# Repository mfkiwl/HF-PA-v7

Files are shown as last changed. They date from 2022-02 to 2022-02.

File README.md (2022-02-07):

### HF-PA-v3

VU3CER's Robust `Class-C / Class-D HF PA` for https://github.com/kholia/Easy-Digital-Beacons-v1
project for 40-20-17-15-12-10m bands - powered by RD16HHF1 RF MOSFET.

This design aspires to be the standard mW-to-QRP-Gallon HF PA in the ~1100 INR
(15 USD) design space.

If you are looking for a ~600 INR IRF510 design, please check out the
https://github.com/kholia/HF-PA-v5 project.

Design Constraints:

- PCB is to be homebrewed.

- PCB is single-sided - only one layer (side) is available for routing work.

- The "finals" MOSFET needs to be on an edge to allow usage of heatsinks.

- Typical external linears (e.g. `PA150 HF Linear Amp`) need 2W minimum to
  function. So we need a minimum of 2W of RF output from our design - even at
  28 MHz (10m).

- Minimal part count is strongly preferred. Low cost, and ease of availability
  are strong driving and deciding factors.

- Reproducibility is a MUST! We focus a lot on this aspect by documenting each,
  and every detail possible.

- Repairability in the field is a MUST!

  Dhiru's finding: Repairing homebrewed PCBs is so much easier, and fun than
  reworking commercial `lead-free` PTH PCBs.

- No moving mechanical parts are allowed in the design - this rules out usage
  of (failure-prone) active cooling options like fans.

Input: Few milliwatts is fine. Note: Si5351's output is around 8-10mW.

Output: To be done.

Robustness check: The PA works fine with 100% duty cycle for more than 8 hours!
In real-life, WSPR defaults to using ~2-minute TX intervals every 10 minutes.
FT8 is naturally gapped every ~15 seconds, and so on. We have also run FT8 on
this HF PA for more than a day at a time. The whole `HF PA v3` system is
thermally super stable.

Note 1: The output power is software controllable (via `PWM grounding`) for
flexibility.

Note 2: The idea behind making these (and my other) design notes publicly
available is to deliver REPRODUCIBLE, flexible, home-brewable, standardized,
reasonable, and cost-effective solutions for some common problems. I include
many references, simulations, and notes in my projects to enable you to do your
own (better) designs - do share them ;)

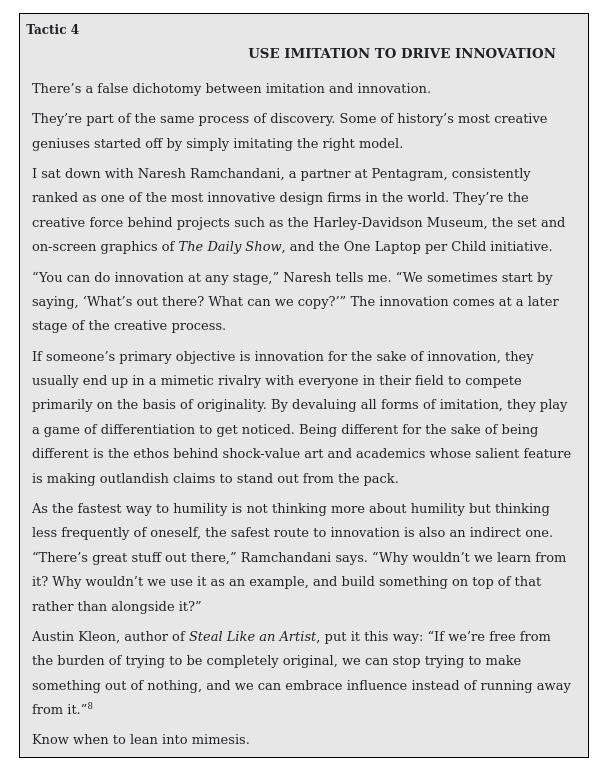
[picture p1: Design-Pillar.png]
Design Pillar


(Image Credit: `Wanting` book by Luke Burgis)

Note 3: All screenshots are clickable and zoomable.

Please see the older https://github.com/kholia/HF-PA-v2 project for the
power-supply (over-current protected)i design.

Schematic:

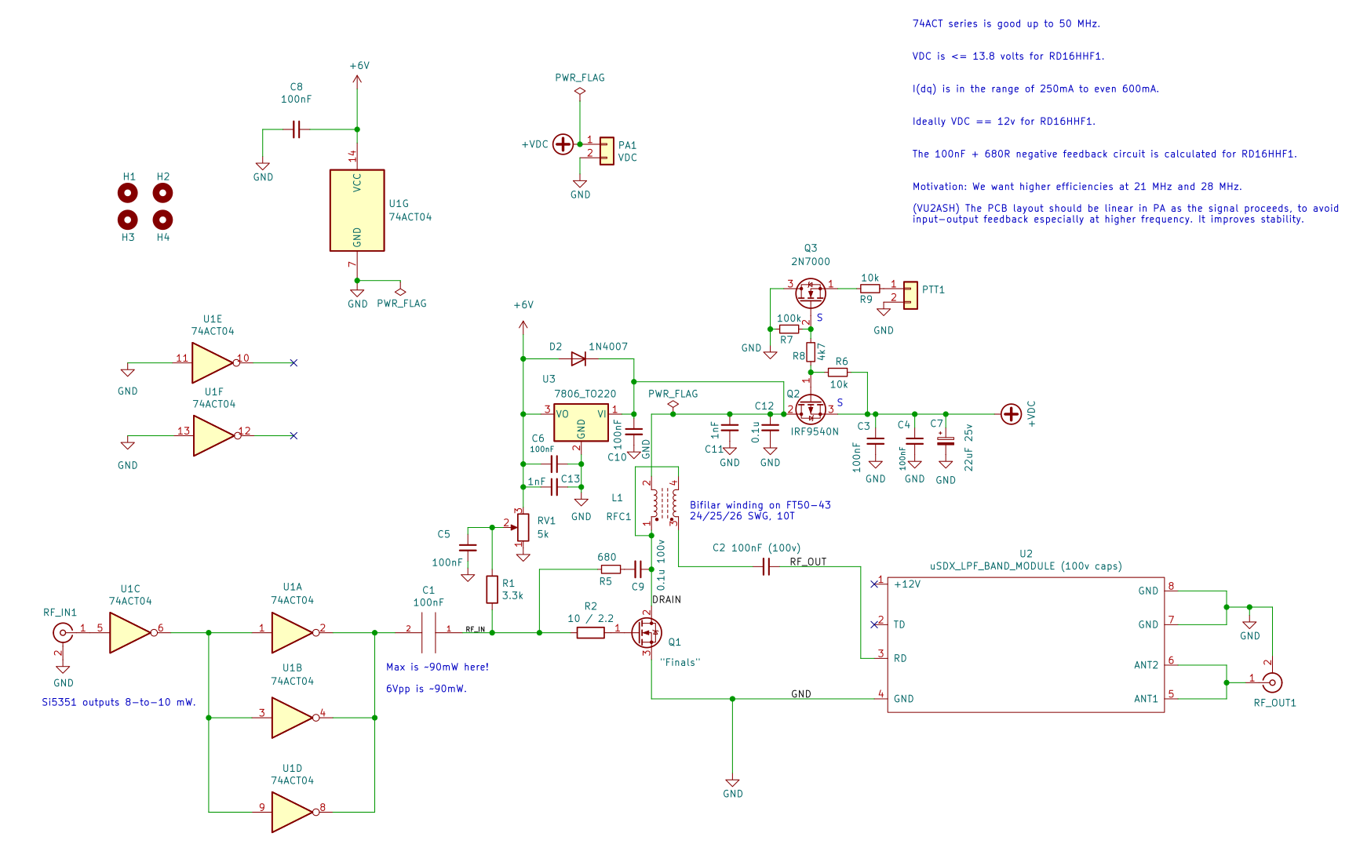
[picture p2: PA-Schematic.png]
HF-PA-v7 - PCB Schematic


PCB rendering:

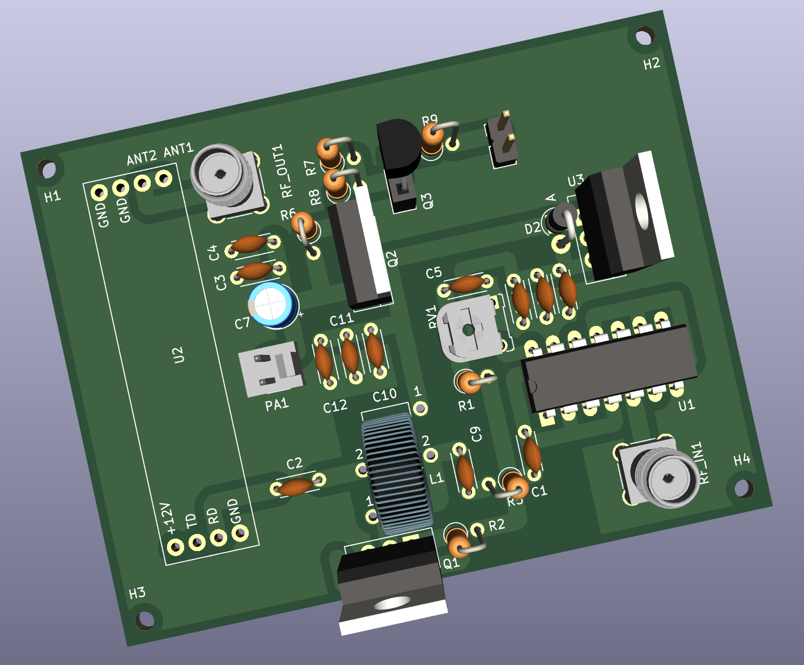
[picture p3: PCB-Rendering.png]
HF-PA-v7 - PCB Rendering


LPF rendering:

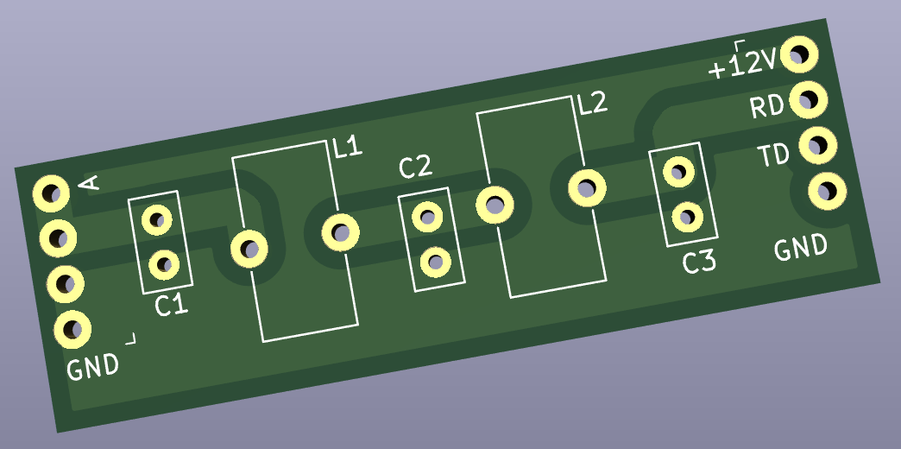
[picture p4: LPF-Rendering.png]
LPF - PCB Rendering


#### PA tuning process

- Remove the MOSFET from the TO-220 socket.

- Set the gate bias to a minimum (~0v).

- Enable PTT.

- Increase gate bias so that Idq (drain current) is in the range of 250mA to
  600mA for RD16HHF1.

- Turn off PTT.

- Connect the RD16HHF1 MOSFET back, enable PTT, enable RF input, and measure RF
  output.

Reference: http://www.carnut.info/WSPR_Tx/WSPR_Tx.htm

#### PA BOM

- 1 x SN74ACT04N (TI) - 65 INR

- 1 x RD16HHF1 - ~500 INR

  - Beware of fakes. Ensure proper sourcing (trusted supply chain, etc) to get
    genuine parts.

- 1 x IRF4905 OR IRF9540 P-Channel TO-220 MOSFET - 50 INR

- 5k Preset (Potentiometer) RM-065 - 15 to 20 INR

- 4 x 10k Ohm - 0.25W Metal Film Resistor - 10 INR

- 1 x 100k Ohm - 0.25W Metal Film Resistor - 5 INR

- 1 x 10 Ohm - 0.25W Metal Film Resistor - 5 INR

- 1 x 3.3k Ohm - 0.25W Metal Film Resistor - 5 INR

- 1 x 4.7k Ohm - 0.25W Metal Film Resistor - 5 INR

- A very large heat sink - 50 to 200 INR - larger heatsink is better!

- 1 x 7806 (TO-220 package from CDIL / ST) Voltage Regulator - 20 INR

- 2 x SMA connectors (PCB mount) - 50 INR

- 1 x 2N7000 TO-92 MOSFET - 10 INR

- 5 x 100nF (104) 50v Ceramic Capacitor - 15 INR

- 2 x 100nF (104) 100v Ceramic Capacitor - 15 INR

- 1 x 22uF 25v Electrolytic Capacitor - 5 INR

- 1 x FT50-43 (Black Toroid) - <= 30 INR

  Note: A bigger "FT68-43" toroid might be better at higher power levels.

- Misc: Relimate Connectors, Copper Clad PCB, Various Consumables (~100 INR)

- Tools: LCR-T4 Meter (for measuring things), RF Power Meter

- PA Total Cost: ~1100 INR

#### Power Supply BOM

See https://github.com/kholia/HF-PA-v2.

#### BOM + Equipment Sources

- https://www.semikart.com/ (IRF510, NP0 LPF caps - Kemet and others)

  - Multicomp Pro 100v C0G caps from Element14 are recommended

- https://www.semikart.com/search/SN74ACT04N

- https://www.electronicscomp.com/

  - IRF510 (Vishay), regular caps, ST voltage regulators

- https://www.electroncomponents.com/ (transistors, connectors, consumables, misc)

- https://www.sunrom.com/ (regular ceramic caps, SMA connectors, SIP socket strip)

- https://projectpoint.in/

  - Transistors, regular caps, voltage regulators, pots / trimmers, MFR resistors, misc

  - 2-Pin High Quality Relimate Connectors (all those 2-pin headers are actually Relimate Connectors)

  - Copper Magnetic Winding Wire

  - 3-Pin Relimate Cable Female to Female (High Quality 2500mA) - 'TO-220 socket'

- Semikart - Toroids

- https://www.techtonics.in - 300W DC-DC Buck Converter Constant Current Module

- eBay (`gr_makis`) - Toroids, RD16HHF1 MOSFETs

- https://www.sdr-kits.net/ - RD16HHF1 MOSFETs

- https://www.ktron.in/ (SMA connectors, excellent prices for many things)

- [LCR-T4 LCR Meter](https://www.techtonics.in/lcr-t4-12864-lcd-graphical-transistor-tester-resistance-capacitance-esr-scr-meter)

- [AVOID] https://www.fabtolab.com/78l05-voltage-regulator (https://www.ventor.co.in also works)

- https://robu.in/ (voltage boost module)

- https://indialocalshop.com/ - misc. hardware

- http://www.bhadraenclosures.com/ - excellent protected enclosures

Note for international buyers: The BOM can be carefully sourced via Mouser and DigiKey.

#### Notes

The included LPF module DOES NOT require the `same-side soldering` hack.

#### Tips

MOSFETs are sensitive with regards to ESD and high soldering temperatures. Use
best practices when dealing with MOSFETs and perhaps always ;)

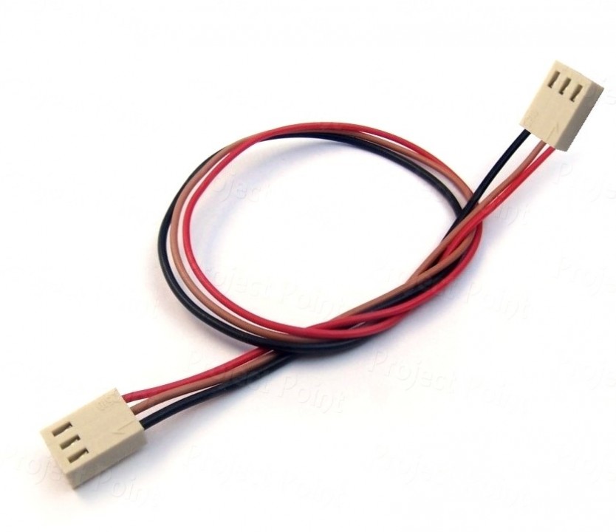
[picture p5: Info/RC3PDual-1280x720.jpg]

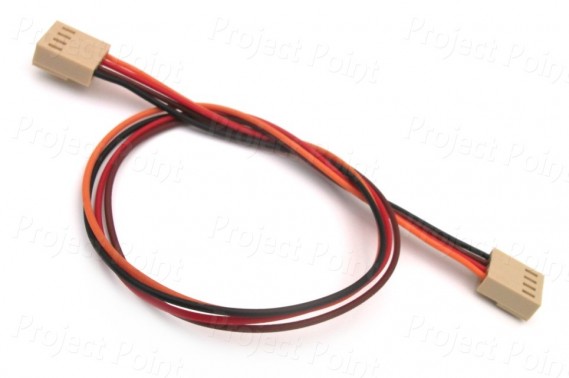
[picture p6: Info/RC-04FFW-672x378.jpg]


By using these `TO-220 Sockets`, we can easily support any MOSFET pinout. This
technique allows usage of `off-pcb` heat sinks with a lot of flexibility. It
also avoids common ESD + MOSFET problems as well. The gate bias can be easily
checked by safely removing the MOSFET from the TO-220 socket. Also, this socket
idea allows us to safely eliminate the LDO from the design.

`SN74ACT04N` can be driven at 6v - this is the secret LU2HES sauce! RF input
drive strength matters the most.

A burnt 78(L)05 regulator can easily eat up 4-5W of power by itself. If there
is no RF output but power is being consumed then check your linear regulator.

#### References

See [References.md](./References.md).

#### Credits

This design uses ideas from VU2ASH, HAMBREWERS, QRP Labs, Tom (AK2B), VK3PE,
and G6LBQ.

Also see https://github.com/kholia/HF-PA-v5#credits.

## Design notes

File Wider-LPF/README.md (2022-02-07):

180 pF can be replaced with 2 x 100 pF in parallel, if you don't have 180 pF
handy. 0.33 uH can be airwound or better use `9 turns` on T50-6 yellow toroid
(iron dust core) or `10 turns` on T37-6 yellow toroid (iron dust core).

Schematic

Results

Note: These filters were simulated with `QUCS` software.

https://www.ad5gg.com/2018/08/15/qucs-for-filter-design/

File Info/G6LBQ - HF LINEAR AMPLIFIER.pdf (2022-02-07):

# G6LBQ - HF LINEAR AMPLIFIER

# Last edited 10th April 2013

### Introduction

The G6LBQ HF Linear Amplifier is a reproducible 20Watt PA module using rugged Mitsubishi RF Mosfet's. There are many advantage of using genuine RF devices over cheaper general purpose power Mosfet's like the IRF510 devices commonly used in a lot of home-brew projects:

- 12 Volt drain voltage unlike IRF510's which typically require 24 Volts to operate well.
- Device source is connected directly to the metal mounting tab providing easier mounting options and more efficient thermal transfer.
- Flatter gain response across the HF frequency spectrum.
- Much better handling of poor mismatches.

The Linear Amplifier module has been designed to interface perfectly with the G6LBQ multiband transceiver but can also be used with the Bitx3 or any other transceiver project.

The RF drive level required for the module is around 10mw for an output power of 10 Watts. The maximum output that the module can deliver is 16 to 20 watts depending on bias and drive level. The amplifier has a front end 50 Ohms PI matching network which can be reconfigured to allow higher drive power levels if required providing greater flexibility for use with other projects.

There are many examples of proven designs using the Mitsubishi RF Mosfet's on the internet and also in various publications, the information I collected was used to aid in the design and construction of the G6LBQ amplifier module.

Currently the PCB artwork for the amplifier is not freely available however should you wish to make your own PCB for the module I have made the circuit diagram available in the G6LBQ Yahoo Group which can be found at http://uk.groups.yahoo.com/group/g6lbq/ look under the files section and then navigate to the G6LBQ Bitx folder.

As with all my other Multi-band BitX modules a ready made PCB is available from DX KITS the sole worldwide distributor. The PCB is a professionally manufactured Glass Epoxy FR4 board, pre drilled, tinned, solder masked and screen printed to aid assembly. To purchase a PCB please visit http://www.dxkits.com

### Page 1

COMPONENT LIST
Quantity | Description | Function
21 | 100nf Ceramic Disc or Multilayer 50-100 Volt – 5mm Lead Pitch | Coupling & Decoupling
2 | 10nf Ceramic Disc or Multilayer 50-100 Volt – 5mm Lead Pitch | Coupling & Decoupling
2 | 1uf Electrolytic 25-63 Volt – 2.54mm Lead Pitch | Decoupling
1 | 100uf Electrolytic 25-35 Volt – 5mm Lead Pitch | Supply LF Decoupling
1 | 150pF Multilayer Ceramic or Silver Mica 100 Volt – Lead Pitch Form To Suit | Frequency Tuning.
2 | 430 Ohm 0.25W Resistors | Input Attenuator/Matching.
2 | 10R 0.25W Resistors | Input Attenuator/Matching & 5Volt Regulator supply feed resistor.
1 | 10K 0.25W Resistor | BC640 emitter base resistor.
1 | 1K 0.25W Resistors | BC640 base resistor.
1 | 2K2 0.25W Resistor | 2N3904 base resistor.
1 | 2K7 0.25W Resistor | 78L05 load resistor.
1 | 470R 0.25W Resistor | Driver transistor bias feed resistor.
2 | 100R 0.25W Resistors | Output transistors bias feed resistor.
3 | 10K Horizontal Pre-sets | Driver/Output transistor bias setting.
1 | 560R 0.25W Resistor | Driver transistor feedback network.
2 | 680R 0.25W Resistors | Output transistor feedback network.
1 | 6R8 0.5W Resistor | Driver transistor supply resistor.
2 | 2R2 0.25W Resistors | Output transistor Gate resistors.
1 | BC640 PNP Silicon Transistor | PSU series transistor feeding the 78L05 biasing regulator.
1 | 2N3904 NPN Silicon Transistor | Transmit bias switching transistor.
2 | 1N4001 General Purpose Diodes | Bias temp compensation.
1 | 1N4148 High Speed Switching Diode | Transient suppression for relays.
1 | 78L05 5Volt Positive Regulator | Bias voltage regulation.
1 | RD06HHF1 or RD16HHF1 RF Power Mosfet | Driver stage Mosfet transistor.
2 | RD16HHF1 RF Power Mosfet's | Output stage Mosfet transistors.
2 | Omron G5V-2 Two Pole Relays | Input/Output switching.
3 | BN43-202 Ferrite Balun core | RF Transformers.
2 | Ferroxcube VK200 Choke Inductors or FT50-43 torroids with 10 turns of 0.7mm copper enamel wire. You can also use large ferrite beads with 0.7mm wire passed through. | Supply decoupling chokes.

### Page 2

HARDWARE LIST
Quantity | Description | Function
5 | SMA PCB Sockets “See Page ” | RF Input/Output option 1
5 | 2 Pin Molex 0.1 pitch headers “See Page “ | RF Input/Output option 2
1 | 2 Pin Molex 0.1 pitch headers | Transmit switch line connection
1 | 2 Pole PCB Screw Terminal Block | PSU connection
1 | Heat-sink | Heat dissipater for RF Mosfet's
1 | 0.5mm Copper enamel covered wire | For winding transformers
1 | 0.7mm Copper enamel covered wire | Only needed if winding L1 & L2 as opposed to using pre made inductors.

# BUILDING THE G6LBQ HF LINEAR AMPLIFIER

Construction of the G6LBQ HF Linear Amplifier should not prove difficult and is one of the easiest modules to construct in the multi-band transceiver.

Before commencing construction carry out an inventory of all parts and optional hardware.

Please visit the BitX Yahoo Group at http://uk.groups.yahoo.com/group/g6lbq/ and make sure you have the latest documentation before commencing building. There is a folder in the files section of the group titled G6LBQ Bitx and all files relating to the amplifier can be found there.

There is no specific order of construction but I suggest all the resistors and capacitors be soldered to the PCB first. The last components to be installed should be the three RF Mosfet's as these could be damaged if the device legs are allowed to be bent with unnecessary disturbance during construction.

The finished PCB looks like this:

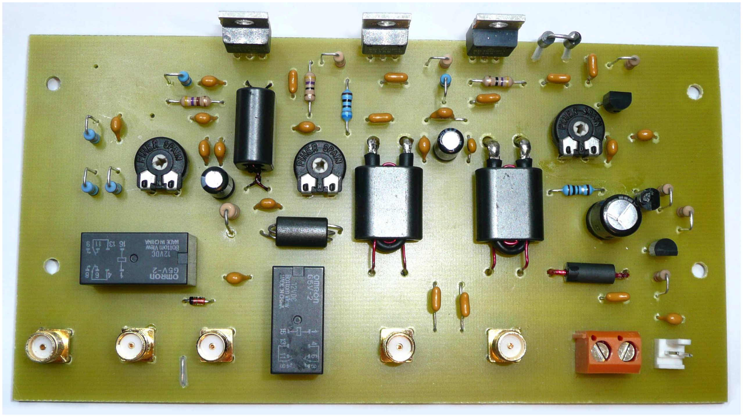
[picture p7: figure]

### Page 3

# PCB LAYOUT IMAGE

### This image illustrates all the component locations to aid construction NOTE A wire link must be fitted at this location

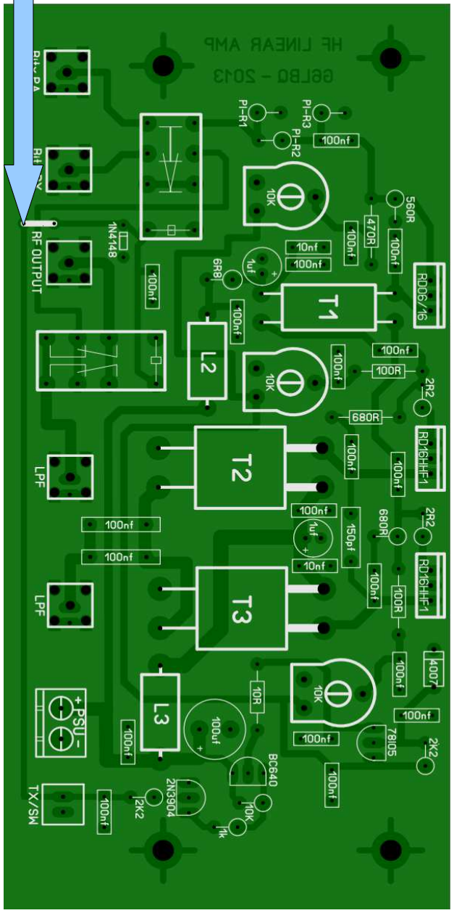
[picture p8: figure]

### Page 4

# WINDING THE TRANSFORMERS

The HF Linear Amplifier is equipped with three transformers which are wound on BN43-202 ferrite balun cores using 0.5mm Copper Enamelled Wire and short pieces of RG174 coax.

### T1 Driver Transformer

T1 is constructed by winding two lengths of 0.5mm enamel copper wire twisted together so there are 2 to 3

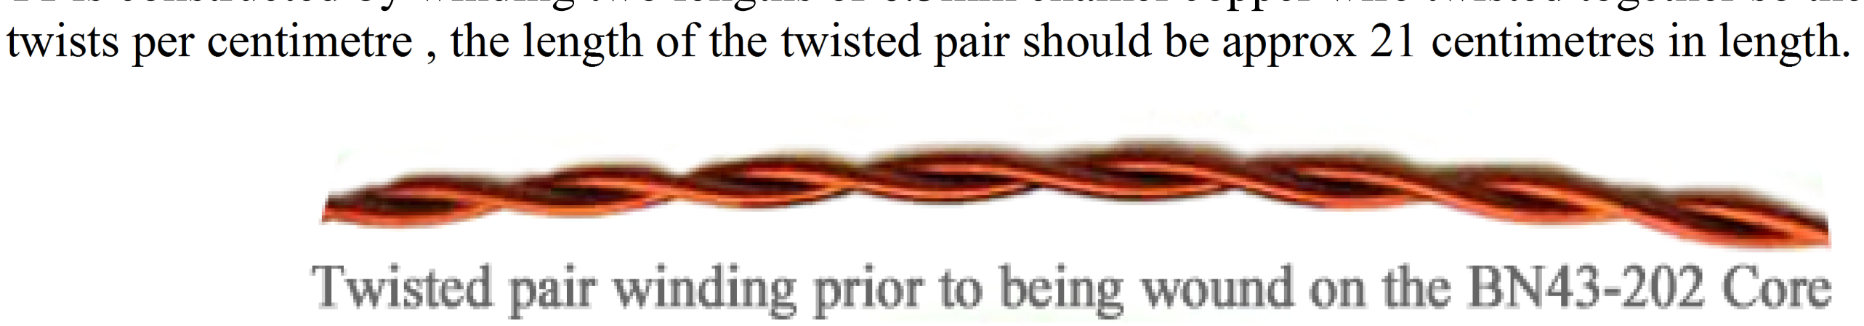
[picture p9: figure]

The twisted pair of wires must now pass through the BN43-202 balun cores so that it fills one hole in the core twice and the other three times (2 ½ Turns) this is illustrated below:

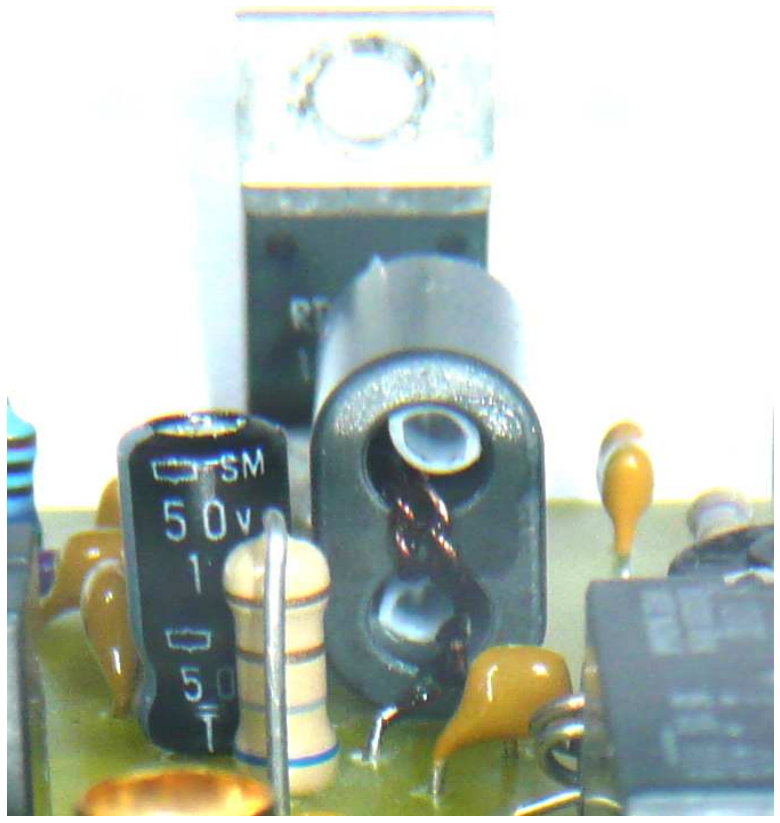
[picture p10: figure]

In the image above you can see that the top hole in the balun core has been filled with the twisted pair twice whilst the bottom hole in the core has been filled three times. The little pieces of white tubing inside the cores is only in place to help highlight the windings and are not required!

The transformer can be inserted into the PCB either way round as it is symmetrical.

### Page 5

### T2 & T3 Output Transformers

T2 & 3 are identical and are constructed with individual primary and secondary windings. The primary winding is created from a short length of RG174 coax and the secondary with a length of 0.5 enamel copper wire.

Begin by winding the secondary side of the transformers with 4 turns of copper enamel wire so that the windings are nice and tight against the centre of the BN43-202 core as illustrated below:

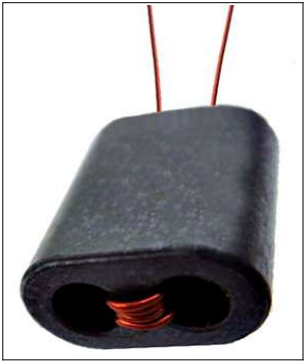
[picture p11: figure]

To make the primary winding take approximately 10cms of RG174 coax and remove 2cm of the outer plastic sheathing from one end, separate the exposed outer braid to reveal the centre coax core, the centre core can make threading the coax through the binocular holes tight so it is discarded by simply pulling it free from the rest of the cable. With the centre core of the coax removed chop off the 2cm of exposed braid as this will make it easier to thread the coax through the binocular holes. Thread the coax through the core and prepare as illustrated below:

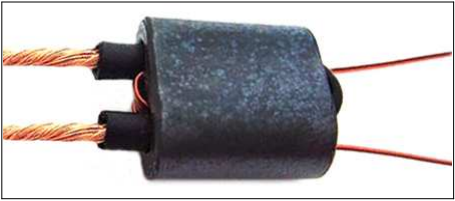
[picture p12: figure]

With the three transformers wound it is important to clean off the enamel coating from the copper wires ends prior to PCB installation. Use a sharp blade to do this then pre tin all of the cleaned wire ends, DO NOT TIN THE RG174 COAX prior to installing into the PCB as this will make it difficult to form the wire ends to the PCB holes.

### Page 6

# MOSFET BIAS TEMPERATURE COMPENSATION

The following image illustrates the two 1N4001 Diodes used for the bias compensation, these Diodes must be mounted on the same heat-sink as the RF Mosfets and secured in place.

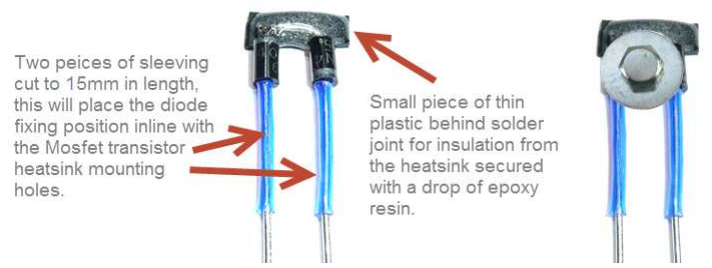
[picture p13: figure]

With a suitable aluminium enclosure it may be possible to get enough heat dissipation by bolting the RF Mosfet's and Diodes directly to the case. Care must be taken when bolting the Diodes down, they must be lightly secured in place but make contact with the aluminium dissipater, do not apply to much pressure against the Diodes or damage may occur!. A suitable washer must be included with the fixing screw to cover the Diode bodies and aid contact with the heat dissipater.

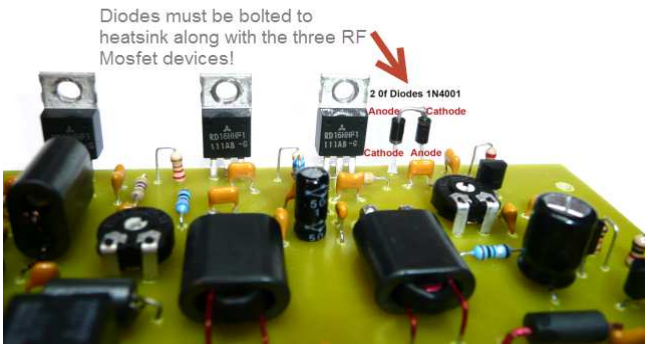
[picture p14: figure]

Attach the RF Mosfet's and Diodes to the heat-sink with a thin layer of heat-sink compound and then carefully check around the Diodes to make sure no part of the fixing screw or component legs are making contact with the aluminium dissipater.

### Page 7

# INITIAL TESTING STAGE

## IMPORTANT Do not apply power to the finished module without a suitable heat-sink attached to the RF Mosfet's & bias compensation Diodes!

### Preparing for initial testing and bias adjustment

Before applying any power to the finished module check the PCB for correct component locations, solder splashes and shorts.

The three 10K pre-set resistors that control the biasing must be initially set so the Mosfet's transistors are unbiased, observe the image below and set all three pre-sets anticlockwise:

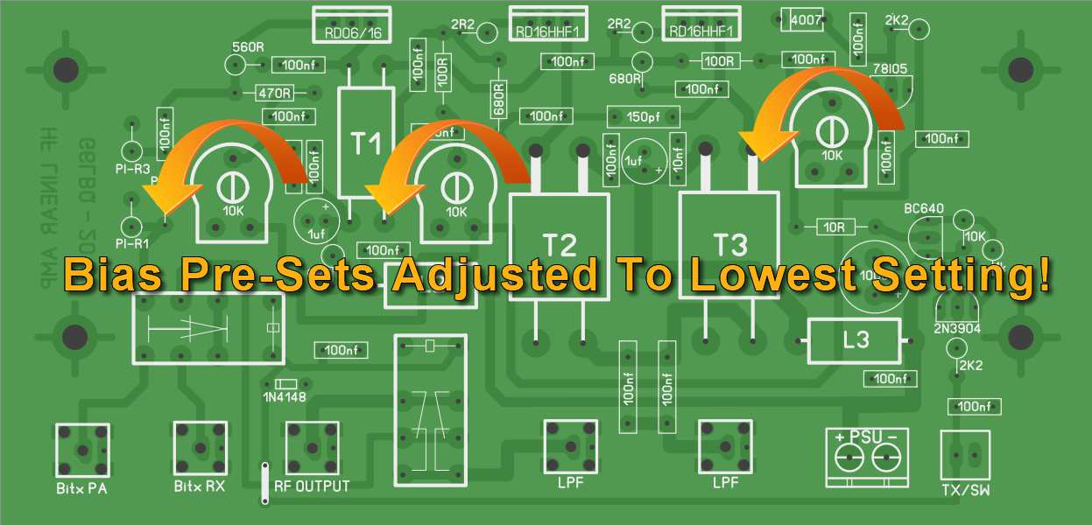
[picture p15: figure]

With the three 10K pre-sets adjusted as above and a suitable heat-sink in place we are now ready to carry out some initial tests and bias alignment. No RF input signal, low pass filters or output load are required during the initial test and bias alignment stages.

### First Test - Standby Idle Current

With a 12 to 13.8 volt power supply connected to the amplifier the measured idle current should be approximately 35mA.

### Page 8

### Initial testing and bias adjustment continued

### Second Test – Transmit Mode Current

With a 12 to 13.8 volt power supply connected to the amplifier module we need to activate the TX/SW (transmit switch) circuit, this turns on the bias regulator and activates the signal path changeover relays. The illustration below shows the additional test link required to activate the transmit switch:

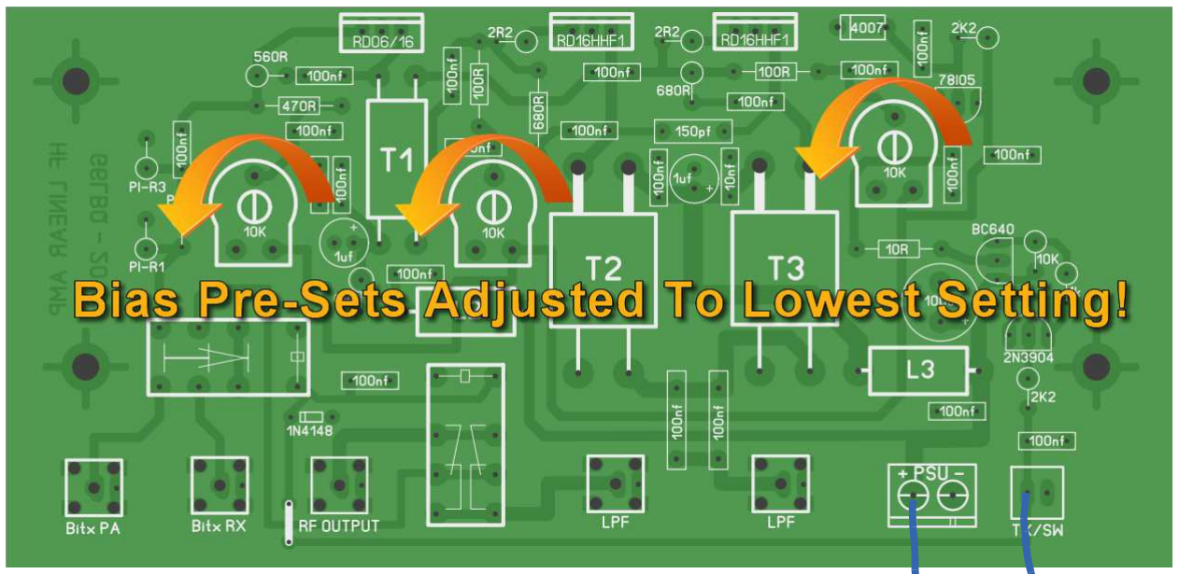
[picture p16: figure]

The transmit switch circuit is operated by + 13.8 Volts so in the illustration we are linking the switch straight terminal to the main power supply feed to force operation.

The measured current for this test should be approximately 120mA +/- 10%.

### Page 9

# DRIVER STAGE BIAS ADJUSTMENT

## IMPORTANT Do not apply power to the finished module without a suitable heatsink attached to the RF Mosfets & bias compensation Diodes!

### Setting the driver stage bias

The driver stage is biased to 125mA and the illustration below indicates which of the three pre-sets controls the driver stage bias:

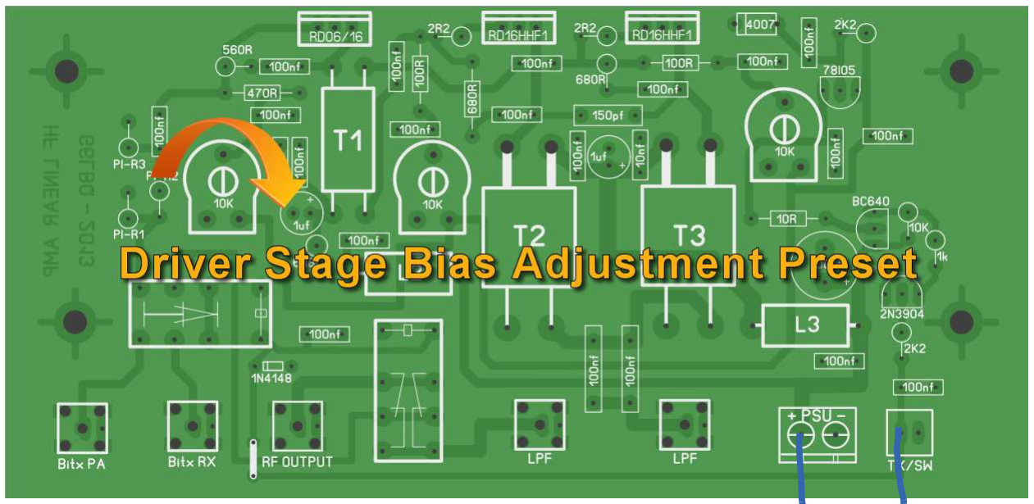
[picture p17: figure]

Whilst monitoring the current consumption of the amplifier slowly adjust the driver stage pre-set in the direction shown for a reading of 245mA, the driver stage is now biased.

### Page 10

# OUTPUT STAGE BIAS ADJUSTMENT

## IMPORTANT Do not apply power to the finished module without a suitable heat-sink attached to the RF Mosfets & bias compensation Diodes!

### Output stage bias adjustments

The final output stage consists of a pair of Mosfet devices each biased to 250ma. Using the illustration below the first output device is biased accordingly:

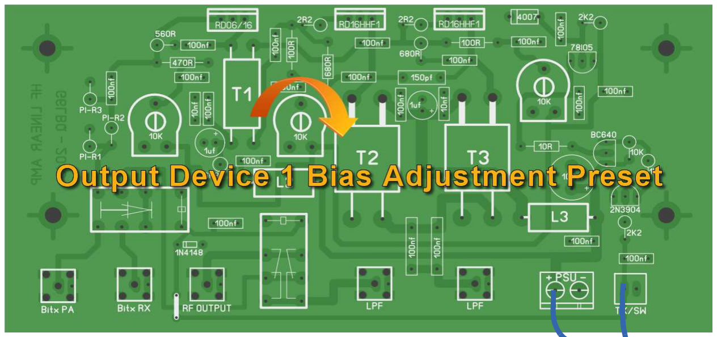
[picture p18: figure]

Whilst monitoring the current consumption of the amplifier slowly adjust the first output device pre-set in the direction shown for a reading of 495mA, the first output device is now biased.

Using the illustration below the second output device is biased accordingly:

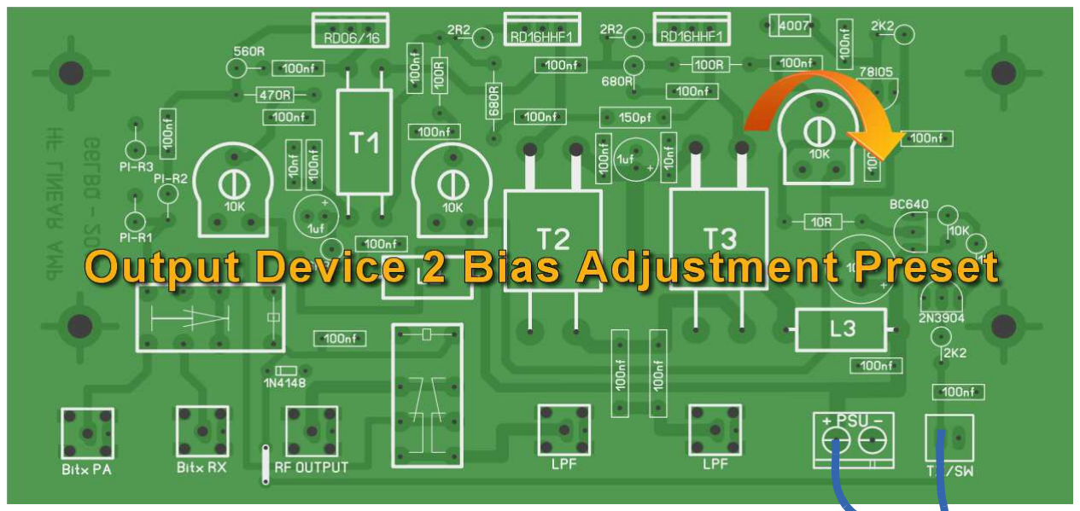
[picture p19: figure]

Whilst monitoring the current consumption of the amplifier slowly adjust the second output device pre-set in the direction shown for a reading of 745mA, this completes the bias setting procedure.

### Page 11

# A UNIVERSAL APPROACH

### Connectivity

The HF Linear amplifier was designed with a universal approach and is adaptable to many home-brew projects requiring a reliable, solid and reproduce-able module.

- The PCB has provision for various RF input/output connectivity, you can fit high quality SMA connectors, Molex connectors or just solder straight to the PCB.
- There are separate input connectors for receive and transmit making the module ideal for use with separate transmitters and receivers
- The module has a transmit switch line that removes the bias during receive mode thus conserving energy, ideal for battery portable operation!
- On-board input matching PI network/attenuator – this allows the module to be configured for a wide range of power input levels and allows control of the final output power.

### Heat-sinks

The output devices and bias compensation diodes are all mounted along the back edge of the PCB which offers great flexibility when sourcing a heat-sink, some aluminium project cases may also serve as a good enough heatsink on there own!.

### Transmit Switching

The amplifier was primarily designed to compliment my G6LBQ Multiband BitX transceiver so has positive going transmit switching, there is a 2 pin header on the PCB marked TX/SW.

### Page 12

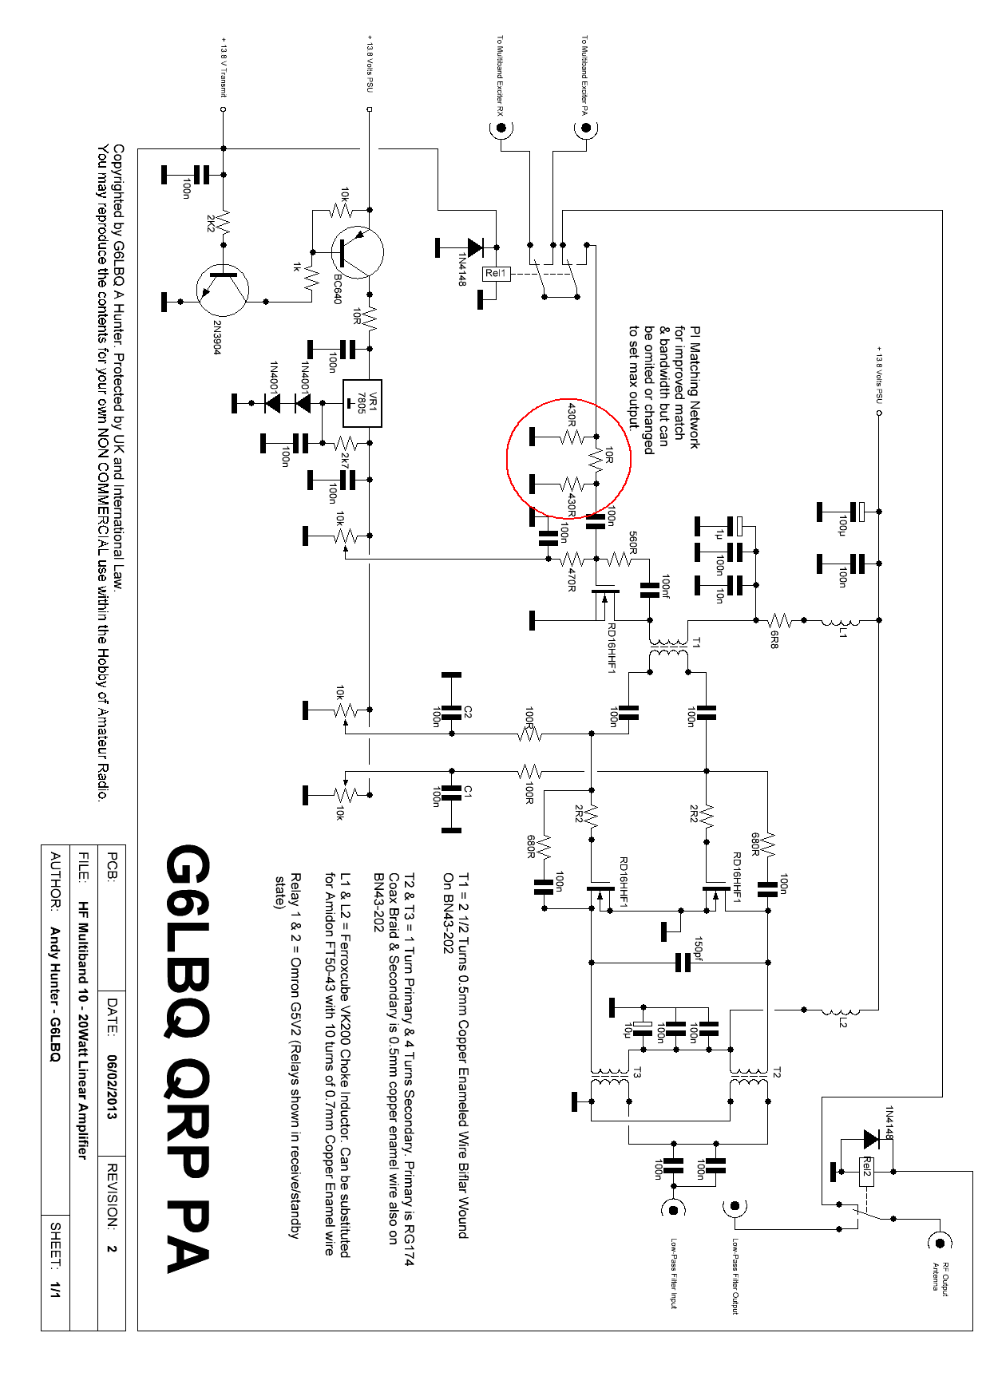
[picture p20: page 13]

### Page 12

# FINAL NOTES & AMMENDMANTS

This manual should provide sufficient information to construct the amplifier but if you have any questions during the build please post a message in the BitX Yahoo Group at http://uk.groups.yahoo.com/group/g6lbq/

It is recommended that the power supply feed to the amplifier be fused, a 2.5 Amp quick blow fuse should be adequate.

Copyrighted by G6LBQ A Hunter. Protected by UK and International Law.
You may reproduce the contents for your own NON COMMERCIAL use within the Hobby of Amateur Radio.
Page 13 | Last page

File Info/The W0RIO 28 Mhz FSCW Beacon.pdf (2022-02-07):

# The W0RIO 28 Mhz FSCW Beacon

(C) 2015, G. Forrest Cook, W0RIO (formerly WB0RIO)
The W0RIO 28 Mhz FSCW Beacon | http://www.solorb.com/elect/hamcirc/28mbeacon1/

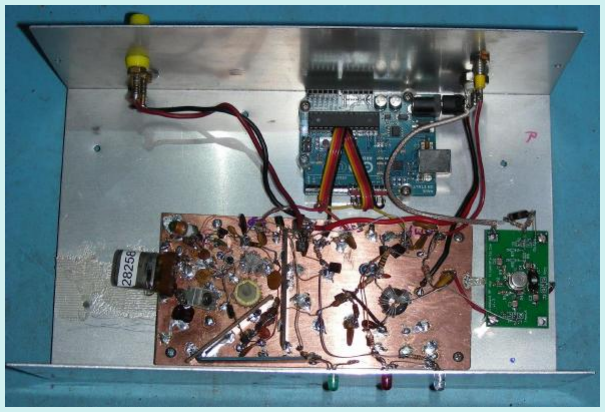
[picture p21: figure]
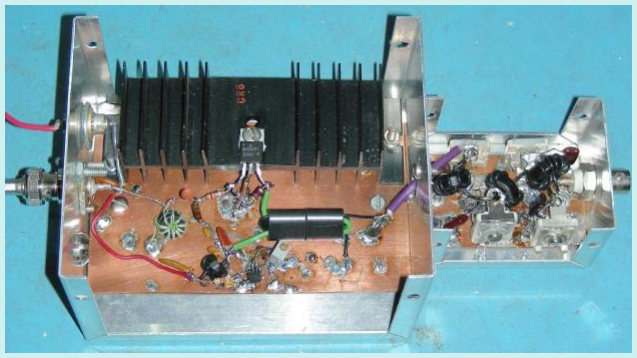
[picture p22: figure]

1 of 4 | 1/26/22, 13:06

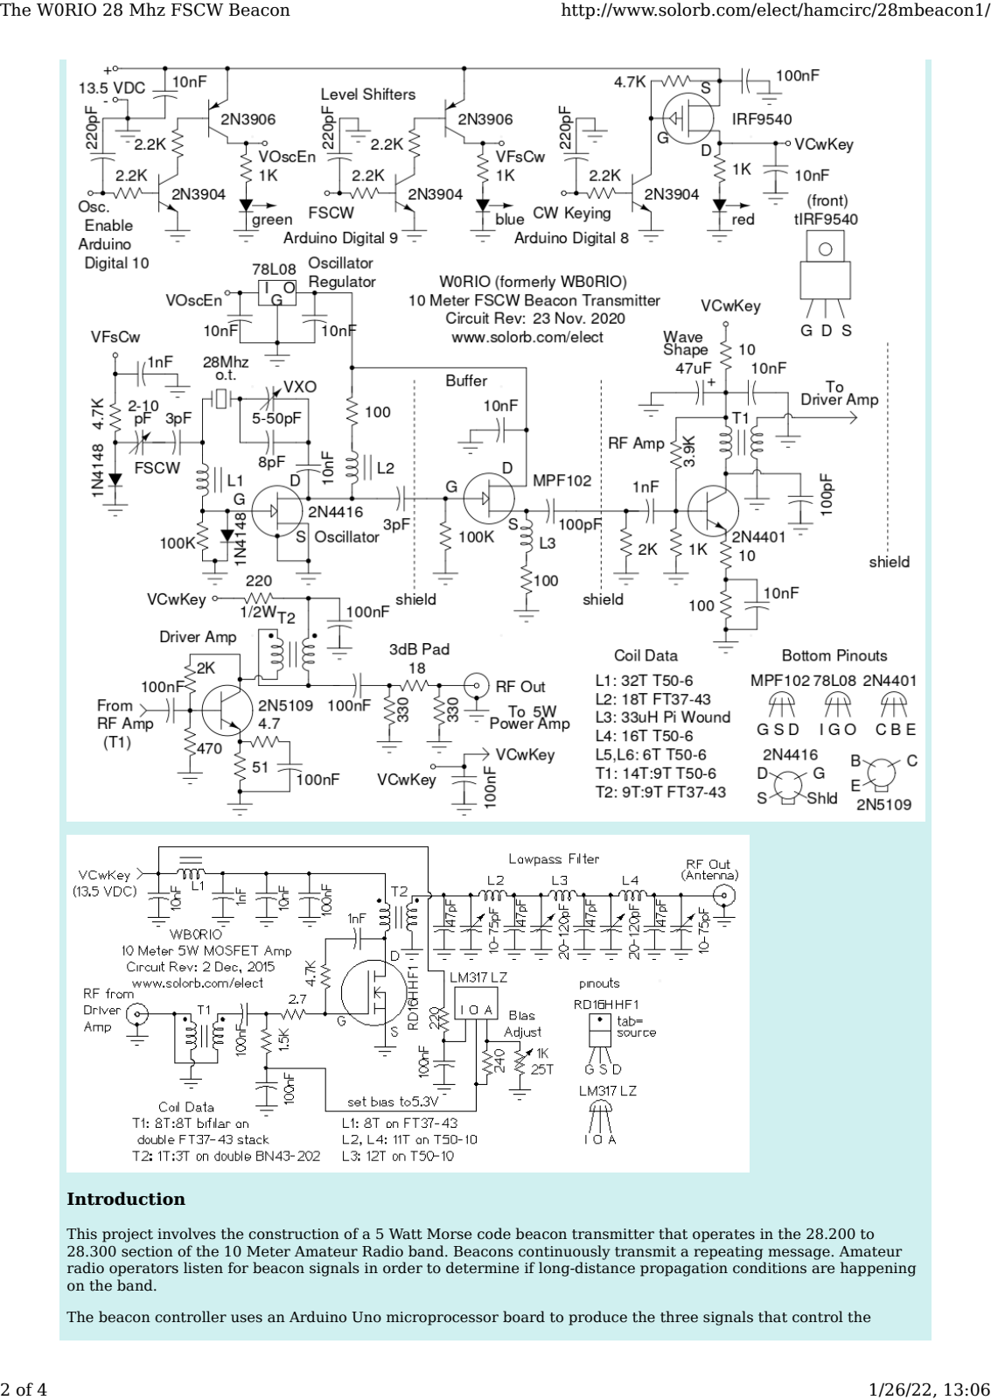
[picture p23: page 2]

### Introduction

This project involves the construction of a 5 Watt Morse code beacon transmitter that operates in the 28.200 to 28.300 section of the 10 Meter Amateur Radio band. Beacons continuously transmit a repeating message. Amateur radio operators listen for beacon signals in order to determine if long-distance propagation conditions are happening on the band.

The beacon controller uses an Arduino Uno microprocessor board to produce the three signals that control the transmitter. The project is also an experiment in using Frequency Shifting CW (http://www.solorb.com/elect/hamcirc/fscw/) (FSCW), or two-tone Morse code. After the listener goes through a bit of a learning curve, FSCW can be decoded more easily than regular Morse code when low signal to noise conditions exist.

### Theory

The Arduino microprocessor is programmed with this simple Arduino beacon sketch. (http://www.solorb.com/elect/hamcirc/28mbeacon1/CWBeacon101.ino) The sketch contains a generic test message. A custom message with your own call sign can be created with the CW2hex software from my beacon keyer (http://www.solorb.com/elect/hamcirc/beacon/) project.

The three control signals from the Arduino include Osc. Enable (Digital 10), FSCW (Digital 9) and CW Keying (Digital 8). The beacon transmitter and the Arduino are both powered by a 12VDC (nominal) power source. At 13VDC, the idle current for the Arduino and transmitter is 45mA and the active current is 160mA.

A small solar power system could be used to provide the 12VDC used by this device. To further reduce the beacon's power consumption, it should be possible to remove the Arduino Atmel processor chip from the Arduino board and run the chip with some minimal support circuitry. This LFO project (http://www.solorb.com/elect/musiccirc/ArduinoLFO2/) is an example of a stand-alone Arduino processor chip.

Three level-shifting circuits are used to convert the 0-5V control signals into 0-12V signals for operating the transmitter. The first two level shifters use a 2N2904 transistor to activate a 2N3906 transistor. The third level shifter replaces the 2N3906 with an IRF9540 P-channel MOSFET. The MOSFET has a lower voltage drop than the 2N3906 which maximizes the RF power output from the power amp. An IRFD9010 was originally used here, but the IRF9540 has a lower on-state resistance which helps to increase the power output from the RF amp.

The oscillator circut uses a 28 Mhz overtone crystal in a Pierce configuration. The basic circuit was found in the ARRL publication: W1FB's QRP Notebook. The oscillator features a VXO capacitor for adjusting the base frequency and an FSCW control input was added to allow for lowering the frequency during dashes. Note that there is a typo in the W1FB schematic, the impedance of L1 should be around 1.3K, not the 1.3 ohms shown. Testing at 28 Mhz showed that an L1 impedance of around 1K produced a more stable VXO range.

Several different oscillator circuits were tried before using the Pierce circuit. Its output level is lower, but it produces much less harmonic energy. Some oscillator configurations may cause the overtone crystal to oscillate at a different resonance frequency.

A 28.258 Mhz (nominal) overtone-type crystal was used in the oscillator, the actual VXO frequency range was 28.269 Mhz to 28.273 Mhz. eBay can sometimes be a good place to find 28 Mhz crystals.

The output of the VXO is sent to an MPF102 FET buffer circuit. The buffer has negative gain, but it greatly reduces the oscillator frequency shift between key-up and key-down conditions. Both the Oscillator and Buffer circuits are powered by a 78L08 voltage regulator which increases the oscillator's frequency stability.

The first RF Amp stage uses a 2N4401 transistor biased to run in class A. This stage boosts the 28 Mhz signal up enough to drive the power amp. The RF Amp's output is fed through a tuned RF transformer to reduce undesired harmonics. The collector circuit on the RF Amp includes a simple RC waveshaping network to eliminate keying clicks.

The RF Driver Amp uses the Kits and Parts.com (http://kitsandparts.com/) Version 1.3 Wideband RF Amp kit. They also sell the toroid cores used in this project. The driver amp uses a 2N5109 transistor biased to run in class A. The amp's output is lowered to the level required by the RF power amp by using a 220 ohm resistor in series with the VCwKey supply. The 3dB pad on the output of the amplifier stabilizes the input of the power amp.

The RF Power Amp uses a Mitsubishi RD16HHF1 MOSFET transistor as the active device, it is available from RF Parts Company. (https://www.rfparts.com/) The MOSFET is biased to run in class A when transmitting. The power to this stage is keyed so that it does not consume power when it is idle. Transformer T1 raises the impedance of the 50 ohm driver amp signal to better match the impedance of the MOSFET's gate. Transformer T2 raises the impedance of the MOSFET's drain circuit to match the input impedance of the low pass filter.

The 1nF capacitor and 4.7K resistor across the MOSFET gate and drain provide a small amount of negative feedback which lowers the amplifier's distortion. The LM317 LZ variable voltage regulator provides an adjustable bias voltage for the MOSFET transistor.

The output of the RF Power amp is fed through a 7 element low-pass filter to reduce the harmonic output level. When the low-pass filter is properly adjusted, the first harmonic is about 44dB below the carrier and the second harmonic is 60dB below. Common lowpass filter designs found on the net use fixed capacitors and inductors. Those circuits would work here, but having adjustable capacitors allows the amplifier to be tweaked for lower harmonics and higher power. Both type 10 and type 6 powdered iron cores were tried in this filter, similar results were found. If you use T50-6 cores, the turns counts should be 9-10-9 compared to the 11-12-11 for the T50-10 cores.

### Construction

The level shifters, oscillator, buffer and RF Amp stages were built on a single piece of blank circuit board material using the ugly construction method. Many of the oscillator's components were physically stabilized by using 10M 1/2W resistors as standoffs, the oscillator coils were secured to the circuit board with hot-glue.

Small strips of blank circuit board material were soldered vertically to the main board to act as circuit isolation shields. Shields were placed between the oscillator and buffer and the buffer and the RF Amp.

The Power Amp was installed in a separate metal box. BNC connectors were used for the input and output terminals and the VCwKey signal was sent through a feed-through capacitor and ferrite bead mounted on the box. A separate ground connection is run between the power supply and the RF Amp box to provide good current flow and maximum power output. The MOSFET transistor is bolted to a fairly large aluminum heat sink, heat conducting grease should be used between the transistor and heat sink.

The low-pass filter was contructed in a small metal box that was mounted on the side of the power amp box, the photo of the amp shows an earlier version of the circuit where the low-pass components were mounted inside of the power amp box.

### Alignment

The RF Power Amp's bias adjustment should be set for 5.25V before doing any other testing on the beacon. Beware that adjusting the bias much higher than this will cause the RF output transistor to run hot or possibly burn up. If the heat sink becomes too hot to touch, reduce the bias voltage.

Connect the RF Out signal to a 50 ohm dummy load and place a high impedance oscilloscope probe across the load. An oscilloscope with a minimum of 100 Mhz of bandwidth should be used to monitor the output signal. Adjust the four variable low-pass filter capacitors for the highest amplitude and the most pure sine-wave output waveform. The capacitors are interactive and the adjustments should be made several times.

Most beacon messages start with a solid tone, followed by the station ID and grid-square location. During the tone part of the message, use a calibrated receiver to adjust the VXO control for the desired base frequency. Adjust the FSCW control while the Morse code message is being sent. The FSCW shift should typically be set somewhere between 25 Hz and 50 Hz. Tune the receiver so that it produces a fairly low tone, around 500 Hz. Adjust the FSCW control until the change in the tone of the dashes is noticeable.

### Putting it On The Air

The beacon transmitter should be connected to an antenna that is resonant at or near the beacon's transmit frequency. An antenna analyzer or SWR meter may be used to adjust the antenna resonance. Use the shortest feedline possible to reduce power losses. Most beacon transmitters use a vertical antenna for an omnidirectional radiation pattern. Once the transmitter is operational, it is a good idea to monitor the signal from a distance using a mobile receiver or ask a nearby ham friend to give you a signal report.

The FSCW beacon is intermittantly operated at 28.2715 Mhz, typically from dawn to dusk. The current message is roughly: *tone* DE W0RIO/B W0RIO/B DM79IX *pause* *tone* DE W0RIO/B /FSCW DM79IX *pause*. The message alternates once with FSCW off and once with it on, the non-FSCW version with the double call sign helps automated beacon tracking stations pick up and report the signal. Reception reports are always appreciated.

Bill Hays, Amateur radio station WJ50, is the former IARU Region 2 beacon coordinator. He has provided a web page with all kinds of 10 meter beacon information, (https://www.qsl.net/wj5o/) including a list of active beacons. New beacons in the US should register their transmitter with the current coordinator Dennice Stice (WI5V).

I have been experimenting with using my DAS1 Dark Activated Switch (http://www.solorb.com/elect/solarcirc/das1/index.html) kit to activate the beacon only during daylight hours. The DAS1 requires a simple modification to turn it into a Light Activated Switch.

Back (http://www.solorb.com/elect/hamcirc/) to FC's Ham Radio Circuits page.

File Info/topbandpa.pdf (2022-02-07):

Simple 1.9MHz Power Amplifier
G4JNT April 2009

This started out as a quick throw-together design to get a WSPR beacon running on 1840kHz without tying up the main shack rig. The signal is generated directly from a DDS/PIC/GPS combination http://www.g4jnt.com/WSPRBCNS.ZIP but after building it, I found it worked better than designed, to such an extent that something odd is happening that at some point needs further investigation

Notably :
It gives out considerably more power than it was designed for
Efficiency is appreciably better than may be expected for a class-C design.

Design Process :

I wanted a simple class-C PA to give about 10 Watts out, say 12 Watts to allow for O/P filter losses. It had to run from a nominal 13V supply and a low cost switching type Mosfet was the obvious choice for the PA. I had several IRF540 devices, which have a low on resistance (50m-ohms) and rated at 100V so should give a safe voltage margin. Current is rated at 33A max.

First the O/P matching network :

### 10 Watts from a 12V rail needs RL = 12²

/ (2 * 10) = 7.2Ω
With a 13V rail, Pout for this RL will be around 12 Watts

Remembering back to the distant past where such PAs were commonplace, I recalled a Q of 5 to 6 was stated as being typical for solid-state tank circuits so an L-C-C network transforming 50Ω to 7.2Ω with this Q was derived. Values came out to be L = 3.6uH, Cshunt = 1220pF Cseries = 700pF for use at 1840kHz

At RL = 7Ω the DC supply choke needs to be of the order of 5 – 10 times this value, and for convenience I used the same value as the tank L – 3.6uH

Drive Circuitry :

Drive was kept simple, with all six paralleled gates of a hex-inverter chip, driven by a Schmitt input buffer to make absolutely sure there could be no instability at zero drive level. According to the data sheet the IRF540 would switch quite happily at 5V – certainly so at the modest current it is running at here. A preset was added at the input to allow optimum setting of input bias for minimum drive level, and might offer the opportunity to alter the drive duty cycle.

The drive to the FET was taken through a DC restoration capacitor / diode to ensure that if the HC04 chip should sit at a logic ‘1’, the device wouldn’t be turned hard on, shorting the power supply.

Breadboard :

A breadboard was put together as shown below (also at | http://www.g4jnt.com/ClassCPA.gif )

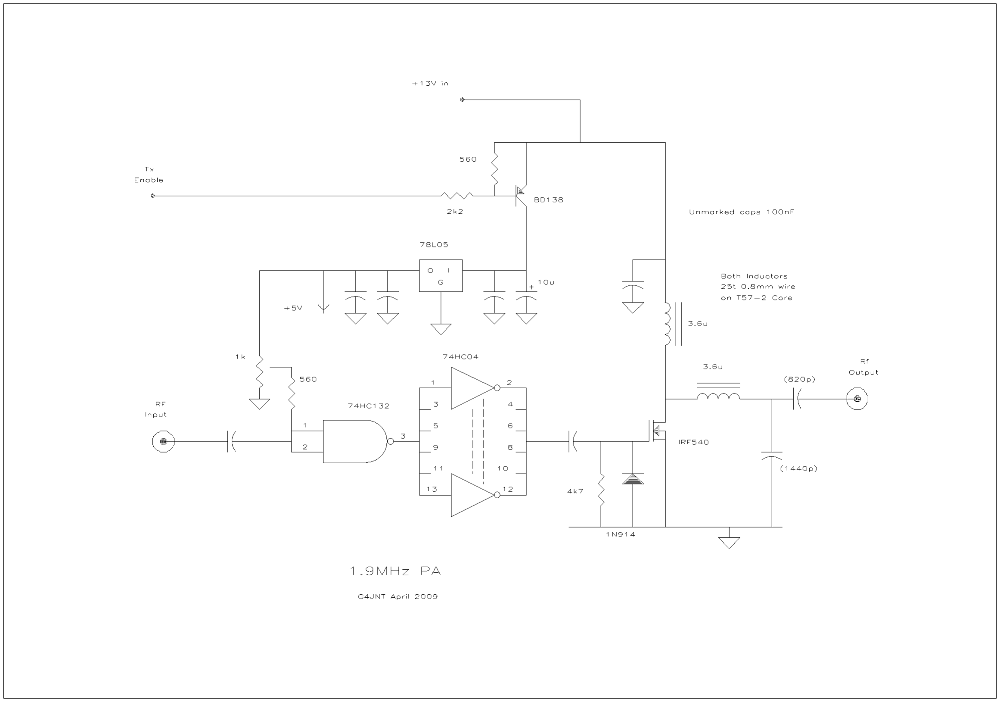
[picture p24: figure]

On testing a few big surprises came to light. | The PA worked best at a frequency
appreciably higher than it was designed for, giving maximum power at around 2MHz rather than 1.84MHz. In fact at 1.84MHz the output was rather messy, with some spurious / instability present. At 2MHz it was giving a very clean output and the power being supplied to the load was over 30 Watts !

Also, the device was running rather cooler that I might have expected, so measured the DC-RF conversion efficiency. Slightly more than 75%

Probing the voltage waveforms showed that the output of the 74HC132 buffer was very close to a squarewave as intended, but the output of the HC04 devices, and the waveform on the FET gate had an extended duty-cycle, of about 70% - in other words it was being kept turned on even after the drive had fallen away.

The waveform at the drain of the FET was the biggest surprise. It consisted of a more-or-less square topped spike of 100 Volts for about 20% of the RF cycles, falling back to close to zero until the device turned on properly at the 50% point where drain volts really went to zero. It is presumably this spike, being fed back through the drain-gate capacitance and adding to the end of the drive on-period that is giving the unexpected high duty cycle gate / drive waveform.

Now, as we have a 20% duty cycle 100V spike hitting the L-C-C combination, this presumably accounts for the higher than expected output power.

Practical end-product:

As I wanted a PA for transmitting with, and had better things to do than spend ages trying to understand just how exactly this thing was working, I scaled the C values in the matching network from 2 to 1.84MHz, tested it at this frequency (worked fine, 30 Watts, clean). Added a 5th order 2.1MHz elliptic filter (¹
) and put it on air. Pout was now a little over 25 Watts. The new capacitor values are those shown in the circuit diagram.

Explanations & queries :

- The 100V spike is exactly as would be seen in a flyback topology Switch Mode PSU.
- but with a 3.6uH inductor, a Von duration of 0.6us would only allow a peak current of 1.7A to build up. So continuous mode has to be assumed (in flyback topology ?)
- With a non-sinusoidal drive the output matching network presents a higher impedance at harmonics.
- Efficiency is better that the traditionally quoted 66 – 70% of a class C design, so is this more like class D / E / F …..Z or whatever!
- Both output inductors were running quite hot, in fact they were the hottest components altogether and could have been dissipating a watt or two each Bigger cores would probably give even higher efficiency.

1
The Low Pass Filter was already built and had been designed for high power use, originally for the GB3SSS beacon at Poldhu.

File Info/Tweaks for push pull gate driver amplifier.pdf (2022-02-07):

thestone.zone (http://thestone.zone/radio/2021/01/16/minor-enhancements.html)

## Tweaks for push pull gate driver amplifier

6-7 minutes

Continuing from my successful attack on thermal issues, (http://thestone.zone/radio/2021/01/14/capacitors.html) I did some more measurements of the amplifier. I’ve now tweaked a few things that improved some more issues. The result is a little more power, a little better efficiency, and some improved (and safer) operation.

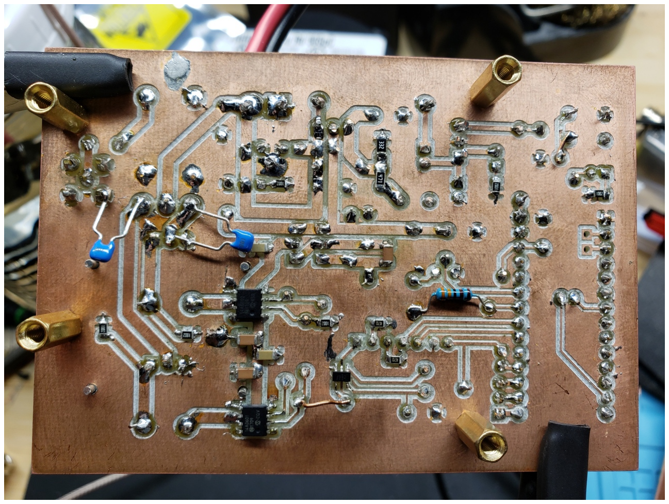
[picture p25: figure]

### Parasitic oscillations

The first thing I noticed when I started more organized

Tweaks for push pull gate driver amplifier | about:reader?url=http%3A%2F%2Fthestone.zone%2Fr...
1 of 6 | 11/4/21, 14:09

measurement of the amplifier is that the IRF510 drain waveforms exhibited some wild oscillations. I am kicking myself because I didn’t take a picture of the waveforms before I worked out a fix, but imagine you have a decent 7MHz square wave, but with a 20 Vpp 52MHz sine wave superimposed on it. Yuck.

Looking through the ARRL handbook, chapter 17, which discusses handling parasitic oscillations, I worked out what my options might be. I didn’t think I could fit a ferrite bead on the drain, and I didn’t want to try to add some negative feedback. One of the handbook’s suggestions looked quite feasible – bodging in a capacitor on the drain:

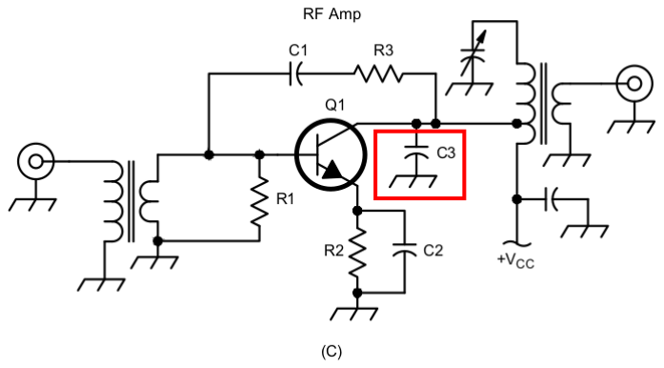
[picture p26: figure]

Since I just learned some things about capacitors, (http://thestone.zone/radio/2021/01/14/capacitors.html) I thought I should put one of my new TDK 450v NP0 capacitors in there. I only have two values to choose from (690pF and 1nF). Figuring the oscillations measured 52MHz on the oscilloscope, the 1nF value seemed like it might be a good choice, at 22R at 7MHz and 3R at 52MHz. Through the transformer, I guess my load is about 5-6 ohms, and the output impedance should be quite low on the IRF510s, so I thought this matched the handbook’s suggestions as well as I could.

Once I added the capacitors, the oscillations were basically gone (OK, there’s a little wiggle in one of them, but not nearly what it was!). What was more interesting was a concomitant increase in power, and a drop in total current consumption by the amplifier:

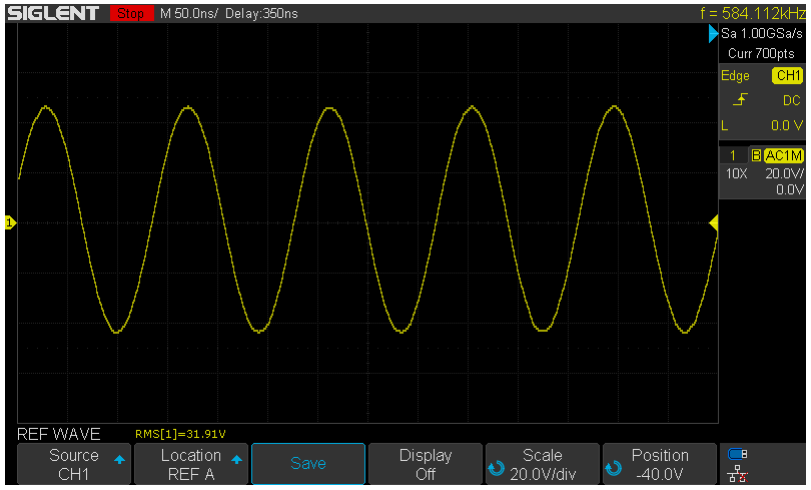
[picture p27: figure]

This yielded a decent 19 watts of output at about 56% efficiency – up 3 watts and 10 points!

### Pull downs on the gate drivers

Another thing I noticed with repeated testing was that every time I would power the board, there would be a burst of current draw. I reasoned this was because the MCP14A0601 (https://www.mouser.com/datasheet/2/268/20005593A-1082549.pdf) has internal pullups for its ENABLE pins:

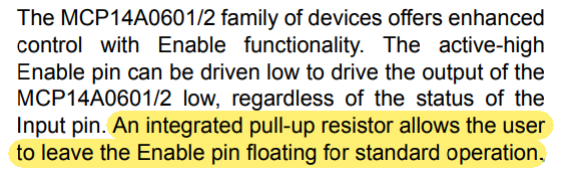
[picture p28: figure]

This means on power up they are turned on, and with the default startup state of the Teensy LC’s output pins, it happens that “no signal” is very briefly passed to the inverting gate driver, which slams its transistor on. It didn’t cause any damage because this pulse was very brief (just long enough for the microcontroller program to set the pin states to their proper defaults).

But it was annoying and unsightly, so I added a pull-down resistor to the ENABLE signal into the gate drivers. According to the datasheet, the integrated pullups are “typically” 1.8
megohms. I went with 6.8 kilohm resistors for my bodge pulldowns, so my resistors would win in that little tug of war. This cured the board of this startup behavior, and I feel a lot happier with this configuration.

### Squaring up the gate driver input

A much earlier test board with the MCP14A0601 had made me a little leary of passing the local oscillator directly into the gate drivers. I had observed some instability, and I wasn’t sure if there was some oscillation at these frequencies. So I’d tentatively put a 47 ohm resistor inline between the two. Well, after scoping the traces, I saw that this was making the signal a very slewed sawtooth wave. So I bypassed this resistor (R6 on the schematic), and it square up nicely.

### Duty cycle issue remains

In testing with my previous iteration of the amplifier (a single IRF510 and gate driver), I had found that the gate drivers increase their duty cycle as the frequency goes up. In that testing, I’d found that these work OK at 7MHz, but at higher frequencies (e.g., 14MHz), they became fairly unusable. The duty cycle issue is still there, and can be seen in the following image from the oscilloscope:

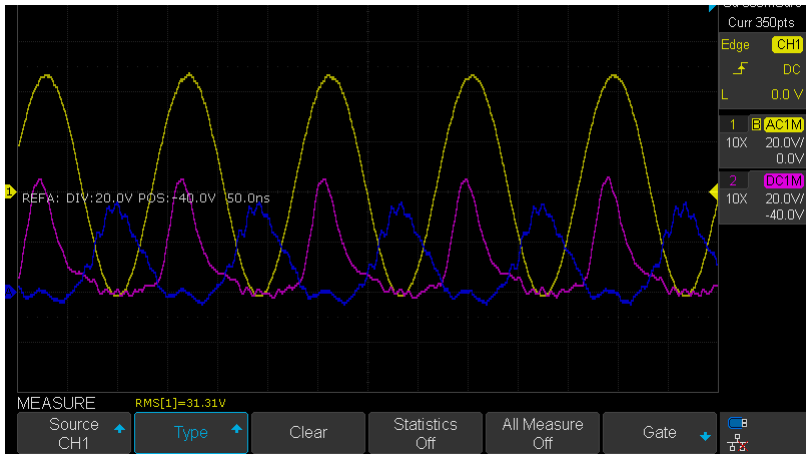
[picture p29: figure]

Notice how each drain (the magenta and blue waveforms) spends more time at low voltage than at high voltage… this is directly because of a similar duty cycle issue from the gate drivers.

For now, I’m getting 55% efficiency or better, and getting an unbelievable 18 watts out of this amplifier at 12v supply. If I go forward with this design to make a 40m transceiver, it will be perfectly fine. It will exceed my own expectations for my first “full suite transceiver” project.

But, in the future I may want to follow through with one of my ideas earlier – experiment with different gate drivers and see if there is one that might do better at higher HF frequencies. I’ve even noticed some of them have both an inverting and non-inverting output in a single chip, which could reduce parts count by one whole chip (more than making up for the slight increase in price for those fancier chips).

We’ll see… I kind of like these gate drivers, and if nothing else I’m making amplifiers that don’t look like other ones I see, so I’ll keep playing with the idea.

### Conclusions

With this testing, I think my search for a power amplifier chain for my mid-term portable digital mode transceiver project is at an end. I’m happy to proceed with a 40m solution, and the output level is more than adequate. I also suspect some things will clean up a bit when I make a 4-layer PCB with a proper ground plane. Since I’ve observed and fixed a few parasitic oscillation issues, I know what allowances to make in a final build, so I think this is buttoned up quite nicely.

Up next is to start learning receiver stuff. I’d previously played with a Tayloe detector, but I’ve been reading up on more traditional single conversion superheterodyne designs lately. I might put together a couple side-by-side receiver builds and see which direction seems best for my first transceiver project.

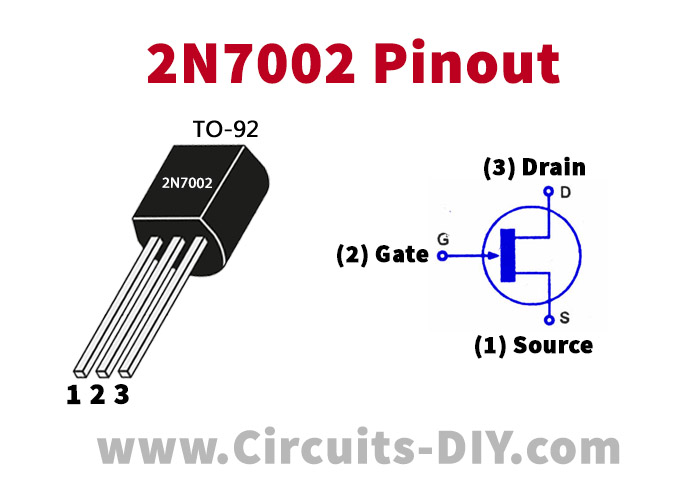
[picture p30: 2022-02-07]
datasheets/2N7002-Pinout.jpg

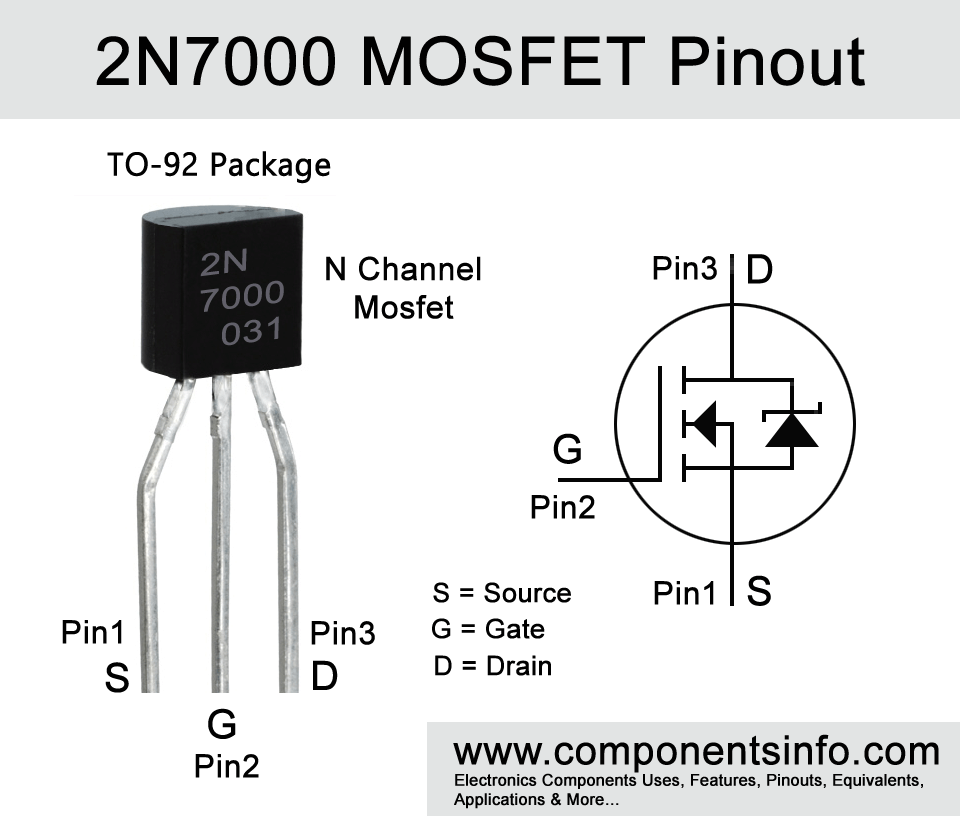
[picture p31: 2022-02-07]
datasheets/2n7000-pinout-datasheet.gif

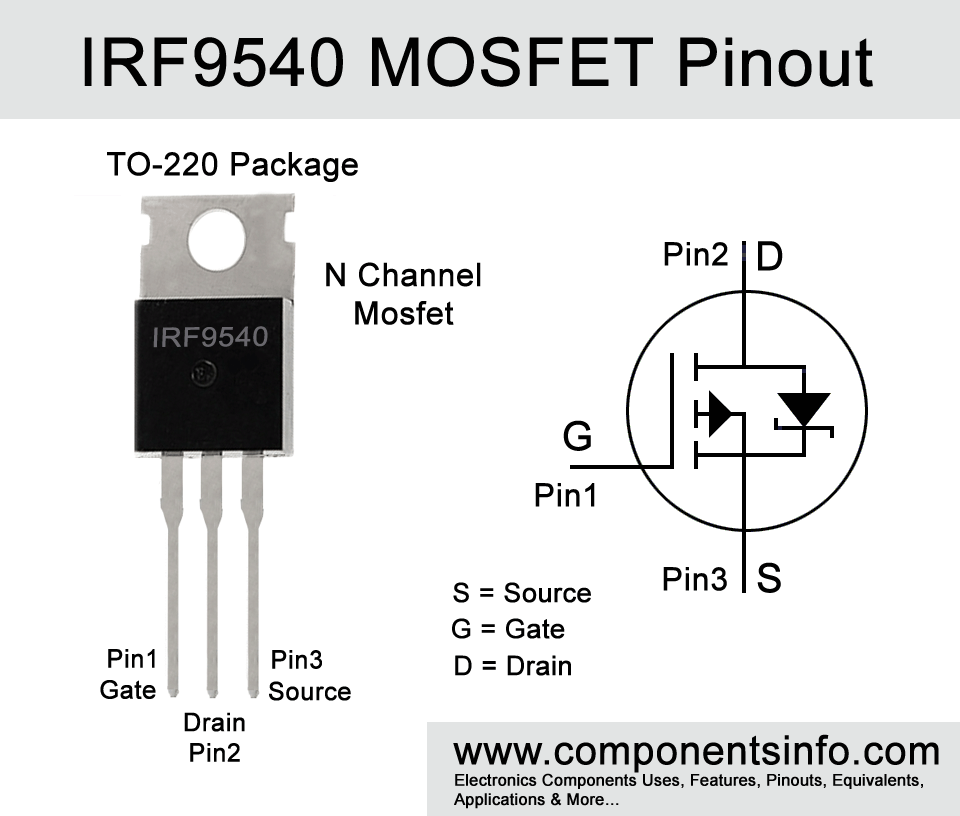
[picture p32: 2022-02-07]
datasheets/irf9540-mosfet-pinout-equivalent.gif

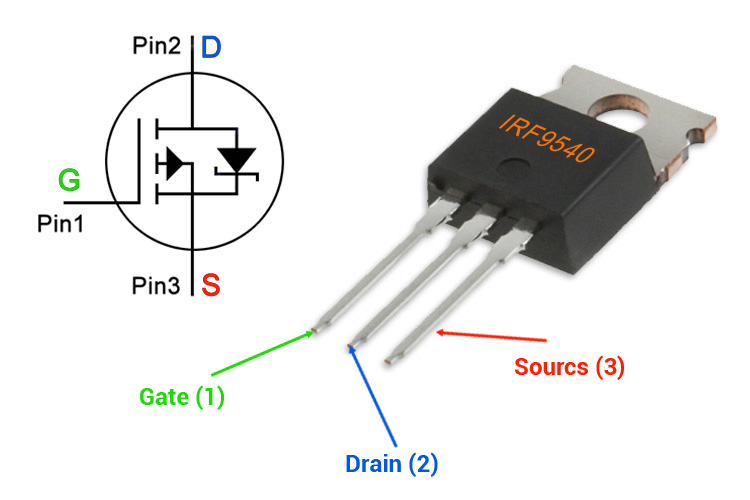
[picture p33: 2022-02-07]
datasheets/IRF9540-Pinout.jpg

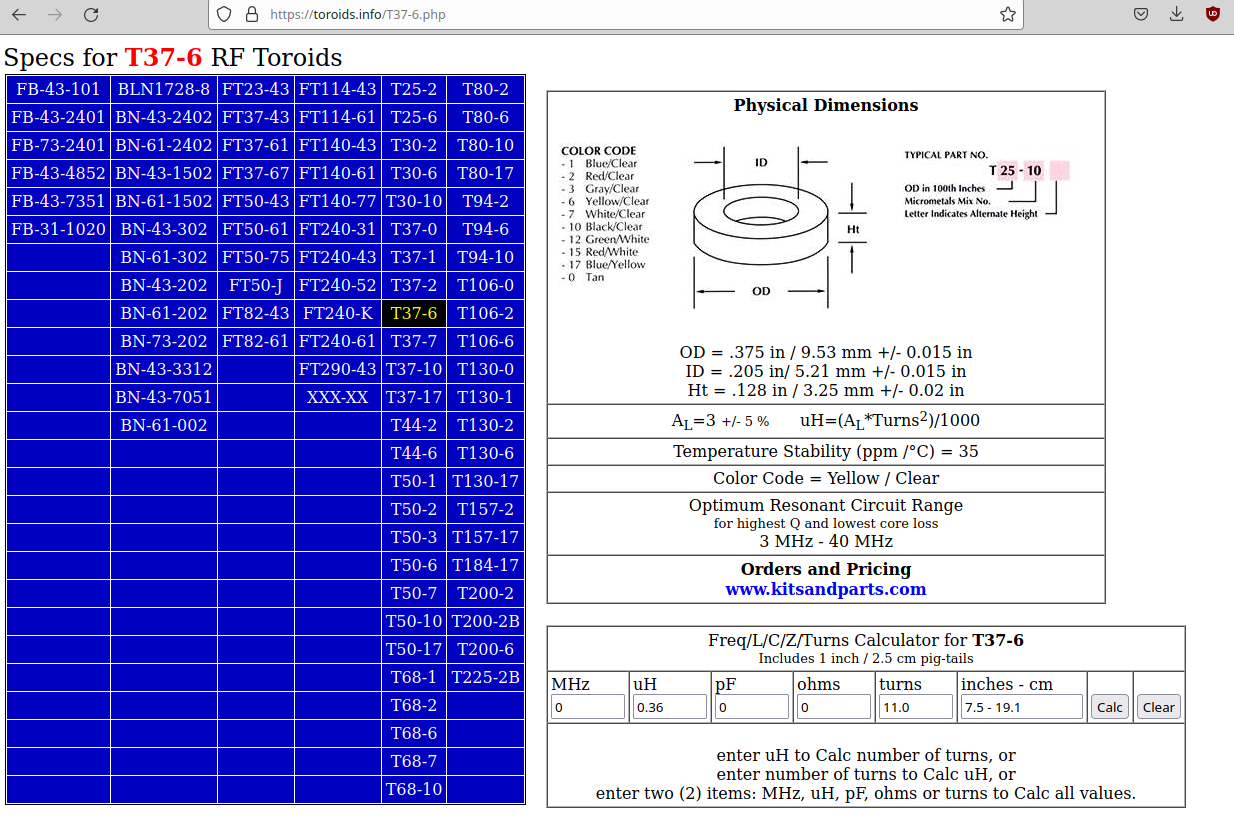
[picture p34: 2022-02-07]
Wider-LPF/Screenshot_2021-10-15_14-21-57.png

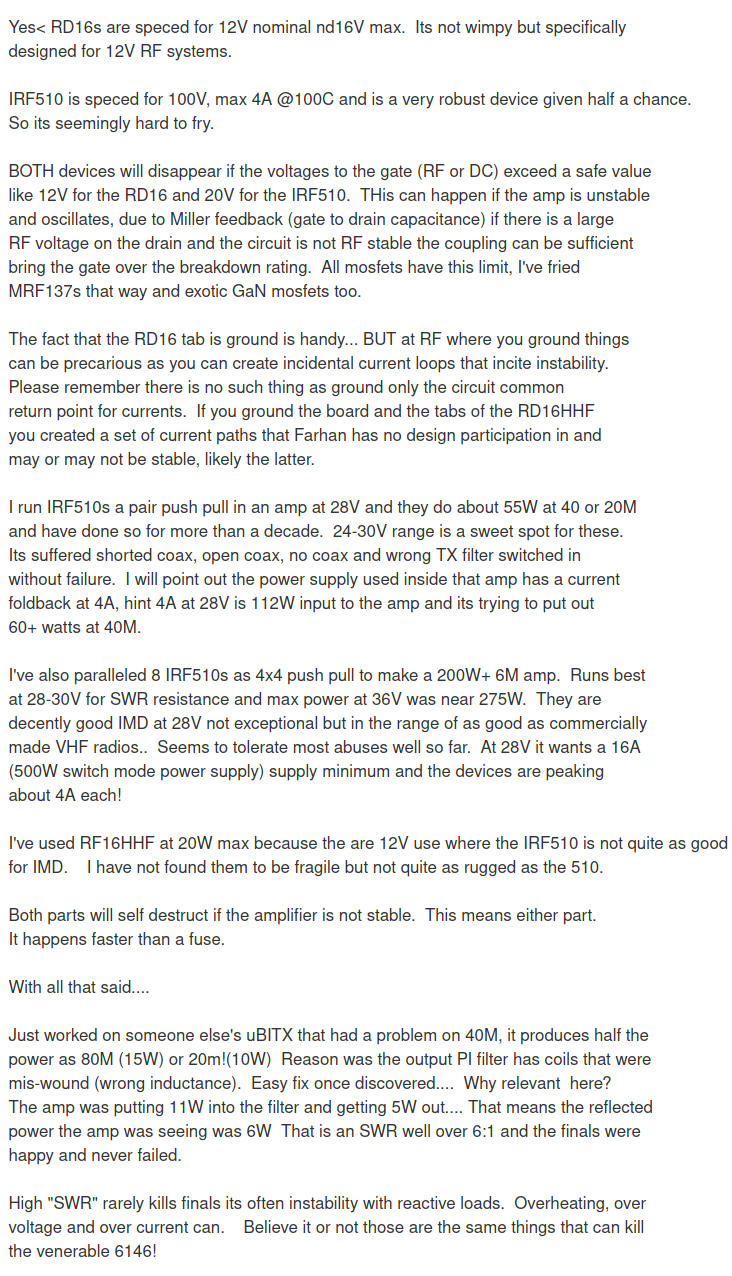
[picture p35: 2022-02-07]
Info/KB1GMX note.png

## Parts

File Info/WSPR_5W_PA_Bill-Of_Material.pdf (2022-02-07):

Sheet1

# 5W PA for WSPR Ultimate

vk3pe | Feb-16

"0805-1206" means most footprints can be fitted, 0805 preffered though

Part Type | Designator | Footprint | Description | Notes
1.09uH | L1 | T50_TOROID | Inductor | for 30M band (refer to Ultimate web page for other band values)
1.09uH | L2 | T50_TOROID | Inductor | for 30M band (refer to Ultimate web page for other band values)
1.257uH | L3 | T50_TOROID | Inductor | for 30M band (refer to Ultimate web page for other band values)
270pF | C17 | 0805-1206 | Capacitor | for 30M band (refer to Ultimate web page for other band values)
270pF | C16 | 0805-1206 | Capacitor | for 30M band (refer to Ultimate web page for other band values)
560pF | C14 | 0805-1206 | Capacitor | for 30M band (refer to Ultimate web page for other band values)
560pF | C15 | 0805-1206 | Capacitor | for 30M band (refer to Ultimate web page for other band values)
100K | R5 | 0805-1206 | RES FIXED
100nF | C6 | 0805-1206 | Capacitor
100nF | C5 | 0805-1206 | Capacitor
100nF | C4 | 0805-1206 | Capacitor
100nF | C11 | 0805-1206 | Capacitor
100nF | C7 | 0805-1206 | Capacitor
100nF | C8 | 0805-1206 | Capacitor
100nF | C9 | 0805-1206 | Capacitor
100nF | C10 | 0805-1206 | Capacitor
100nF | C2 | 0805-1206 | Capacitor
100nF | C3 | 0805-1206 | Capacitor
10K | R3 | 0805-1206 | RES FIXED
10K | R2 | 0805-1206 | RES FIXED
10K | R4 | 0805-1206 | RES FIXED
10R | R7 | 0805-1206 | RES FIXED

Page 1

Sheet1

10uF/16V | C12 | ccase | polarized cap
180R | R10 | 0805-1206 | RES FIXED
180R | R8 | 0805-1206 | RES FIXED
1K | RV1 | trim-pot | POTENTIOMETER
1N4001 | D1 | axial0.5 | Diode
1nF | C1 | 0805-1206 | Capacitor
22uF/16v | C13 | ccase | polarized cap
270R | R6 | 0805-1206 | RES FIXED
2N7000 | Q1 | TO-92B | FET
33R | R9 | 0805-1206 | RES FIXED
4K7 | R1 | 0805-1206 | RES FIXED
78L05 | U1 | to-92a | Regulator IC
BN43-202 | T1 | BALUN | balun core
NDT2955 | Q2 | SOT-223 | FET
RD16HHF1 | Q3 | TO-220 | FET

Page 2

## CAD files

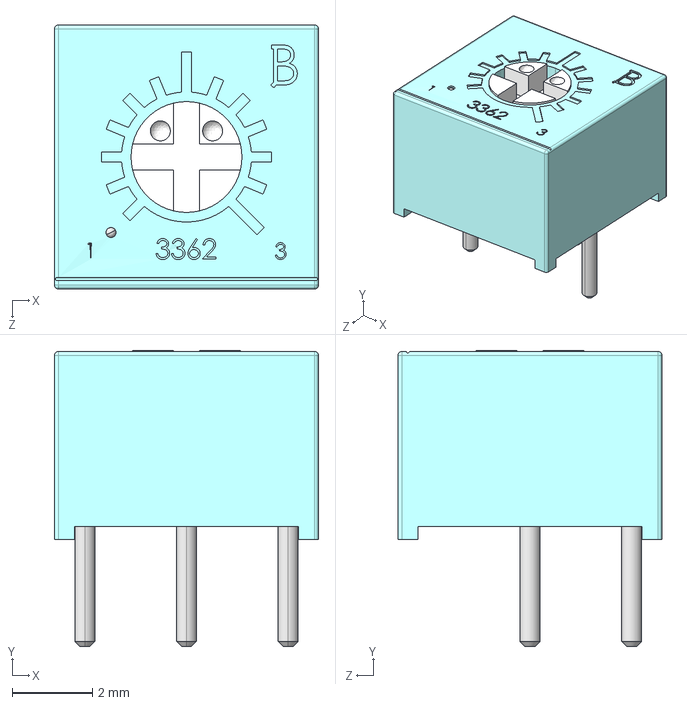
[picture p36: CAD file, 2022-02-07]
HF-PA/models/3362P-1-102LF.STEP
6.60 x 7.40 x 6.60 mm

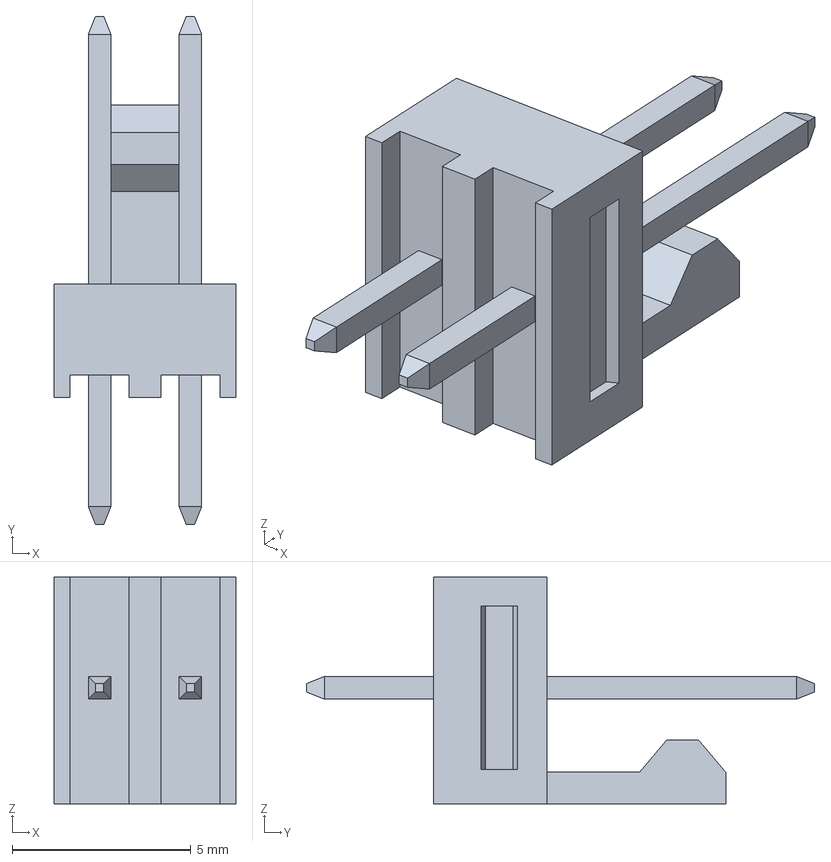
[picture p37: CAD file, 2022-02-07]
HF-PA/models/22-23-2021.stp
5.08 x 14.2 x 6.35 mm

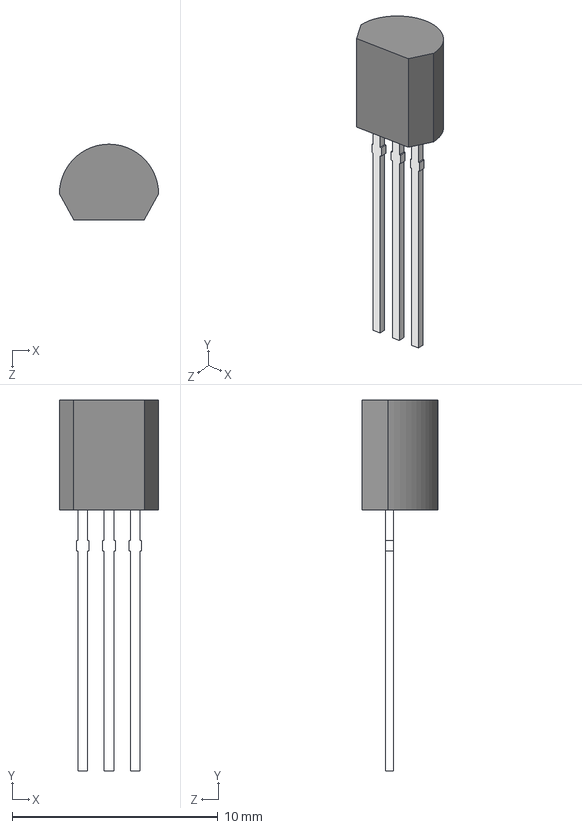
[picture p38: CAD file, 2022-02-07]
HF-PA/models/LM78L05ACZ_NOPB.step
4.83 x 18.0 x 3.68 mm

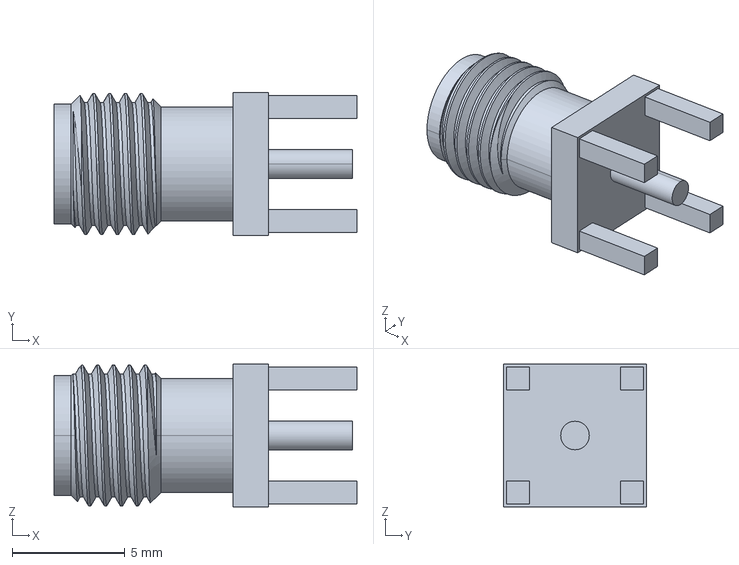
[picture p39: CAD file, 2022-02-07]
HF-PA/models/901-144.stp
13.5 x 6.35 x 6.35 mm

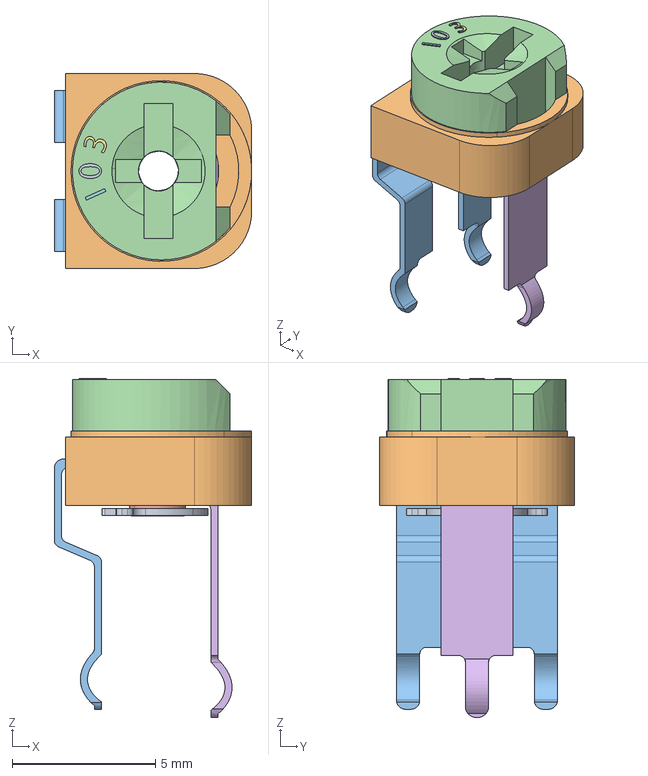
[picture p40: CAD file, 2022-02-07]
HF-PA/models/Poti_10kohm.stp
6.88 x 6.80 x 11.8 mm

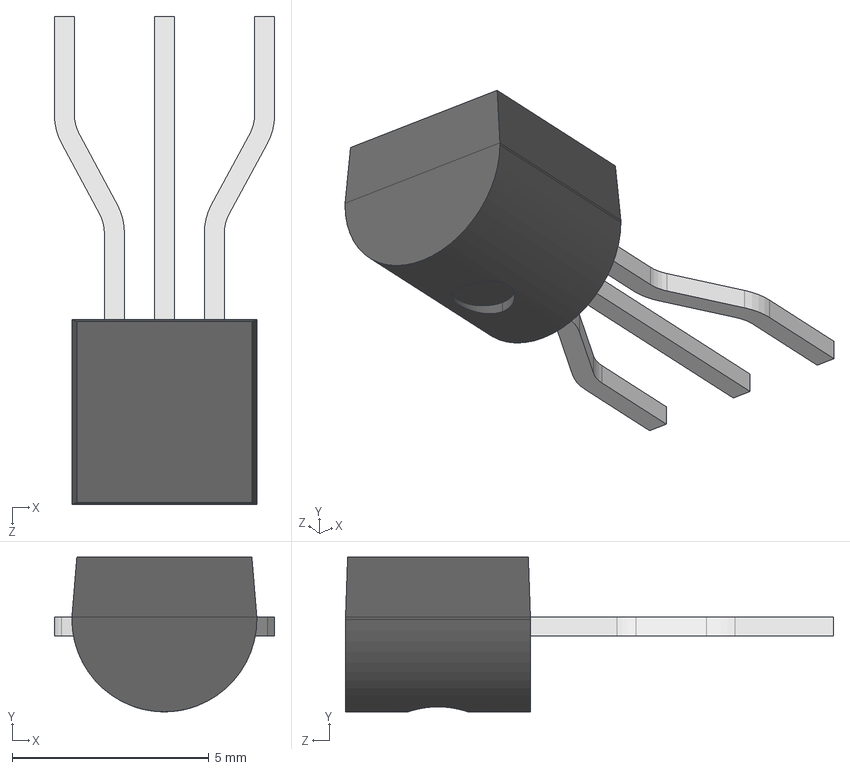
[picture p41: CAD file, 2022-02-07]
HF-PA/models/User Library-TO-92-2_54-line.STEP
5.60 x 3.93 x 12.4 mm
User Library-TO-92 Version2_TO-92 Part1
User Library-TO-92 Version2_TO-92 Part3
User Library-TO-92 Version2_TO-92 Part4
User Library-TO-92 Version2_TO-92 Part5

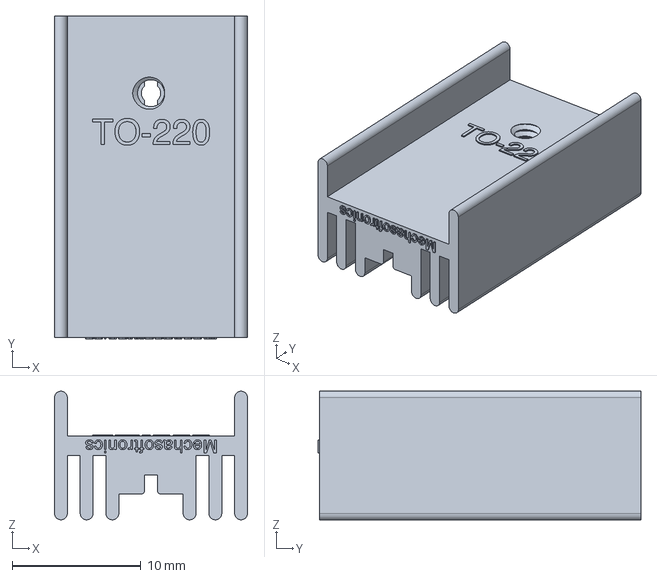
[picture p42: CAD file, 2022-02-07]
HF-PA/models/heatsink_to-220.stp
15.0 x 25.1 x 10.0 mm

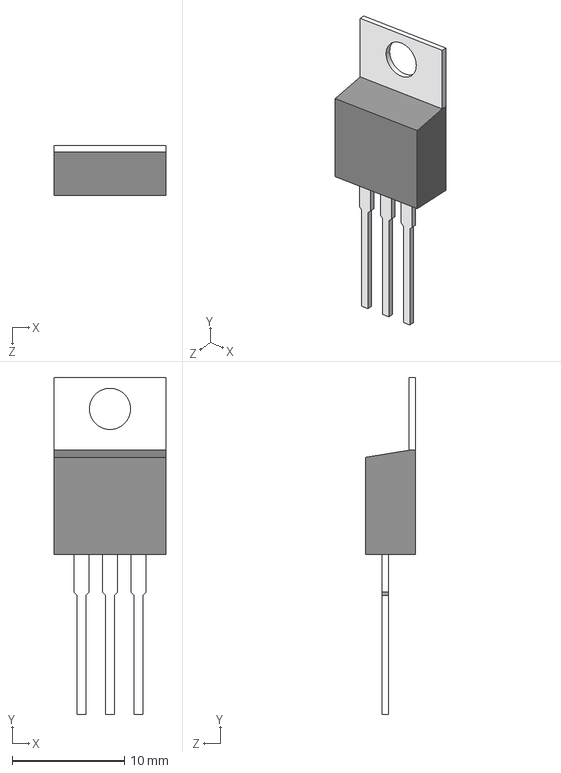
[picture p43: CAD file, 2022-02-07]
HF-PA/models/LM7805CT_NOPB.step
9.97 x 30.0 x 4.44 mm

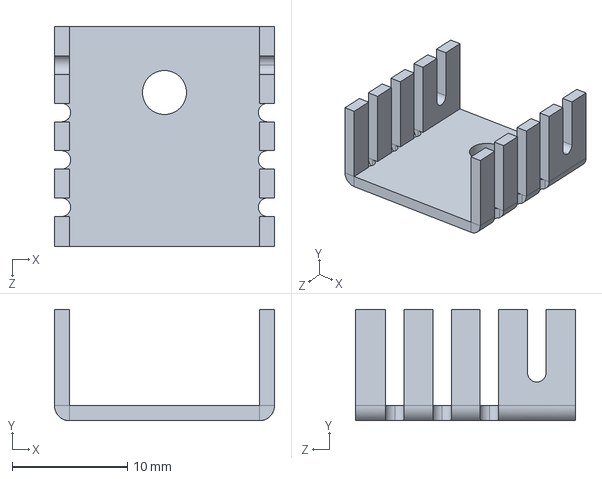
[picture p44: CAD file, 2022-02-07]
HF-PA/models/577102B00000.STEP
19.1 x 9.65 x 19.1 mm

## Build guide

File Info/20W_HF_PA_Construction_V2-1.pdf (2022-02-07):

Version date 03-04-06

## G6ALU 20W FET PA – Construction Information

The requirement
This amplifier was designed specifically to complement the Pic-A-Star transceiver developed by Peter Rhodes G3XJP. From the band pass filter an output of approximately –10dBm can be obtained, this requires amplifying to a useable power level to be of use. Although developed for a specific application the design presented here is flexible enough to be used with any low level HF signal source. Adjustment of the attenuator value and possible removal of the first stage can accommodate a higher input power.
Circuit description
A 3 stage topology has been used requiring a nominal input of –13dBm (0.05mW) for an output of 20W at 1.8MHz falling to 16W at 30MHz (typically 25W on 80M). Typical current consumption is 2.7Amps @ 13.8V, giving a stage efficiency of 53% at 20W output.

Field effect transistors have been used for the power stages, these are low cost and have so far proven to be very robust. One failure mode that must be looked out for is excessive device dissipation; ensure that the gate is not left “floating”. If for any reason there isn’t a DC connection the gate may rise in voltage and turn the device on drawing excessive current leading to device failure. The devices used here are in a TO220 package which differ from switching devices in that the tab is connected to the source electrode, so in this design are grounded by the PCB and heat sink. No insulating washers are used when bolting the devices down to the heat sink and PCB.

To ensure a good match to the band pass filters a 5dB attenuator has been incorporated before Q1, this is required as the input impedance will vary with frequency. When used with the Pic A Star any additional attenuation required should be placed in the IF stage – refer to the STAR “Set up information” document.

The first gain stage follows the input attenuator, this is a simple common emitter bipolar circuit using emitter feedback, the gain of which is set by the load impedance of T2 (200 Ohms) and that of emitter resistor R8 (33 Ohms). These components set the voltage gain at about 8 or 18dB power gain.

Stage 2 comprises of two field effect transistors (FETs), as previously stated no negative feedback is provided giving a stage gain of about 23dB, providing ¼ watt of drive to the output stage. FETs are broadband devices, if driven from a constant voltage source their output can be expected to be flat across the HF band. Unfortunately FETs have a relatively high input capacitance, in the case of the RD06HHF1s used here it is about 27pF giving a capacitive reactance of 196 Ohms @ 30Mhz. Rather than trying to provide a broad-band match to this reactance it is simpler just to load the gate with a resistor of much smaller value, this does of course limit the stage gain but to me 23dB is still quite adequate! Q2 and Q3 gates are loaded with 100R resistors, these also provide a DC path for the bias voltage.

Matched device pairs haven’t been used so separate gate bias is provided for each device, this bias is provided from a common source; ZD1 a 5.6 volt zener diode in series with D1 giving some temperature compensation. The driver transistors are running with a quiescent current set at 125mA each, gate load resistors R10 and R11 are decoupled to ground via C9 and C10 so T2 “sees” a total load of 200 Ohms. The output load of Q2 and Q3 is provided by a centre-tapped transformer wound on a BN43-1502 or Epcos B62152A4X1 type core. As the two types have different AL values, different winding instructions are given for each.

The output stage is very similar to that of the driver having a gain of about 21dB, the main difference being with the output transformer arrangement and gate load resistors. This transformer consists of two cores, the primary of each are connected in series and the outputs in parallel, this arrangement ensures that both transistor drains are tightly coupled in anti-phase so giving good even harmonic suppression. The quiescent current of each transistor is set to 250mA.
Construction
The PCB has been designed to have a continuous ground plane on the underside with connecting tracks on the top. To enable a PCB to be manufactured using your preferred method I have included a reversed positive plot of the top side, when plotting ensure that Acrobat isn’t resizing the plot for you by checking with the 100mm reference provided.

As they are easier to apply and have lower parasitic inductance, surface mount capacitors have been used where practical, in addition all transformers are surface mounted. Other components are leaded types and pass through the PCB, note that anywhere a grounded lead passes through the PCB it should be soldered top and bottom, in addition there are 6 through board links that need soldering both sides. All non-grounded leads which pass through the board should have the ground plane relieved on the underside.

Transformer winding - All transformers are simple to wind, wire diameter for transformers T1 and T2 isn’t critical. For T3 don’t be tempted to greatly increase the diameter of wire although the core holes would allow it, using a wire significantly thicker increases its self capacitance affecting the transformer wide band performance.

The one turn primary of T4 and T5 can be made from a piece of braid removed from RG58 or similar coax, for the secondary winding use PVC covered hook up wire. Use the heaviest type that will pass through the cores.

As previously noted no insulating washers are used between the heat sink, transistors and PCB. A direct ground connection must be made between the PCB and heat sink, grounding for the Fets is mainly made via their tabs. Two options are provided for output HF compensation, the low cost route is to use two 1nF surface mount ceramic capacitors but due to their questionable suitability (due to max current handling) provision has been made for a 2n2 silver mica part. So far though there are no reported failings of ceramic capacitors, the choice is yours.

The following pictures are of the prototype, some component positions have changed with the published version.

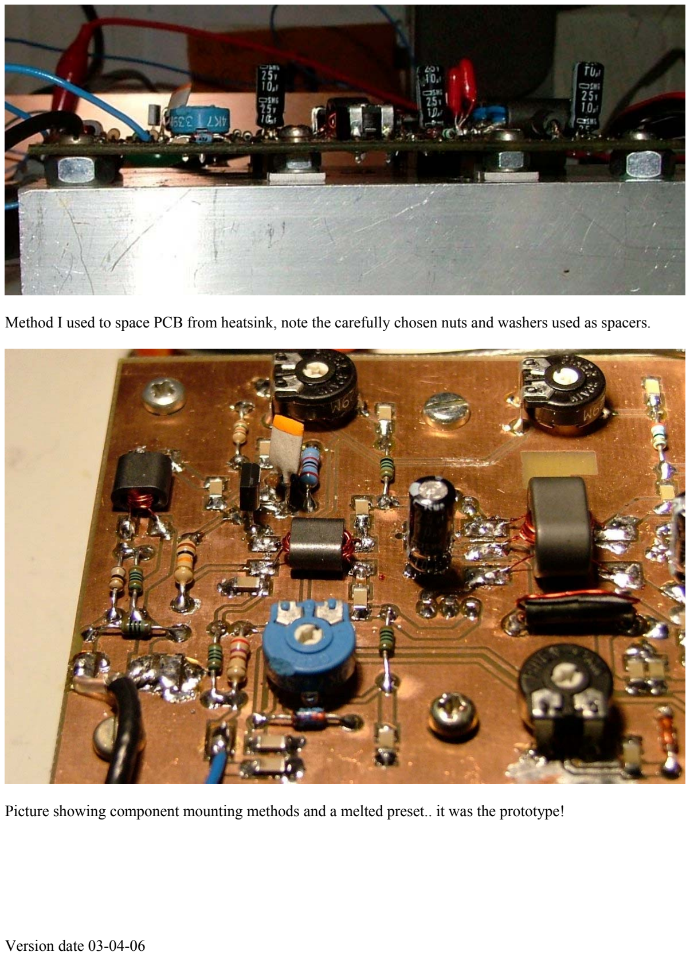
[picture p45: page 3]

Method I used to space PCB from heatsink, note the carefully chosen nuts and washers used as spacers.

Picture showing component mounting methods and a melted preset.. it was the prototype!

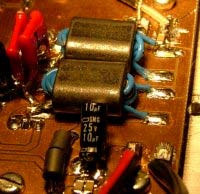
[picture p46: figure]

Output transformer mounting detail.

Testing and alignment
Before applying power check and make sure there are no bridges between any pads and the ground plane. Turn all bias presets anticlockwise (lowest bias voltage). Momentarily apply a supply to the 13V8 terminal and check current drawn is practically zero; C28 will draw initial charging current.

Apply supply to the Bias input and separately to the 13V8 input via an ammeter capable of reading 1 Amp, connect a power meter and 50-Ohm dummy load to the output. Adjust VR1 for a quiescent current of 125mA, VR2 for an increase of 125mA (250mA total), VR3 for an increase of 250mA (500mA total) and finally VR4 for another 250mA increase giving 750mA total quiescent current. Bias adjustment will be sensitive but actual values achieved aren’t critical. At this stage there shouldn’t be any RF power appearing at the dummy load!

Disconnect power, attach to the band pass filter transmit output of the STAR and apply power. Select 80M and adjust the drive level to a low level, with key down slowly increase the drive and monitor the output level. If an oscilloscope is available monitor the output waveform, it should be easy to achieve an output of 20W on 80M before the output becomes distorted. Repeat drive adjustment for all bands.
In Use
Note that the input and output circuits are “floating”, in normal use the coaxial screen connection will be linked to the PCB ground pad. This facility has been provided for situations where a specific cabinet construction generates a ground loop, a floating input or output may “break” the loop.

No output filter is provided, the amplifier still has considerable gain in to the VHF region so must be used with an effective low pass filter, typically the second harmonic is 40dB down on carrier but third harmonic only 25dB down.

When used with a STAR the bias supply is provided directly by the timer board (12V Tx PA bias) and 13V8 terminal left permanently connected to supply, the transistors were developed for use in mobile equipment so can be safely supplied with higher than the normal shack voltage of 13.8V. For an increase in output up to 14.5V may be used safely.

Component Sources
Q1 is specified as a ZTX327 or ZTX313, both of which are now obsolete! An alternative may be the MPSH10 or indeed any other RF transistor of suitable current and frequency rating, watch the pin outs though and adjust C3 to compensate the HF end of band.

The FET devices were obtained from European Microwave Components, contact details:

European Microwave Components Ltd.
36 Priors Way Business Park,
Coggeshall,
Essex.
United Kingdom.
CO6 1TW

Web http://www.emc.uk.com and email sales@emc.uk.com , note that their minimum order charge before VAT is £25, the value of transistors used in this design total about £8.00!

Ferrite cores can be obtained from any of the normal vendors; no doubt substitutions can be made especially with T1 – T3 whose characteristics aren’t critical.

Change log:
28-04-05 | Corrected input power requirements following robustness test
| Changed harmonic output level
| Added note about PCB grounding
| Added note on through board links
| Added notes on transformer construction
02-05-05 | Corrected value of C3 in parts list to 220pF
03-04-06 | Input attenuator changed from 10dB to 5dB, additional attenuation now placed in IF stage.
| R2 and R3 were 100R, now 180R. R1 was 68R now 27R

Quantity | Component reference | Description | Notes | Function
23 | C1, 2, 4, 5, 6, 7, 8, 9, 10, 12, 13, 14, 15, 16, 17, 18, 20, 21, 22, 23, 24, 26, 27 | 100nF 1206 SM | | Coupling - decoupling
3 | C11, 19, 28 | 10uF 25V PC electrolytic | | LF decoupling
1 | C25 | 330pF Silver Mica > 100V | Can be made up of multiple capacitors | HF frequency compensation of T4 & T5
2 | C29, 30 | 1nF 1206 SM | Not used if C31 fitted, see text | LF frequency compensation for T4 & T5
1 | C3 | 220pF 1206 SM | | HF peaking for Q1
1 | C31 | 2200pF Silver Mica | Not used if C29 & 30 fitted, see text | LF frequency compensation for T4 & T5
1 | D1 | 1N4148 | Partial temperature compensation for bias supply
1 | ZD1 | 5V6 400mW | Bias voltage regulation
1 | Q1 | ZTX313, ZTX327 | | First stage amplification
2 | Q2, Q3 | RD06HHF1 | See text | Second stage amplification
2 | Q4, Q5 | RD16HHF1 | See text | Third stage amplification
3 | R5, R10, R11 | 100R | | R5 decoupling, R10 & R11 load for 1st stage amplifier and gate reactance swamp resistors
3 | R1, R12, R13 | 27R | | R1 part of input attenuator. R12, 13 Gate reactance swamping resistors for Q4 and 5
1 | R4 | 10K | | Part of Q1 bias
1 | R6 | 1K5 | | Part of Q1 bias
1 | R7 | 270R | Resistor will dissipate about 0.3W so miniature 0.6W MF recommended | Series resistor for FET bias supply
2 | R2, R3 | 180R | | Input attenuator
1 | R8 | 33R | | Q1 gain setting
1 | R9 | 82R | | Q1 emitter resistor
| | | Unless otherwise stated all resistors 1/8 watt or higher , 5% tolerance or better
4 | VR1, VR2, VR3, VR4

2K2 Horizontal
preset | Q3-6 gate bias setting
1 | L1 | 2* type 43 beads | 2 passes of 0.25mm enamelled copper wire through 2 type 43 beads - see photos | Supply decoupling
1 | L2 | 2* type 43 beads | 1 pass of 1.25mm tinned copper wire through 2 type 43 beads -see photos | Supply decoupling
1 | T1 | BN43-2402 | Primary 3 turns, secondary 6 turns of 0.25mm enamelled copper wire wound on to BN43-2402 core
1 | T2 | BN43-2402 | Primary 6 turns, secondary 4 turns of 0.25mm enamelled copper wire wound on to BN43-2402 core
1 | T3 | BN43-1502 or Siemens (Epcos) B62152A4X1 | Primary 8 turns centre tapped (I.E. 4+4), secondary 4 turns 0.25mm enamelled copper wire wound on type BN43-1502 or for Epcos B62152A4X1 core, 12 turns centre tapped primary with 6 turn secondary.
2 | T4, T5 | BN43-202 | Primary 1 turn of braid removed from RG58 cable or similar, secondary 4 turns of PVC covered hook up wire wound on BN43-202 core - see photo.

### 20W HF PA Component list

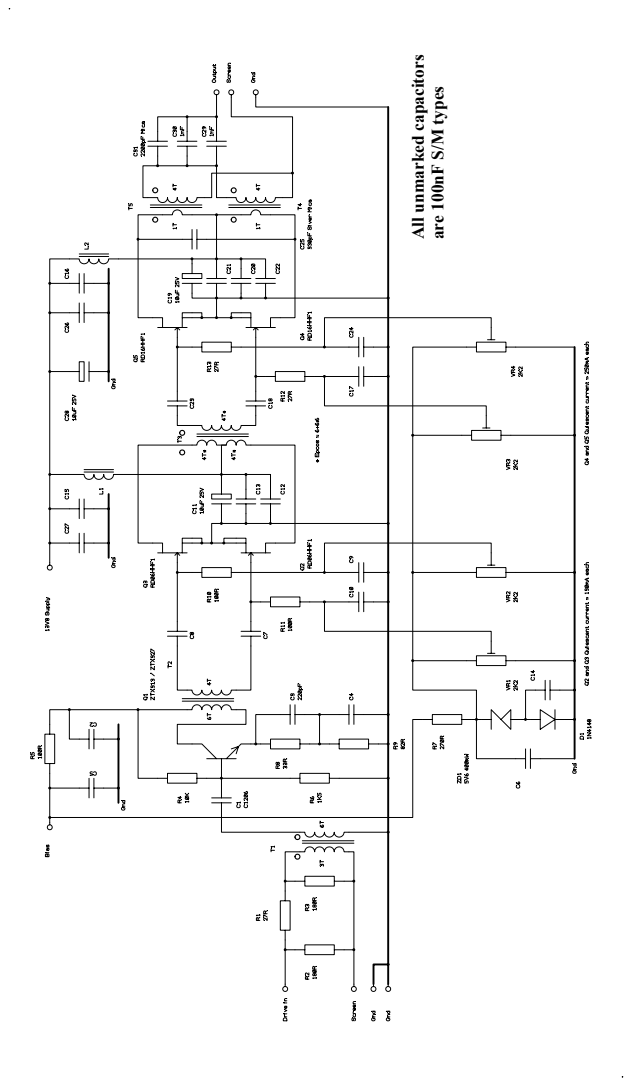
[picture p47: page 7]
are 100nF S/M types

All unmarked capacitors

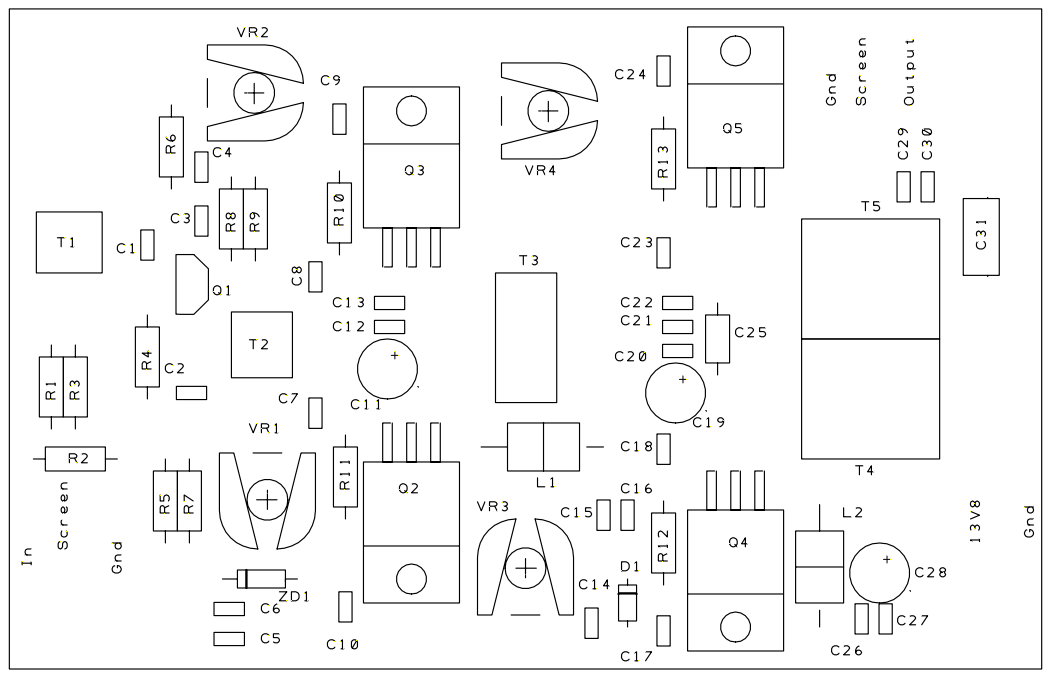
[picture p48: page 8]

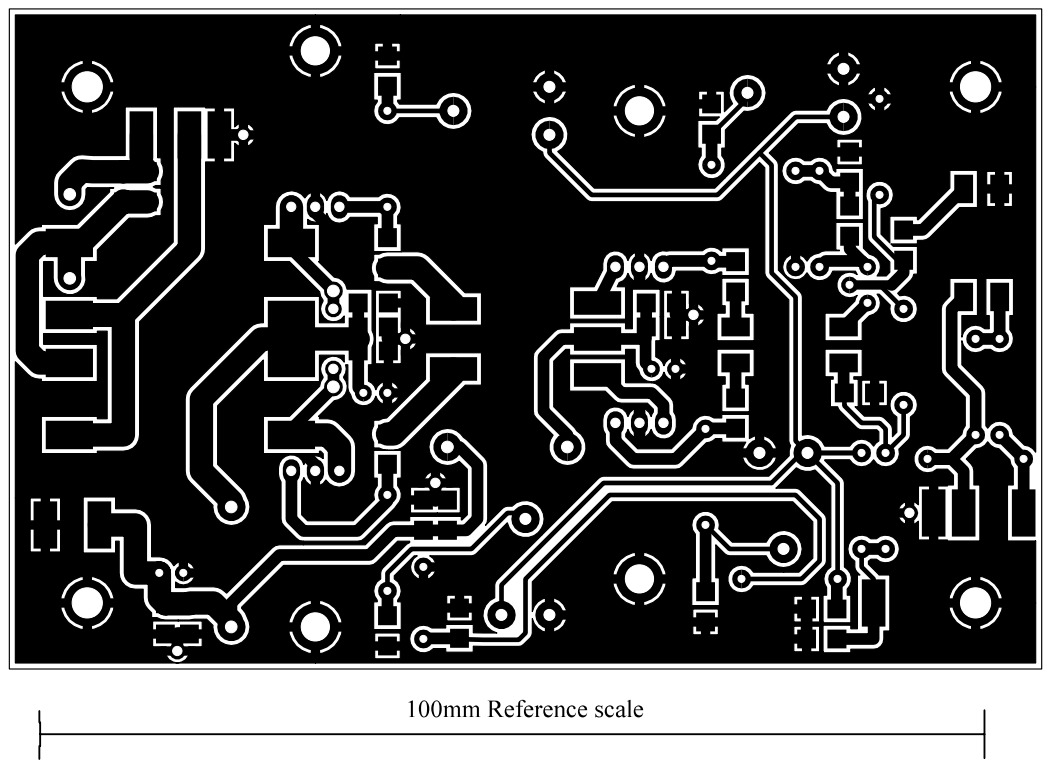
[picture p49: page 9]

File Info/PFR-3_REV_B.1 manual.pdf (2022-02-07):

## The PFR-3 Three band “Portable Field Ready” QRP CW Transceiver 40/30/20 meters Hendricks Kits – www.qrpkits.com KD1JV Designs

## Production manual 6/10/08 Rev B

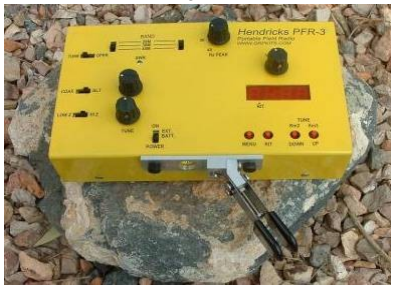
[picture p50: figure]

PFR-3 shown with optional paddle installed. Specifications:

Bands : 40 meters, 30 meters and 20 meters
Tuning range: Full band coverage
DDS VFO with 50 Hz slow tuning rate and 100 Hz fast tuning rate Mode: CW only

Receiver MSD: 0.2 uV typical
Selectivity : 300 Hz
Four crystal IF filter and 600 Hz center frequency audio band pass filter

Receive current, no signal typical:
Active, 47 ma
Idle, 34 ma

Transmitter:
5 watts at 12.0 volts, all bands
Transmitter current: 650 ma (40 M) to 750 ma (20 M) typical at 5 watts. Spurs: - 50 dBc maximum, all bands

5 to 40 wpm internal iambic keyer
Selectable A or B mode
Two (2) 63 character keyer memories.

Coax or balanced line output
Built in BLT (balanced line tuner)

Size: 7.2” wide X 4.2” deep X 1.5” high (less knob height).
Weight: 18 oz, no batteries installed.

Power supply voltage: 8 volts minimum, 12.5 volts maximum. 12 to 9 volts recommend. External power or internal battery pack

# Table of Contents

Group 1 assembly, Microprocessor and display:....5

## DDS frequency calibration and precise BFO

Group 5, SWR bridge and balanced line tuner:....12

## Mounting the board in the cabinet and final wiring:

The difference between A and B modes:.........17

## Using the BLT with end feed wire antennas or

PFR front panel controls and rear panel connectors.

Troubleshooting steps: Divide and conquer....20

Parts check list:

QTY | VALUE | | QTY | VALUE
1 | 10 ohms | Brown, black, black, gold | 1 | 4.7 p or 5p NPO | Disk, brown, black dot on top edge
1 | 51 ohms | Green, brown, black, gold | 3 | 22 p NPO | Disk, brown, black dot on top edge
4 | 470 ohms | Yellow, Violet, brown, gold | 1 | 47 p C0G | Disk, brown, black dot on top edge
11 | 2.2 K | Red, red, red, gold | 1 | 68 p NPO | Disk, brown, black dot on top edge
3 | 4.7 K | Yellow, violet, red, gold | 4 | 100 p C0G | Mono, yellow or NPO disk
1 | 7.5K | Violet, green, red, gold | 6 | 150 p C0G | Mono, yellow
5 | 10 K | Brown, black, orange, gold | 2 | 220 p C0G | Mono, yellow
1 | 51 K | Green, brown, orange, gold | 3 | 330 p C0G | Mono, yellow
5 | 22 K | Red, red, orange, gold | 1 | 560 p C0G | Mono, yellow
4 | 100 K | Brown, black, yellow, gold | 1 | 680 p C0G | Mono, yellow
2 | 330 K | Orange, orange, yellow, gold | 1 | 470 p DISK | Disk, brown
1 | 1 MEG | Brown, black, green, gold | 5 | .001 ufd disk | Disk, brown
1 | 50K audio | Vertical PCB mount | 7 | 0.01 ufd X7R | Mono, yellow
3 | 51 ohm 2W | Green, brown, black, gold | 14 | 0.1 ufd X7R | Mono, yellow
2 | SA612AN | 8 pin DIP IC | 2 | 0.01 ufd film | Film, green
1 | LM358N | 8 pin DIP IC | 1 | 30 p trimmer | Green
1 | LM386N | 8 pin DIP IC | 3 | poly-variable | Variable capacitor, dual section
1 | 74HC02N | 14 pin DIP IC | 2 | 10 ufd /16V or 25V | Aluminum electrolytic
1 | ATMEGA48 | 28 pin DIP IC | 1 | 22 ufd /16V or 25V | Aluminum electrolytic
1 | 78L05 | TO-92 plastic | 2 | 100 ufd /16V or 25V | Aluminum electrolytic
1 | 78L06 | TO-92 plastic | 1 | 330 ufd /16V or 25V | Aluminum electrolytic
1 | 1N5817 | Plastic diode shottky rectifier, 1A | 4 | 8 pin DIP sockets
1 | 1N4756A | Larger glass diode, 47V 1W zener | 1 | 14 pin DIP socket
3 | SD101C | Glass diode, fast shottky | 1 | 28 pin DIP socket
1 | FQPF7P06 | TO-220 plastic P MOSFET | 2 | FT37-43 | Ferrite core, gray or black
5 | 2N7000 | TO-92 plastic N MOSFET | 6 | T37-2 Red | Powdered iron core
3 | BS170 | TO-92 plastic N MOSFET | 2 | T37-6 Yellow | Powdered iron core
1 | 4 dig LED | 4 digit multiplexed display module, hi eff | 1 | T100-2 Red | Powdered iron core
1 | Super bright | LED clear | 4 | 6mmx13mm tack | Push button switch
2 | 10 uhy rfc | Brown, black, black, gold | 6 | DP3T slide switch
5 | 4.9152 MHz | Crystals HU-49US | 2 | Stereo jacks
1 | Power jack | 2.5 mm pin | 4 | Knobs
1 | BNC jack | | 1 | Red filter
2 | Binding posts | 1 Red, 1 Black | 1 | PC board
| | | 3 | | Sets of vari-cap mounting hardware
4 | 1/4” 4-40 screw | | 4 | #4 lock washers
| #30, #28, #24 | Magnet wire, #24 hook up wire | 6 | #4 Nylon washers
| | These parts are premounted
1 | AD9834BRUZ | DDS | 3 | 22 K | 0805 chip resistor
1 | 50.00 MHz clk | Clock oscillator | 1 | 22 p | 0805 NPO chip resistor
1 | 10 uhy | 1206 Choke inductor | 2 | 8 p | 0805 NPO chip capacitor
2 | 1.5 uhy | 1206 Choke inductor | 2 | 150 p | 0805 NPO chip capacitor
1 | 815C35UA | 3.5V low drop out regulator | 1 | 220 p | 0805 NPO chip capacitor
3 | 270 ohm | 0805 chip resistor | 4 | 0.01 ufd | 0805 X7R chip capacitor
1 | 3.9 K | 0805 chip resistor | 3 | 0.1 ufd | 0805 X7R chip capacitor
3 | 10 K | 0805 chip resistor

Parts placement overview.

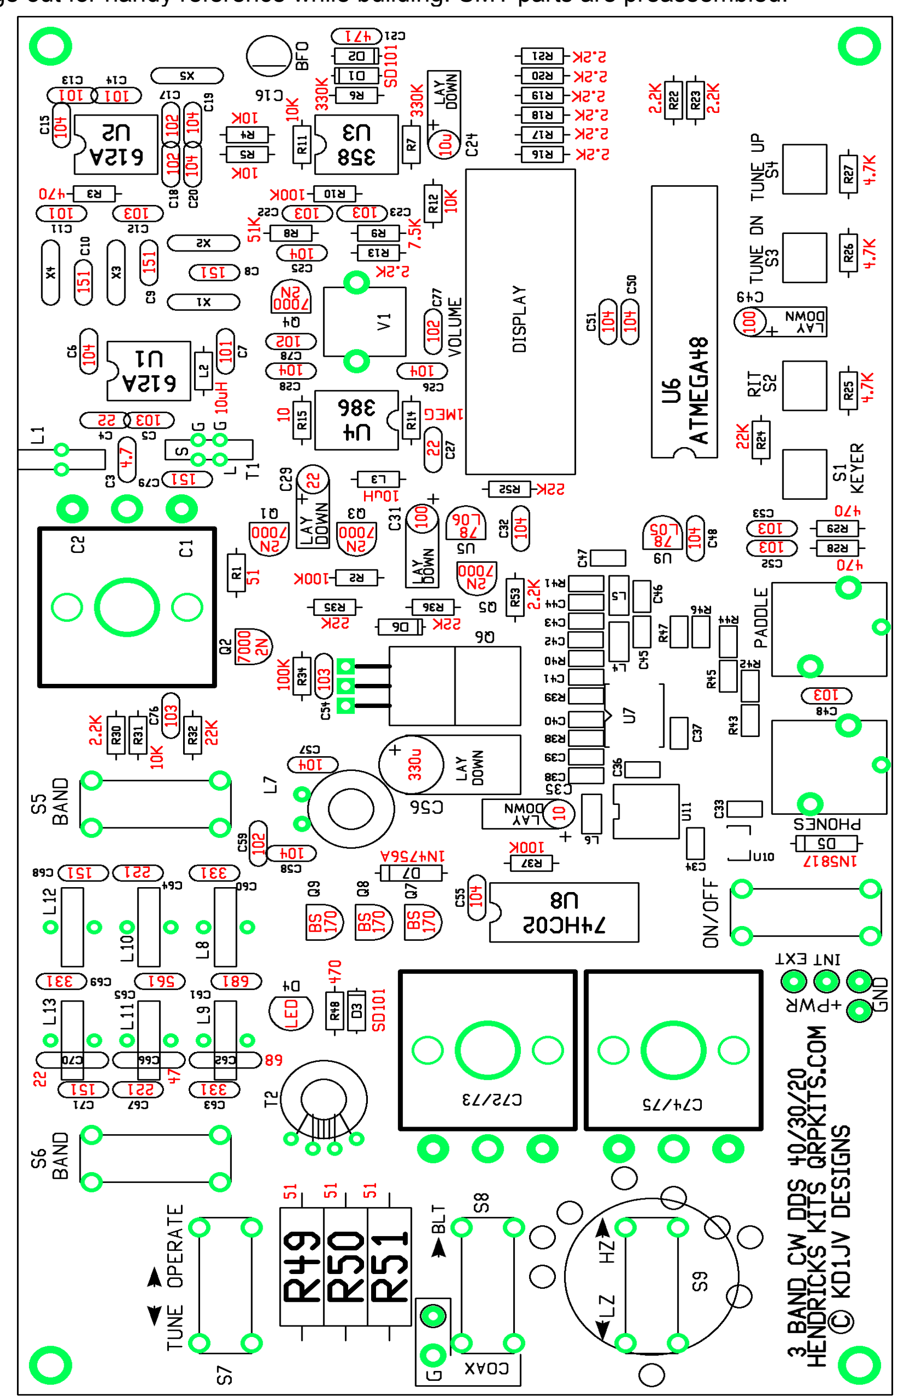
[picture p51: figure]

Print this page out for handy reference while building. SMT parts are preassembled.

Group 1 assembly, Microprocessor and display:

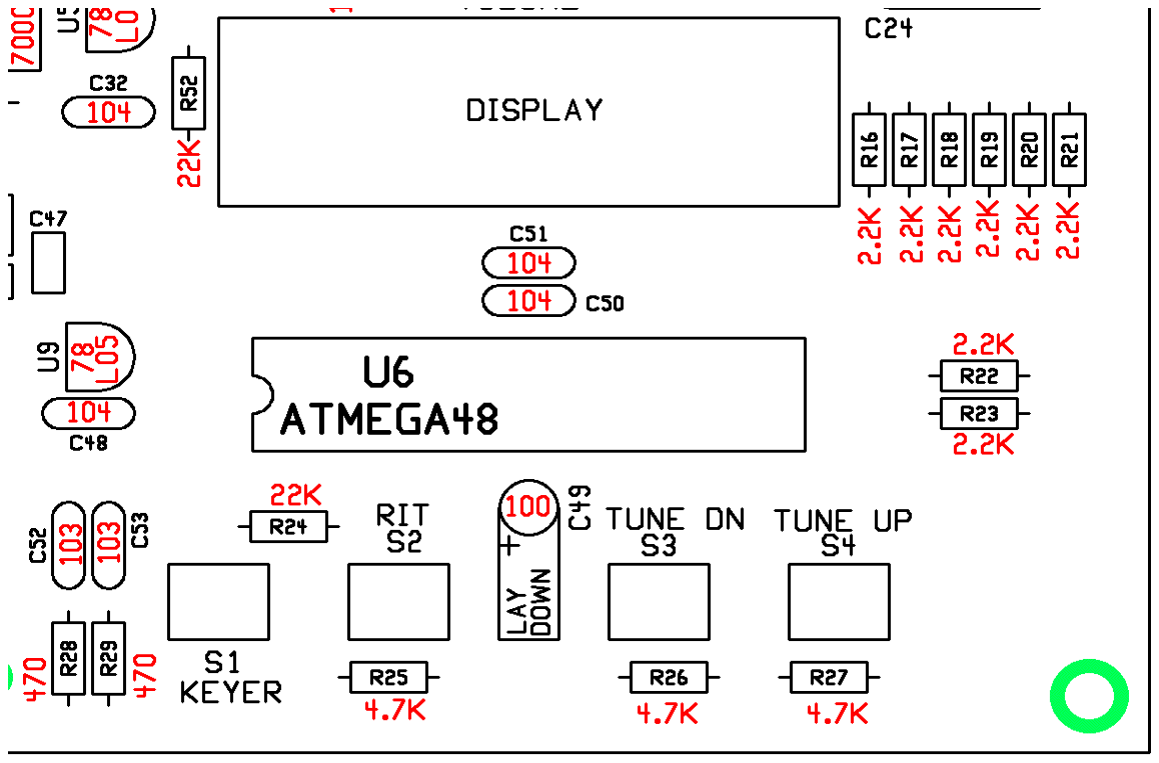
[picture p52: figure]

- R16 to R23 - 8 places. 2.2K (RED/RED/RED/GLD)
- R24, R52 – 22 K (RED/RED/ORG/GLD) – be careful not to mix up the 2.2 K and 22 K !
- R25 to R27 – 4.7 K (YEL/VOL/RED/GLD)
- R28 and R29, 470 ohms (YEL/VOL/BRN/GLD)
- C32, 48, C50, C51, 0.1 ufd (104, mono, yellow) [note, there is another C48 labeled on the board]
- C52,C53 0.01 ufd (103, mono, yellow)
- C49, 100 ufd / 16V (or 25V) Long lead is plus. Bend leads at right angle to part and lay part flat to board along extended outline. (You will do this with all the other electrolytic caps on the board too)
- U9, 78L05. Do not mix up with the 78L06 or 2N7000 which are in same TO-92 package.
- 28 pin dip socket at U6 When installing sockets, make sure all the pins are sticking out the holes in the board before soldering. If one or more pins happens to fold over under the socket as you insert it, it will be very difficult to remove the socket to fix this once you start soldering pins! Also make sure the notch is facing the right way.
- LED display module. This will only go in one way due to the missing pins on the display and corresponding missing holes on board. Space the display slightly from board so that the pins only stick out 1/32” from bottom of board. Solder two corner pins first, then double check to make sure the display is evenly spaced from the board and not tilted. Re-heating one pin will allow you to make adjustments.
- S1, S2, S3, S4 - Four (4) TACT switches. These have the long red actuators.

C48 location above SMT parts.

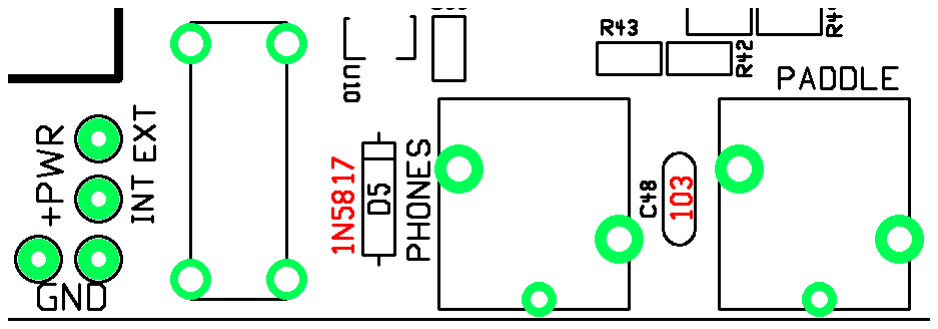
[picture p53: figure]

- D5, 1N5817 diode, black body. Band on part goes towards line on part outline.
- C48, 0.01 ufd (103) [C48 designation repeated on board by mistake, this one is located between the phone jacks and is labeled as C30 on schematic]
- Paddle and phone jacks.
- DP3T slide switch. (ON/OFF) – make sure switch is flush to board before soldering more than one mounting tab.
- C35, 10 ufd / 16V (or 25V) Again, long lead is plus and lay down part flat to board. Located above SMT parts, next to the R37 location.

Group 1 smoke test:

- Install the ATMEGA48 microprocessor chip into the U6 socket.
- Connect a 9 to 12 volt power supply to the power input pads next to the on/off switch. A 9 volt radio battery would be adequate for this test.
- Apply power to the board and turn on power switch if it is not already on.
- The LED display should light up with four “8”s for a second. This is the display test. Then the display should display “40” for another couple of seconds (indicating the band), then 030.0 (this is the frequency)
- Clicking closed the Tune UP or Tune DN switches should make the display increment or decrement.
- Clicking the RIT switch should make the left most decimal point on the display light up.
- The DDS chip should also be working at this point. This can be tested with a frequency counter connected to the R39/R41 junction at U7 or general coverage receiver tuned to about 2.115 MHz (+/- 1 kHz) with a short pick up lead for an antenna placed near the DDS chip (U7)

Group 2 Assembly, receiver section:

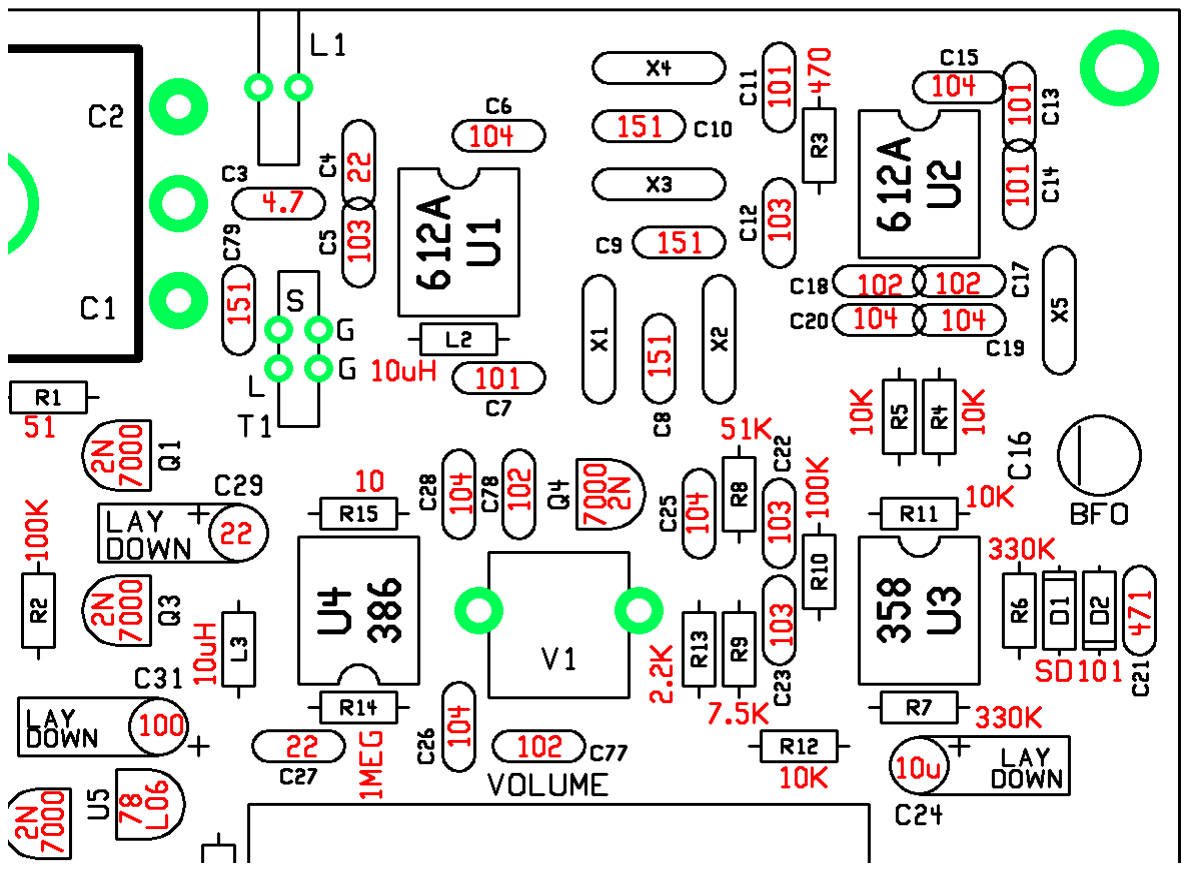
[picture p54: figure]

R15 | 10 ohm | BRN/BLK/BLK | C3 | 4.7 p or 5p | NPO, DISK | BROWN
R1 | 51 ohm | GRN/BRN/BLK | C4,C27 | 22 p | NPO, DISK | BROWN
R3 | 470 ohm | YEL/VOL/BRN | C7,11,13,14 | 100 p (101) | C0G | YELLOW
R13 | 2.2 K | RED/RED/RED | C8,9,10,79 | 150 p (151) | NPO, DISK | BROWN
R9 | 7.5 K | VOL/GRN/RED | C21 | 470 p (471) | DISK | BROWN
R4,R5,R11,R12 | 10 K | BRN/BLK/ORG | C17,18,77,78 | .001 u (102) | DISK | BROWN
R8 | 51 K | GRN/BRN/ORG | C22, C23 | 0.01 u (103) | FILM | GREEN
| | | C5, C12 | 0.01 u (103) | MONO | YELLOW
R10 | 100 K | BRN/BLK/YEL | C6,15,19,20 | 0.1 u (104) | MONO | YELLOW
R6,R7 | 330 K | ORG/ORG/YEL | C25,26,28 | 0.1 u (104) | MONO | YELLOW
R14 | 1 MEG | BRN/BLK/GRN | C24 | 10 u/16V or 25V | LAY FLAT | ELECTRO
L2,3 | 10 uHy | BRN/BLK/BLK/GLD | C29 | 22 u/16V or 25V | LAY FLAT | ELECTRO
| | | C31 | 100 u /16V or 25V | LAY FLAT | ELECTRO
D1,2 | Glass diode | SD101
U5 | 6V reg | 78L06 | Q1,2,3,4 | 2N7000 | MOSFET
NOTE: L2/L3 look like resistors, but the body is a little shorter and fatter. Do not mix up with 10 ohm resistor. Also, be careful not to mix up 51 ohm resistor with 1 MEG, as colors are very similar.
X1,2,3,4,5 | Crystals | Tack solder case to solder pads next to crystal case. Running fine grit file along
| | edge of crystal case will make the solder easier to stick.
C16 | 30 p trimmer (Green) | Make sure flat side of trimmer faces line on outline. This can be mounted to bottom side of board for easier access once board is wired into cabinet.
U1,2,3,4 | 8 pin sockets | Make sure all the pins come through the board holes!
V1 | 50 K variable resistor | Solder mounting tabs to board.
| The following parts | mount on Bottom of board
C1/2 | Poly-varicap | Mounts on bottom of board. Use 2.5 mm washers between board and cap.
L1 | T37-2 (red core) | 40 turns, 24” of # 30 wire
T1 | T37-2 (red core) | 40 turns (#30) secondary, 5 turns primary see next page for winding details.

L1 and T1 are mounted on the bottom side of the board!
T1 winding: Wind with # 30 wire. T1 must be wound in a specific way so that the “hot” end of each winding will end up on the same side of the core and line up with the proper holes in the board. Wind the core in a counter clockwise direction, passing the wire down into the hole from the top side of the core as you hold it. At the end of 40 turns, make a short loop and continue winding five (5) more turns. The start and end wire ends will go into the two pads towards the top edge of the board, with the start end going into the pad labeled “S”. The wire which makes the loop will be sniped to separate the wire and these go into the two

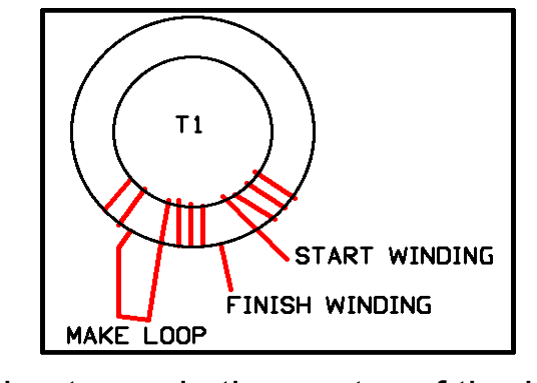
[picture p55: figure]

holes towards the center of the board. It is important to get the windings in the proper holes or the receiver sensitivity will be poor.

## Group 2 smoke test:

Install U1 and U2 (SA612A) into sockets
Install U3, LM358
Install U4, LM386 NOTE : U4 pin 1 faces “down”, the opposite direction of U1, U2 and U3

The receiver section is now done and should now be functional. Give the BFO trimmer (C16) about a ¼ turn from its factory setting. If you look closely in the trimmer hole, you will see an arrow at one end of the screwdriver slot. When the arrow points towards the flat side of the body, it is a maximum capacitance. When it points to the round end opposite the flat end, it is at minimum. Using leads connected to the BNC connector, you can tack these wires across R1 in order to connect up an antenna (make the connections on the bottom of the board). The end of R1 near Q1 is the signal side of the resistor. Apply power to the board and you will be receiving in the 40 meter band. Adjust the Rx tuning cap (C1/2) for best band noise or signal. The peak should occur near full counterclockwise rotation. Plugging in a paddle to the paddle jack and then operating the paddle should result in hearing the side tone sending dits and dahs. The MENU function switch annunciations can now also be heard.

DDS frequency calibration and precise BFO setting adjustment:

If you have an accurate frequency counter, the DDS frequency can be calibrated. Without calibration, the operating frequency maybe off as much as +/- 200 or 300 Hz on the 20 meter band and to lesser extent on the lower bands. This is due to variations in the reference clock oscillator for the DDS chip. Calibration is done at 10.000,000 MHz, so it could be possible to zero beat WWV, but it is better left alone if an accurate frequency counter is not available. It is also possible to tweak the IF offset frequency so that it is centered in the passband of the crystal filter. This adjustment is done with the aid of an Oscilloscope, which could be a virtual one running on PC, as all you need to see is audio frequencies. The IF offset adjust mode is also used to set the BFO trimmer to match the side tone of the rig and this can be done by ear.

Entering Calibration modes:
While holding the DOT paddle and MENU switch closed, turn power on to the board. The LED display will read [CAL.r].

Reference frequency calibration:

A frequency counter connected to the TP1 test point near the DDS chip will now read about 10 MHz. Use the Tune up and Tune down switches to adjust the frequency to be exactly 10.000,000 MHz. Once this is done, store by clicking the KEYER switch. Or you can skip this adjustment by clicking the KEYER switch. This will store the default values and advance to the offset adjustment

IF offset adjust and BFO trimmer set:

Once the MENU switch has been clicked, the LED display will now read [CAL.o]. Connect an Oscilloscope to Pin 7 of U3. You will see the audio product detector beat note on this pin. If you do not have an Oscilloscope, do not make any adjustments to the IF offset frequency and just go do the BFO adjustment.

Tune through the pass band of the crystal filter using the tuning switches. You will likely see the amplitude of the signal peak a little at the edge of the pass band, just before the amplitude rolls of sharply. Tune to one end of the pass band, the point the amplitude of the signal starts to roll off. Count how many clicks of the tuning switch it takes to get to the other end of the pass band. Divide that number by 2 and tune back up or down depending on which way you went initially by that number of clicks to center the frequency in the pass band of the filter.

BFO adjustment:

Plug headphones into phones jack and you will hear the side tone and BFO beat note. Adjust the volume control until they have about the same volume. Adjust the BFO trimmer until both tones are the same. The tones will wobble when they get close to being equal and seem to merge when they are. This can also be seen on an Oscilloscope. Once you match the tones, store the adjusted IF offset or leave the default values in place by clicking the MENU switch The rig will now reset.

Group 3 assembly: Transmitter section.

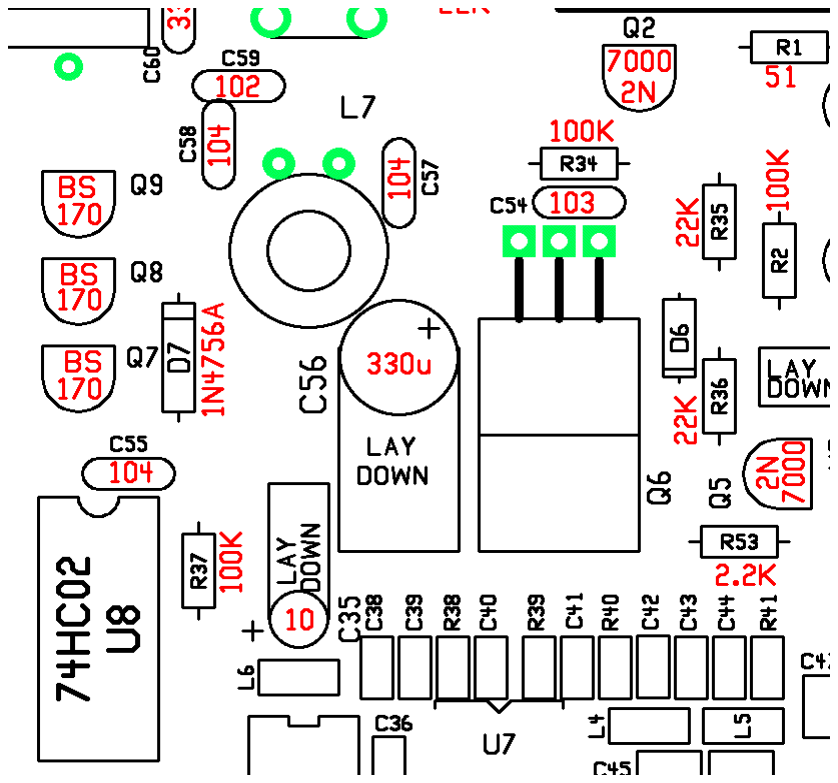
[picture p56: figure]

Pretests:
Before installing L7, we need to make a few tests first.
- Make sure R37 is 100K!
- Put rig in straight key mode by applying power with dash paddle closed or use straight key. If using paddle, dot paddle will now key the transmitter.
- Measure the voltage on pins 3 and 11 of U8. They should read about 3.5 volts. If not, check soldering of R37 and check for 5 volts on pin 14.
- Measure the voltage on pins 1 and 13 of U8. They should read 0 volts.
- Key the transmitter and measure the voltage on the L7 pad to the right, next to C57. The voltage should be about the same as the supply voltage to the board. If not, check the connections and proper values of R34, R35 and R36. Also check Q5.
- With the transmitter keyed, check the voltage on pins 1 and 13 of U8 again. These should now read about 2.5 volts. Since these pins now have a square wave at the transmitter frequency on them, exactly how a DVM responds to this signal may depend on the particular DVM used.
- If all these tests are OK, it is now safe to install L7.
R53 | 2.2 K | RED/RED/RED
R35, 36 | 22 K | RED/RED/ORG
R2,R34,R37 | 100 K | BRN/BLK/YEL
D6 | Not used
D7 | 1N4756A | Glass diode, large
C54 | 0.01 ufd (103) | MONO, Yellow
C55, 57, 58 | 0.1 ufd (104) | MONO, Yellow
C59 | .001 ufd (102) | Disk, brown
C56 | 330 ufd/16V or 25V | Electro lay flat
Q5 | 2N7000 | TO-92
Q7,8,9 | BS170 | TO-92
Q6 | FQPF7P06 | TO-220
U8 | 14 pin socket | 74HC02A IC
DO NOT | MOUNT L7 YET | Do pretests first
L7 | 8 T on FT37-43 | 8” #28 black core

Group 4, low pass filters:

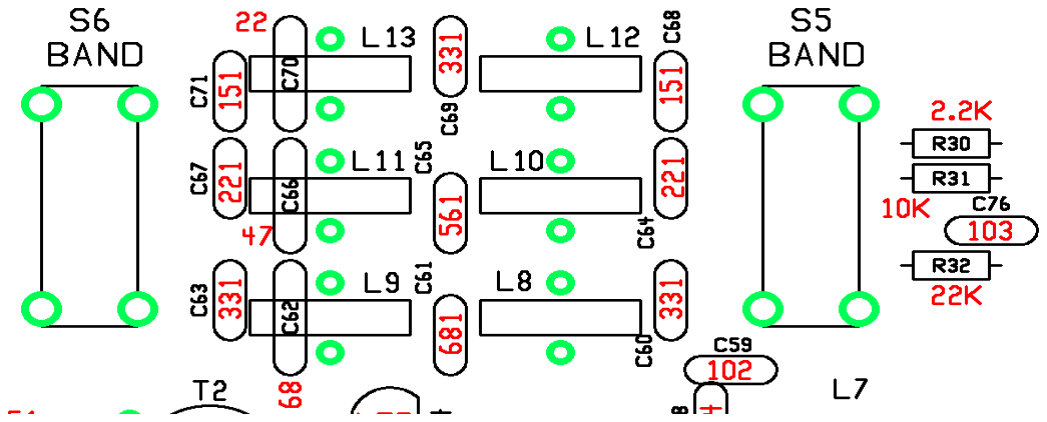
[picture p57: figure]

R30 | 2.2 K (RED/RED/RED)
R31 | 10 K (BRN/BLK/ORG)
R32 | 22 K (RED/RED/ORG)
C76 | 0.01 ufd (103, mono)
C68,C71 | 150 pfd (151, mono)
C67,C64 | 220 pfd (221, mono)
C69,C63,C60 | 330 pfd (331, mono)
C65 | 560 pfd (561, mono)
C61 | 680 pfd (681, mono)
C62 | 68 pfd (68, disk)
C66 | 47 pfd (47, disk)
C70 | 22 pfd (22, disk)
Low pass filter | Coils mount from bottom | Of board!
L8 | 17 turns on T37-2 | Red core 10” #28
L9 | 19 turns on T37-2 | Red core 10” #28
L10 | 13 turns on T37-2 | Red core 8” #28
L11 | 15 turns on T37-2 | Red core 8” #28
L12 | 14 turns on T37-6 | Yellow core 8” #28
L13 | 18 turns on T37-6 | Yellow core 10” #28
S5, S6 | DP3T slide switch

Group 5, SWR bridge and balanced line tuner:

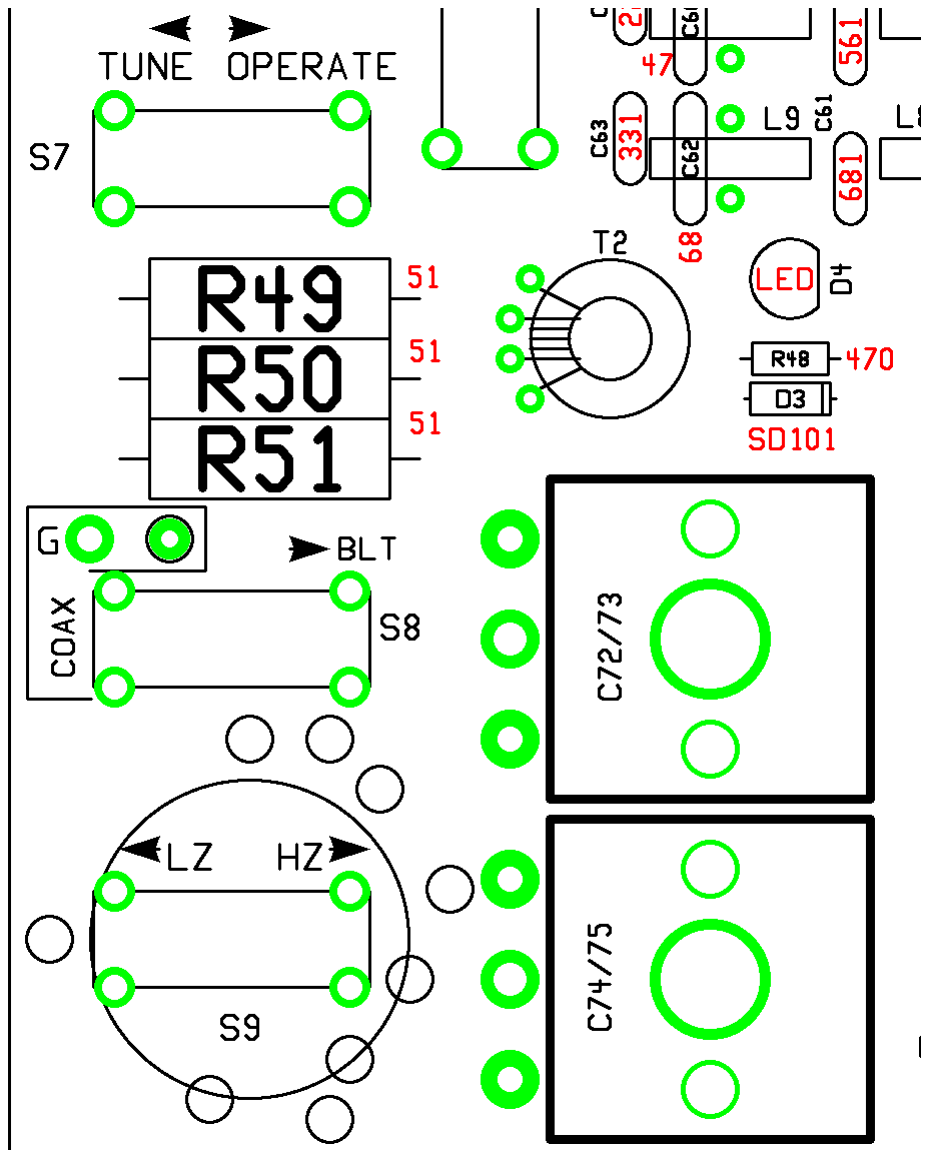
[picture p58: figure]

- R48, 470 ohm (YEL/VOL/BRN)
- R49, R50, R51 - 51 ohm, 2 watt (GRN/BRN/BLK)
- D3 – SD101, small glass diode
- D4 – clear LED – Align flat side of LED with flat on part outline. Long lead goes into hole opposite the flat. Space bottom of LED 5/16” from top of circuit board.
- S7 – DP3T slide switch
- S8 - DP3T slide switch
- S9 – DP3T slide switch – this mounts above T3. Cut pins flush to board after soldering.
- T2 – Black FT43-37 core. Use # 28 wire and wind 25 turns as secondary and 5 turn primary in middle between ends of the secondary turns. Secondary ends go to into the two outside holes and the primary goes into the two middle holes.
- T3 – Mounts on bottom of board. Core is about same diameter as the mounting holes for the wire connections. See below for winding and mounting details.
- C72/73 and C74/75 Poly-variable capacitors. Mount on bottom of board with 2.5 mm washers on screws between board and body of capacitor. These washers space the body of the cap slightly from the bottom of the board. Adjust the trimmers on the bottom of C74/75 to be fully meshed.

Winding T3:

- Cut a 30” (2 1/2 foot) length of the # 24 wire.
- Wind 11 turns on the T100-2 core (this is the large red core)
- Start the winding of the core by passing the starting end of the wire into the hole from the top (side facing you as you hold it) and wind by passing the long end of the wire up from the bottom of the core. Wind the rest of the turns in a counter clock wise direction. Winding the core in this fashion will make the ends of the wire more or less line up with the staggered holes in the board. Try to wind the wire fairly flat to sides of the core.
- Pull the 6th turn slightly away from the middle, outside edge of the core. (this is actually turn 5 ½)
- Scrape away the insulation on the wire of this 6th turn, just a little near the middle of the core.
- Cut a 2” length of the # 24 wire and tin one end.
- Attach this wire to the 8th turn on the core. Make a small, half loop on the end of the wire and lightly crimp to wire on core, then solder.
- Cut a 18” length of the # 24 wire and wind 6 turns inter-weaved between the first winding and centered around the tap you just made, so there are 3 turns on either side of the tap. It is easiest the start the winding of these turns from the center tap of the first winding.
- Now cut a 8” length of the # 24 wire and wind 1 turns on either side of the tap, for a total of 2 turns. This winding will also be inter-weaved between the other two windings.
- Push the windings together so they are close to each other and not spaced around the core.
- The core is mounted to the bottom of the board and the wires are soldered from the top. Suspend the core slightly off the bottom of the board so that the wires do not touch the ends of the switch mounted above it. In fact, it is a good idea to snip the ends of the switch terminals flush to the board before mounting the coil. Be careful not to put the High Z winding into the pads marked “OUT”, as these pads will connect to the binding posts on the cabinet.

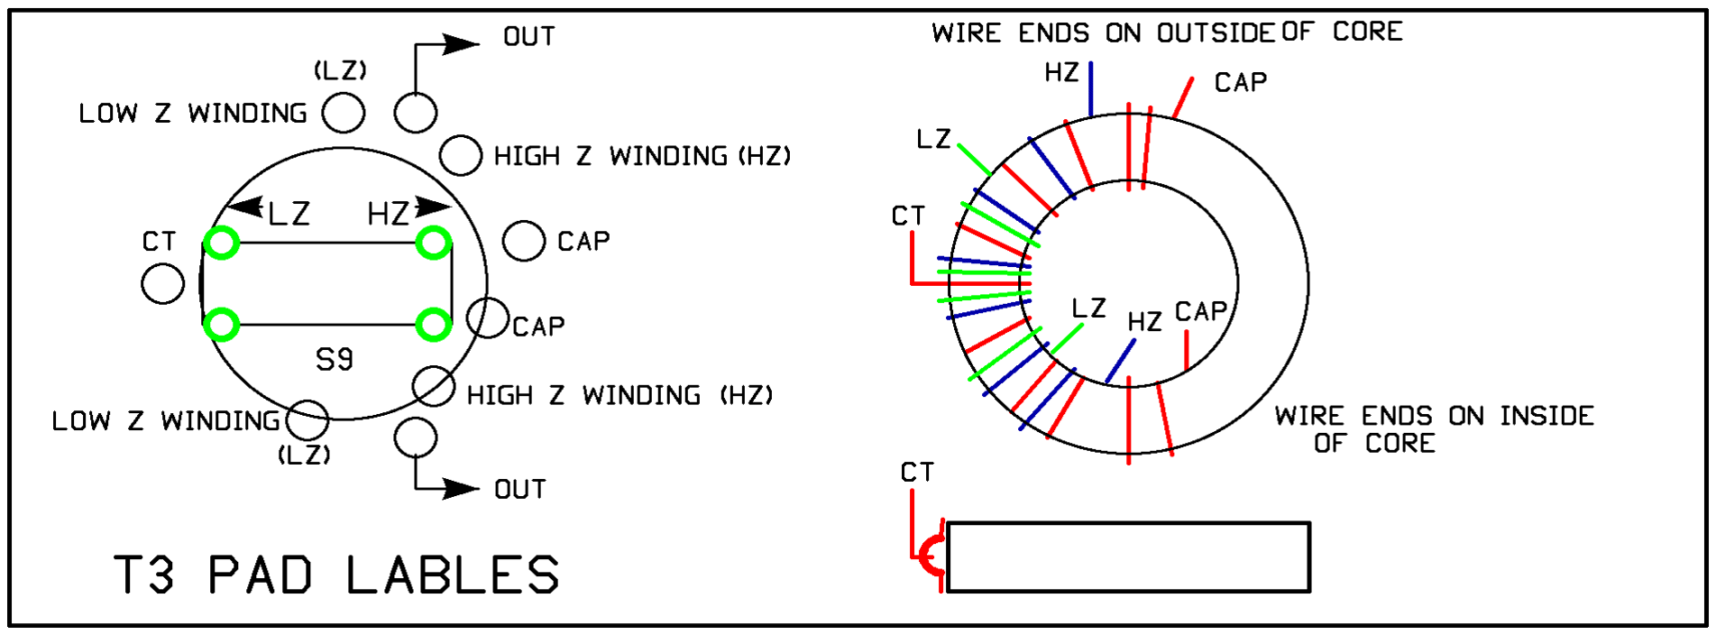
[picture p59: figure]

This diagram shows how the wire should be wound on the core so the wire ends more or less line up with the mounting holes in the board. The LZ winding is shown with an extra 2 turns.

## Final tests:

The board is now complete and the only thing left to test is the transmitter. Connect the BNC jack to the COAX terminals on the board by S9. Now connect a watt meter and dummy load to the jack. Make sure both BAND switches are set to the same band, you might as well start with 40 meters. Set the Tune / Operate switch to the operate position and the COAX / BLT switch to the coax position. Apply power to the board and send some dots. There should be some power output showing on the watt meter. If not, remove power and start looking for missing solder connections, that the insulation on the toroid coils has been soldered through and that both band switches are in the same position. If you see power output, go on and check the other two bands.

Power output
Power output is influenced by both power supply voltage and the way in which the turns on the transmitter low pass filter coils are spaced around the core. To measure full power output, put the rig in straight key mode or use “Tune” mode. With a 12.0 volt supply, power output should be close to 5 watts on all bands, with the possible exception of 20 meters, which seems to be running more like 4.5 watts on average. If power output is higher than 5 watts, move some of the turns on L8, L10 or L12 (depending on the band) closer together and recheck the power output. Repeat if needed to get close to 5 watts output. If power out is less than 5 watts, try making the spacing of the turns more evenly spaced around the core. If power output is significantly lower (or higher) than it should be, double check the number of turns on the coils. Remember, a turn is each time the wire passes through the center of the core. Having one extra turn is common, as many forget to count the first turn when the wire is initially passed through the center of the core. This can have a significant affect on the power output.

## Mounting the board in the cabinet and final wiring:

It is possible to enlarge the holes for the three tuning caps with a step drill so that the knobs are recessed and reduce the overall height of the rig. You will also need to cut down the nylon spacers and screw. If you decide to do this, be careful – you don't want to scratch the paint job on the cabinet!
- Solder the end of a 4.5” length of hook up wire to each of the pads labeled “OUT” under T3. These wires attach to the bottom side of the board. Since T3 covers these holes, the solder connections are made from the top of the board.
- Tape the red acetate filter to the inside of the led window.
- Slide the board into the top piece of the cabinet at an angle with the phone jacks at the front of the board down. To ease mounting, place all slide switches to the center position. Be careful not to bend the SWR led.
- Center the phone/paddle jacks in the chassis holes, and secure the board with the 4-40 x 1/4” screws and lock washers.
- Attach the nylon spacers to the tuning caps with the screw and 2.5mm lock washer. A small drop of super glue into the screw hole on the tuning cap will help keep the screw from coming loose. (You may want to wait until you are sure you will not have to remove the board from the cabinet for some reason before gluing the screw in place)
- Push the brass knob extension all the way down onto the volume control and secure the knob with the set screw. (Personally, I prefer not to use a knob on the volume control, KD1JV)
- Place the three knobs on the tuning caps. Set the knob as low as it can go without rubbing against the cabinet
- Mount the two binding posts, DPDT toggle switch, Coax jack and external power jack to the rear of the cabinet.
- Wire up the binding posts, switch and coax jack as shown in the diagram below. The wires going from the coax jack back to the board should be tightly twisted together and take a direct path back to the pads on the circuit board. The red wire between binding post, switch and coax connector is optional.

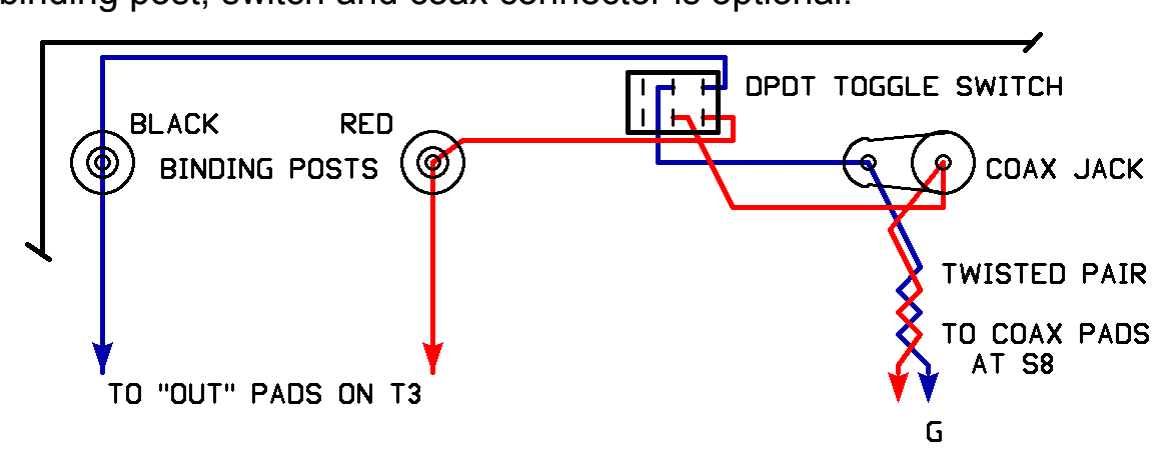
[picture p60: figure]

- Twist two 8” lengths of hook up wire together.
- Solder to external power jack
- Solder the other end to the EXT and GND pads next to the On/Off switch
- The wire for connecting to the power jack to the board should be routed along the outside edge of the board.

Once the wiring from the board to the rear panel is completed it is still possible to remove the board from the cabinet but it is a little tricky to do. Remove the mounting screws and gently push the board towards the rear of the case to free the phone jacks from the holes in the front of the case. Then gently angle the board up. When remounting the board, the main problem might be getting the SWR LED to line back up with the hole.

Photo of final panel wiring

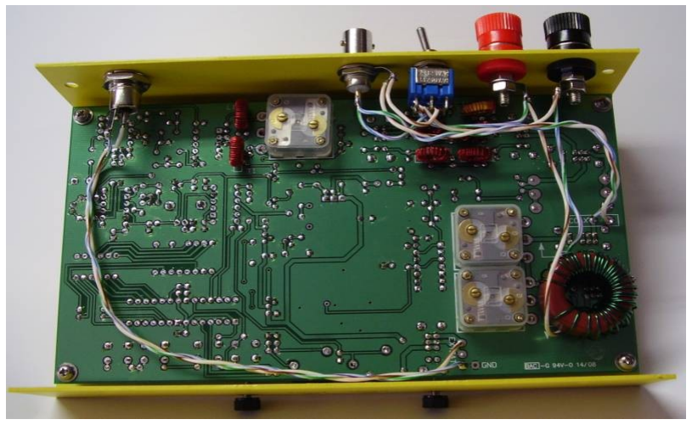
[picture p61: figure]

Battery holder mounting:

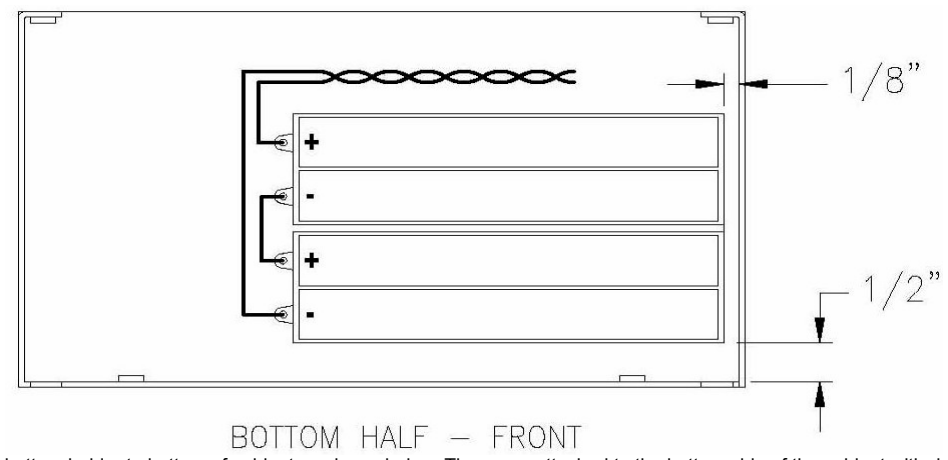
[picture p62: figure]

Mount battery holder to bottom of cabinet as shown below. These are attached to the bottom side of the cabinet with double sided tape, which is already attached to the bottom of the holders. Leave a small space between the sides of the battery holders as when the batteries are installed it will billow out the sides a little. Connect wires to the battery holder terminals as shown the diagram below. Be quick about soldering the wires, as the plastic will melt if you leave the iron on too long. Wire the [+] terminal to pad labeled “BAT” next to power switch and the [-] terminal to the pad labeled “GND”

Fuses:

There are no fuses built into the rig but it is a good idea to add one. A fuse could prevent damage to your power supply or even a fire if something should go wrong. For the external supply, use a power cord with an in-line fuse holder and use a 1.5 or 2 amp fuse. Adding a fuse to the battery pack is a bit more of a problem. A 2AG sized fuse holder could be added to the bottom half of the cabinet just above the battery pack and located so it sits between the power jack and receiver input coils.

## Operation:

Power supply:

The PFR-3 rig should be powered by no more than about 12 volts and no less then 8 volts. Maximum supply current at full transmitter output is typically less than 800 ma. If a 13.8 volt bench supply is used to power the rig, two silicon rectifier diodes should be added in series with the positive supply lead to drop the voltage down closer to 12 volts. This will ensure the rig does not put out more than about 5 watts. 5 watt output at 12 volts was chosen as this is the typical voltage a gel-cell battery settles down to after it has been removed from its charger. Below 8 volts, the 6 volt regulator for the receiver will start to loose regulation. Since transmit power output is dependent on supply voltage, a variable supply is a handy way to adjust the power output level. At the minimum supply voltage of 8 volts, the transmitter will deliver about 2 watts output. Transmitter current will also be reduced at lower supply voltages, extending battery life.

Power switch:

The power switch has three positions. OFF, Internal (battery) power and External power.

When the rig is first turned on, the display will show all “8”s for a second. This is the segment display test. Then the display will indicate the currently selected band , “20”, “30” or “40”. The band numbers will be displayed for a couple of seconds, then the display will change to show the operating frequency. Since only four digits are available, only the 100 kHz to 100 Hz digits are displayed. MHz digits are implied by the currently selected band. The initial operating frequencies loaded when the rig is powered on or the band is changed are 7.030,000 MHz for 40 meters, 10.110,000 MHz for 30 meters and 14.060,000 MHz for 20 meters.

Power save mode:

After about 5 minutes of no switch activity the rig will go into a power save mode by blanking the display and the processor is put to sleep. The decimal point will stay on to indicate that the rig still has power applied. This will reduce the supply current from about 47 ma to 34 ma. Not a huge current savings, but if the rig is being run on batteries every ma counts. The rig will “wake up” if any switch (other than Band) or the paddle is used.

### Selecting operating band:

Two slide switches are used to select the operating band. Both switches MUST be in the same band position for proper operation. The band switch located near the top, center of the cabinet tells the processor which band you want to use and will indicate the selected band on the display for a second when the band is changed or on power up, as noted above. The switch located near the top, left of the cabinet is used to connect the output of the low pass filter to the antenna. If the two band switches are not in sync, there will be no signals in the receiver and the transmitter might be damaged if you transmit at this time. If you change bands and then return to a previously used band, the frequency the rig was tuned to on that band will be restored. This feature could be handy if your jumping between bands in a contest. Operating frequencies are lost when power is turn off and the rig will load the default frequencies again on power up.

After you change bands, you must re-peak the receiver input with the Rx peak control.

## Tuning:

Tuning is done with two push button switches. These switches are operated best by “clicking” them to the side, rather then pushing straight down. Tuning steps are in 50 Hz increments. A momentary click of the switch will change the frequency by 50 Hz. Since the display only has 100 Hz resolution, it will take two clicks of the switch to see a change of frequency on the display. Holding one of the tuning switches closed for longer than about one (1) second will start an auto tune mode, where the frequency will change in 100 Hz steps at a rate of about 10 steps per second, so long as the switch is held closed.
When the switch is released, normal 50 Hz “one click” tuning is restored.

Note: If you are in the fast tuning mode and quickly change tuning directions, the tuning may continue the direction that it was in. This is because there is a slight delay between releasing the switch and the processor detecting that a different switch has been closed.

Tuning limits:
Tuning is restricted to be within the currently selected ham band. This is to prevent out of band transmission. Full band coverage is available. 7.000,000 to 7.300,000 on 40, 10.100,000 to 10.150,000 on 30 and 14.000,000 to 14.350,000 on 20. Even though you can tune into the phone band, SSB signals will not be intelligible due to narrow CW filter.

RIT (receiver incremental tuning)

Clicking the RIT switch will activate RIT. The left most decimal point on the display will light when you are in RIT mode. When in RIT mode, the receive frequency is changed by the tuning switches and the transmit frequency stays were it was when RIT was activated. Clicking the RIT switch again will exit RIT mode and restore the original receive frequency. If RIT is on when the band is changed RIT will be automatically turned off.

DFE mode (direct frequency entry)

This mode allows you to go directly to a specific frequency by entering it in with the paddle. Clicking and holding closed the RIT switch for longer than one (1) second will activate this mode. The display will change to display [- - -.-] when DFE mode is enabled. Enter the frequency you wish to go to, starting with the 100 kHz digit and finishing with the 100 Hz digit. As each digit is entered, it will be shown on the display and shift from right to left as additional digits are entered. If a number is not recognized, a “?” will be sent by the side tone. Once the 100 Hz digit is entered, the rig will re-tune to that frequency provide it is within the normal tuning limits of the current band. If it outside the band, the frequency at which the rig was tuned to when DFE was enabled will be restored and DFE mode exited. If you make a mistake or wish to exit the DFE mode at anytime before the 100 Hz digit is entered, you can escape by clicking any of the switches.

Note: DFE mode is not available in straight key mode or if RIT is on.

MENU switch (Keyer functions) :

The MENU switch is used to access various keyer functions. Which function is selected is determined by how long the switch is held closed. Keyer functions are selected in this order: send message, change keyer speed, TUNE mode, enter messages and select iambic A or B mode of operation. Note: When in straight key mode, none of the MENU switch functions are available, with the exception of sending keyer message 1, assuming a message is already stored in that location.

Sending a Message:
Two, 63 character (including word spaces) Morse messages can be stored in memory. One of these messages can be sent by first clicking and releasing the KEYER switch and then tapping the DOT paddle to send message one, or tapping the DASH paddle to send message two. This must be done within 1 second of releasing the switch or the change code speed mode will be activated. Once a message has started sending, it can be terminated by closing the DOT paddle. If a character is being sent at the time of dot or dash closure, it must be held closed until that character has finished being sent.

When in straight key mode, only message 1 is available, as the DASH input is always grounded by the straight key plug.

Changing keyer code speed:

If sending a message has not been selected using the paddle after clicking and releasing the MENU switch, speed change mode will be activated. The current code speed is shown on the display as [C xx], where xx is the current speed. Keyer speed is changed by closing either the DOT paddle to increase speed or closing the DASH paddle to decrease speed. The selected speed is shown on the display. Once the desired speed is indicated on the display, release the paddle and wait about two (2) second and speed select mode is automatically exited.

Tune Mode:
This mode is used if you have an automatic antenna tuner which needs to see a steady carrier for a few seconds to operate. For manual tuners, it is easier and less stressful on the PA to simply send a string of dots as you fiddle with the tuner.

To enable tune mode, click and hold close the MENU switch until the letter “T” is annunciated by the side tone and release the switch. When you then release the MENU switch, the display will blank and a character which resembles a lower case “t” will appear on the left most digit. The transmitter can now be keyed by closing and holding closed either the dot or dash paddle. When you wish to return the rig to normal operation, click any of the switches.

Storing a message:

Holding closed the MENU switch for four (4) seconds will active the message entry mode. Release the switch when the letter “M” is annunciated by the side tone, which occurs after the tune mode letter “T” has been annunciated. The receiver is then muted and you can now start to enter your message by using the paddle. If you accidentally activate this mode and do not wish to enter a message, click the MENU switch to abort before touching the paddle. The Letter “X” will be annunciated and the rig will go back to normal operation. There is no visual indication that message entry mode is active.
Up to 63 characters (including word spaces) may be entered. If you exceed this limit, the letters “EM” will be annunciated by the side tone and you will have to start again. Note that “ideal” letter and word timing is used to determine letter element groups and word groups. Of these two, the letter timing is most critical. If do not pause long enough before starting a new letter, a letter space will not be detected. If you pause too long, it will be interpreted as a word space. It may take some practice to enter a message correctly. I ensure a word space is inserted, it is best to pause somewhat longer than you normally would between word letter groups.

When you have finished entering the message, click the MENU switch. The message you have entered will be sent by the side tone so you can check the accuracy of the message. If it sounds good, store it by closing either the DOT or DASH paddle. DOT will store it into message location 1 and DASH into location 2. If you wish to redo the message, click the KEYER switch again. “EM” will be annunciated by the side tone and you can now re-enter the message.

Selecting Iambic A or B modes.
Iambic A mode is the default keyer mode. To switch to B mode or back to A mode, hold the MENU switch closed for about four (4) seconds until the letter A or b appears on the display (b looks like a 6 on the display) then release the switch. The letter which appears on the display will be the mode the keyer will be set to when you release the switch. The Morse letter “A” or “B” is also annunciated by the side tone.

The difference between A and B modes:
In A mode, if both paddles are closed at the same time, alternating code elements are sent. If you close the dash paddle first and then hold both the dash and dot paddle closed, the keyer will send dah-dit-dah-dit-dah so long as the paddles are held closed. When the paddles are released, the keyer will simply stop sending at the end of the code element which might be being sent at the time the paddles are released, if any.

In B mode, alternating code elements are also sent when both paddles are closed, but this time an extra and opposite code element will be tacked on the end of the string when the paddles are released. Therefore, to send a letter such as “K”, you just have to close the dash paddle first, then close the dot paddle and release both paddles when the dot starts to be sent. dah-dit-dah will be automatically sent. In A mode to send this same letter you would have to keep the dash paddle closed until the second dash has started to be sent before releasing the paddles.

In B mode, the “both paddles closed” condition is sensed at the end of the inter-element space. Therefore, to insert an extra element, both paddles need to be held closed at least until the next to last element you want to send is has started. If the “both paddles closed” condition is sensed any earlier, it is nearly impossible to send a simple letter such as an “A” or “N” and not have a “R” or “K” be sent instead. Even so, it is easy to accidentally add an extra element if your not quick to release the paddles which makes B mode a bit difficult to get the hang of with out a lot of practice, especially at higher code speeds.

Both A and B modes have dot and dash memory while an element is being sent. So, if you tap the dot paddle while a dash is being sent, the dot will be sent after the dash is finished and vice-a-versa.

Straight key mode:

If a monaural plug is in the paddle jack at power up (the sleeve grounds the dash input pin), the rig will power up in straight key mode. This allows using either a straight key or external keyer. While in straight key mode, none of the keyer switch functions will be available. If a message has been previously stored in the keyer memories, only memory location 1 will be available, (tap the straight key closed with in 1 second of clicking the keyer switch) as this is selected with the dot input pin, now controlled by the straight key.

Using the SWR bridge and BLT tuner:
Note that S7, S8 and S9 are three position switches but only two positions are used. The two positions to the left are the same.

TUNE / OPRT SWITCH:

Sliding S7 to the TUNE position switches in the SWR bridge. The LED will now indicate the relative amount of SWR. The brighter the LED, the higher the SWR is. When the LED is not lit or is very dim indicates 1:1 SWR.

COAX / BLT SWITCH

S8 is used to switch between a direct coax connection to the BNC jack or the BLT (balanced line tuner). The Coax position is of course used if you are using a resonate, coax feed antenna or an external tuner. The BLT position is used when the built in tuner is desired and is normally used with ladder line feed antennas, but can also be used for end feed antennas or possibly matching coax feed antennas which need a little tweaking.

Using the BLT:

Note: The handle of the switch on the rear panel should be slanted towards the coax jack when using either a balanced line on the binding posts or just a coax feed antenna.

Before transmitting, adjust the TUNE and LOAD capacitors for best band noise or signal strength. Now switch from Operate to Tune mode with S7. Now transmit a string of dits or dahs and fine tune the TUNE and LOAD capacitors so that the SWR LED gets very dim. This of course, is easier said than done. The tuning is very sharp and if you tune too fast you will never see the LED get dim. A further complication is the Load and Tune controls are interactive.

First slowly adjust the LOAD until you see even the slightest dimming of the LED. Now adjust the TUNE and see if you can make it even dimmer. Go back to LOAD and see if this will dim the LED farther. If no farther improvement can be made, advance the TUNE slightly (try clockwise first) which will make the LED brighter again, then try the LOAD. Working back and forth a few time between the Tune and Load controls should enable you to make the LED become very dim or go out completely. In most cases when using a ladder line feed antenna, you will use the HI-Z setting of the BLT. In some cases, you may only be able to find a match using the Low-Z setting.

Once you find the match, you might want to mark the positions of the controls on the panel using some stick on dots. This will speed up retuning after switching bands.

Using the BLT with end feed wire antennas or coax.
Switching the handle of the rear panel switch so it faces the binding posts will ground the black balanced line binding post and connect the Red post to the coax jack. End feed wire antennas can now be connected to the Red binding post and a counter pose to the Black post. Use the High Z position of S9 if the wire is near a 1/2 wave in length. Use the Low Z position if the wire is near a ¼ wave or less in length. The Low Z position is also used when using the BLT to match a coax feed antenna.

Using a speaker instead of headphones:

The amount of current the audio amplifier can deliver to a speaker is limited by the current available from the 78L06 regulator. A small, efficient speaker at low or modest volume should be alright. However, it would be a good idea to use an amplified speaker such as those used for PC sound, as this would keep the load on the PFR audio amplifier to a minimum.

Also, since the PFR does not have AGC, be careful when using in-the-ear “ear bud” type headphones. Turn the volume control down when tuning across the band so that if you run across a strong station, it does not blow your ears off!

Paddle wiring:
The paddle jack uses “standard” wiring:

Tip is Dot
Ring is Dash
Sleeve is ground

There is no paddle sense reverse built into the firmware.

PFR front panel controls and rear panel connectors.

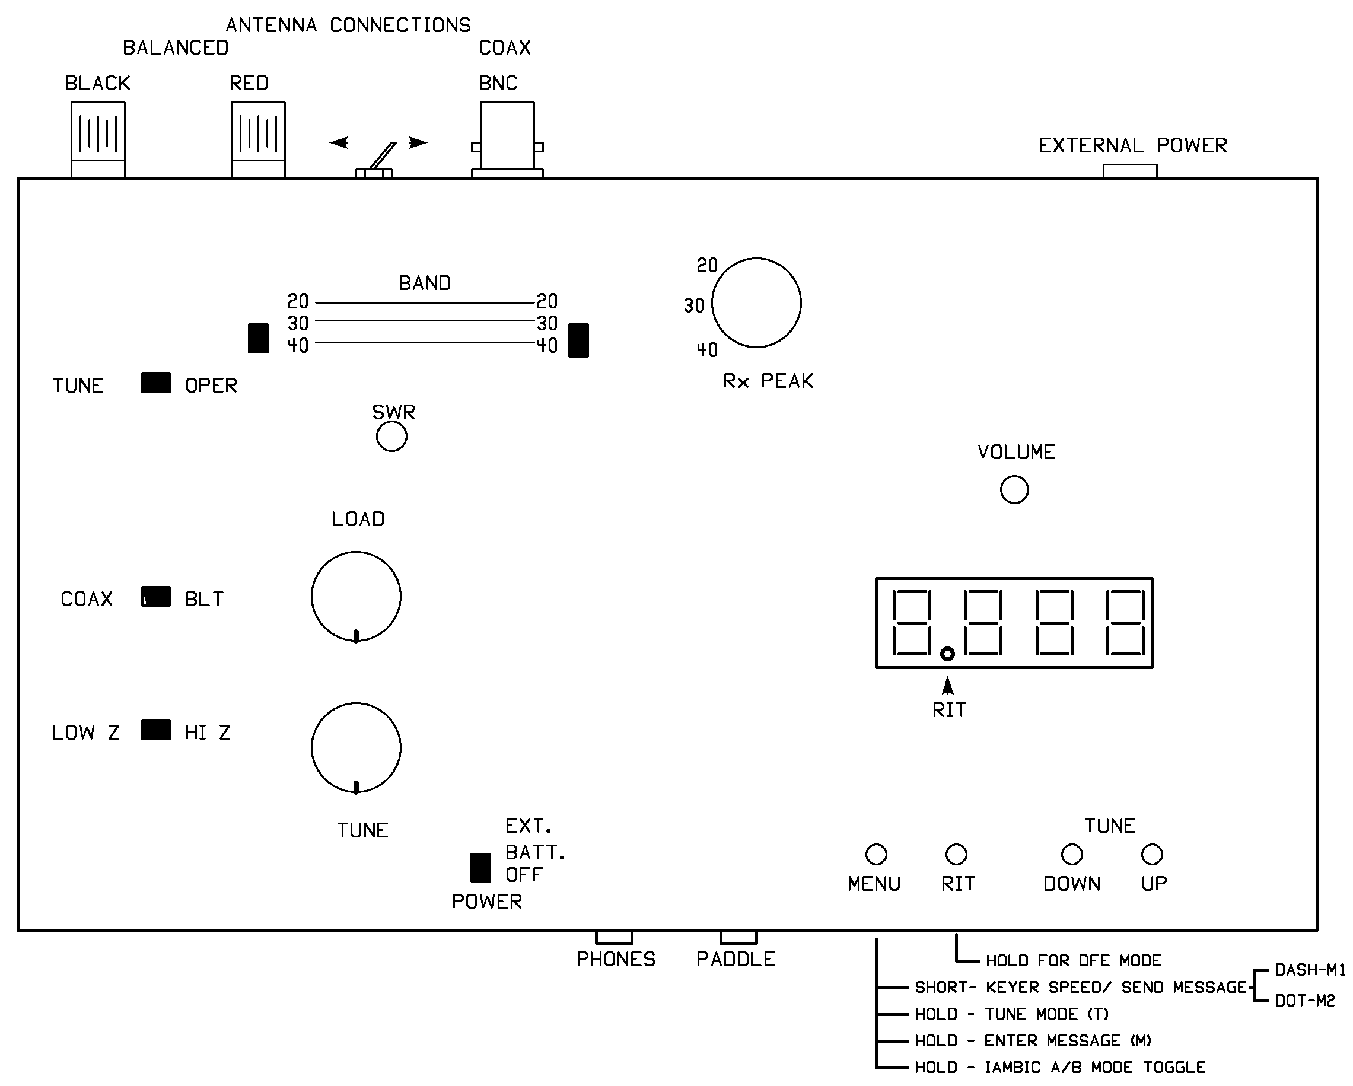
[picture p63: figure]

## Troubleshooting:

With careful assembly, your PRF-3 kit should work right off. Unfortunately, this is not always the case and some troubleshooting will be required. This job goes a lot quicker if you have a signal generator, Oscilloscope and frequency counter, but alas, most of you will only have a DVM to work with.

The most common reason a kit does not work is because of assembly errors, the most common being soldering issues. Soldering issues include missing solder connections, solder shorts between pads which are not connected together, not using enough heat in places so solder only sticks to a component lead and does not flow into the solder pad and not properly tining magnet wire leads so there is no continuity through a coil. Less common but still something to look for is miss-placed parts. It is often easy to miss-read the color codes on resistors, especially those with similar colors, but in a different order.

The above problems can often be found with a simple but careful visual inspection of the board. It does help to have an idea of which general area the problem maybe in as to narrow down the search.

Bad parts:
All new, prime parts are supplied with the kit. It is very, very unlikely any were bad prior to installation. Unless the part was physically damaged during assembly, it is safe to assume the part is good. However, some parts, in particular, the 2N7000 and BS170 MOSFETs can be damaged by static while handling and soldering. Some of the ICs can be damaged if they are installed backwards in the socket and power applied. However, since the regulators which supply voltage to the ICs have limited current capability and have over current shut down, it is quite likely the IC will survive being installed backwards.

## Troubleshooting steps: Divide and conquer

The best way to find out what doesn't work is to first find out what does work. The first step is to make sure proper power supply voltages are present. If the output of a regulator is lower than it should be and/or the package is getting hot, something is dragging the output down. This could be caused by one of the aluminum electrolytic capacitors being installed backwards, a solder short or an IC plugged in up side down.

The next step is to check the voltages on the IC pins. If one or more of these voltages are off significantly, it may not mean the IC is bad, but something is affecting the voltage on that pin. Before asking for a replacement part, check the parts connected to those pins and of course, the soldering in that area.

If you still have a problem, its time to start tracing the signal paths. For the receiver, it is easiest the start with the output and work towards the input. For the transmitter, start at the input and work towards the output.

Group 1, the processor and display:
There is very little go wrong here. If the processor is getting it's +5 supply, it should work. Although there could be problems with things connected to the various input and output pins which will affect it's operation. If there is a missing segment or digit on the display, it is likely there is a missing solder connection or short. The same is true if a paddle or the switches don't work or there is a “stuck switch” problem.

Group 2, the receiver:
The audio stages are very easy to test. You should hear some “hiss” when the volume control is turned all the way up and you should hear the side tone when using the paddles. You should be able to hear 60 cycle hum if you touch pins 4 and 5 of U2 with your fingers. If you hear the side tone but not any hiss or hum which touching pins 4 and 5 of U2, the mute switch Q4 might be shorted out. If the voltages on pins 3 and 5 of U3 are not correct, C24 might be in backwards or the R7 and R12 values interchanged.

The crystal filter and U2 product detector/ BFO oscillator is tested when using the DDS offset calibration mode. There is little to go wrong here other than soldering problems.

Still no luck getting the rig to work?

We will try to first help you via email. Sometimes we can nail the problem right off, but often it can be of no real help. We can't look over your shoulder to see whats going on and we're not psychic! Often, we can't do much more than repeat what has already been said in the above troubleshooting guide. To be of help we need as much information as possible about the problem. Simply saying that it does not work is of little use.

If all else fails, a repair service is available for a flat $35.00 fee. If you want the rig to be insured on return shipping, add another $5.00. DX stations will also have to add extra funds to cover air mail postage. It would be helpful if a short note explaining what kind of problem your having is included. We will try to repair and return the rig as quickly as possible, but it could take a few weeks in some cases, depending on other work loads from the day job.

Send the rig with a check or MO for the repair fee to:

Steven Weber, KD1JV
Steve's Electronics
633 Champlain St
Berlin, NH 03570

IC pin voltage charts: Small deviations from listed voltages acceptable due to DVM and voltage regulator tolerances

Note: LED display driver pin voltage vary with digits displayed so typical voltages not shown

IC U1, U2 SA612 mixer

Pin 1 | 1.4 V | IN
Pin 2 | 1.4 V | IN
Pin 3 | 0 V | GND
Pin 4 | 3.8 V | OUT
Pin 5 | 3.8 V | OUT
Pin 6 | 5.9 V | OSC
Pin 7 | 5.4 V | OSC
Pin 8 | 6.0 V | V+

IC U3 LM358 op amp

Pin 1 | 3.0 V | OUT
Pin 2 | 3.0 V | - IN
Pin 3 | 3.0 V | + IN
Pin 4 | 0 V | GND
Pin 5 | 3.0 V | + IN
Pin 6 | 3.0 V | - IN
Pin 7 | 3.0 V | OUT
Pin 8 | 6.0 V | V+

IC U4 LM386 audio amp

Pin 1 | 1.25 V | feedback
Pin 2 | 0 V | - IN
Pin 3 | 0 V | + IN
Pin 4 | 0 V | GND
Pin 5 | 2.9 V | OUT
Pin 6 | 6.0 V | V+
Pin 7 | 3.0 V | Bypass
Pin 8 | 1.25 V | feedback

## IC U6 MEGA 48 MPU processor

Rx | Tx | Pin function
Pin 1 | 5.0 V | 5.0V | reset
Pin 2 | 5.0 V | 5.0 V | DDS CLK
Pin 3 | 5.0 V | 5.0 V | DDS EN
Pin 4 | 5.0 V | 0 V | Paddle DOT in
Pin 5 | 5.0 V | 0 V | Paddle DASH in
Pin 6 | ------- | ------- | Digit 3
Pin 7 | 5.0 V | 5.0 V | Vcc
Pin 8 | 0 V | 0 V | GND
Pin 9 | -------- | -------- | Decimal point
Pin 10 | ------- | --------- | “d' segment
Pin 11 | -------- | --------- | Digit 1
Pin 12 | -------- | --------- | Digit 2
Pin 13 | -------- | --------- | Digit 4
Pin 14 | -------- | --------- | “e” segment
Pin 15 | -------- | --------- | “f” segment
Pin 16 | ---------- | --------- | “b” segment
Pin 17 | --------- | -------- | “g” segment
Pin 18 | --------- | -------- | “a' segment
Pin 19 | --------- | --------- | “e” segment
Pin 20 | 5.0 V | 5.0 V | AVcc
Pin 21 | 5.0 V | 5.0 V | Aref
Pin 22 | 0 V | 0 V | GND
Pin 23 | 5.0 V | 5.0 V | A/D switch input
Pin 24 | 2.5/1.5/.22 | Same | A/D Band input
Pin 25 | 0 V | 5.0 V | MUTE out
Pin 26 | 0 or 5 V | 2.5 V | Side tone out
Pin 27 | 0 V | 5.0 V | Tx enable
Pin 28 | 5 or 0 V | 5 or 0 V | DDS Data

## IC U8 74HC02 NOR GATE

Rx | Tx
Pin 1 | 0 V | 5V square wave | out
Pin 2 | 0 V | 0 V | in
Pin 3 | 3.5V | 3.5V square wave | in
Pin 4 | 5V | 5V | out
Pin 5 | 0V | 0V | in
Pin 6 | 0V | 0V | in
Pin 7 | 0V | 0V | GND
Pin 8 | 0V | 0V | in
Pin 9 | 0V | 0V | in
Pin 10 | 5V | 5V | out
Pin 11 | 3.5V | 3.5V square wave | in
Pin 12 | 0V | 0V | in
Pin 13 | 0V | 5V square wave | out
Pin 14 | 5.0 V | 5.0V | Vcc
Pins 1 and 13 will measure about 2.5 volts with DVM when transmitting steady carrier.

## Schematics:

## Receiver audio

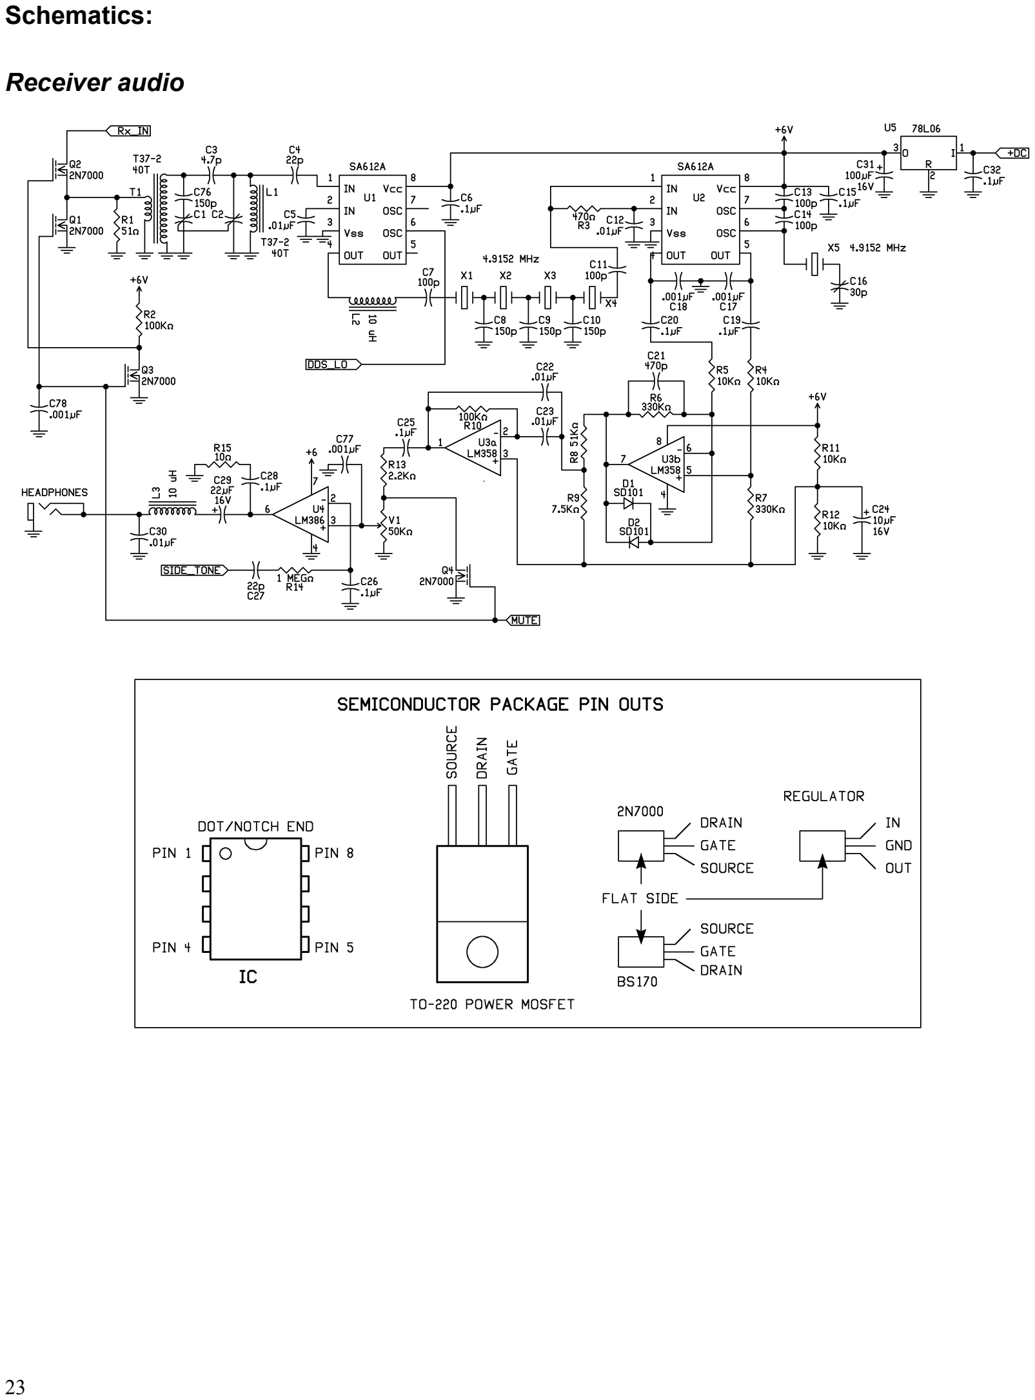
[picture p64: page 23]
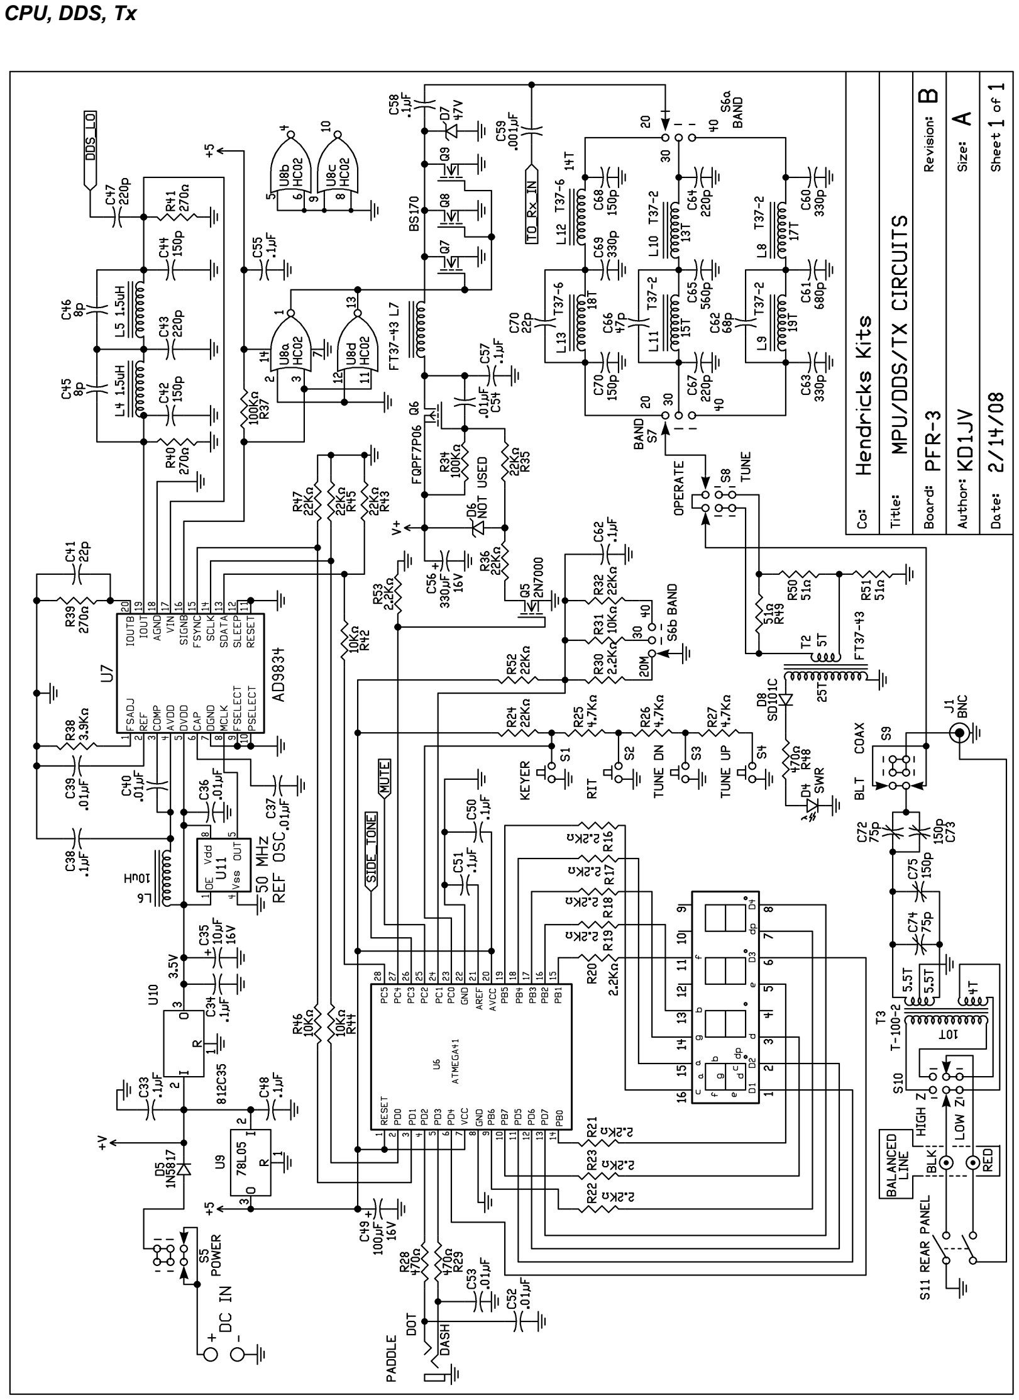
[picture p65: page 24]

CPU, DDS, Tx

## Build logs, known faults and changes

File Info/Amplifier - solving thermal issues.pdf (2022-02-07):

thestone.zone (http://thestone.zone/radio/2021/01/14/capacitors.html)

## Amplifier - solving thermal issues

4-5 minutes

Last time, (http://thestone.zone/radio/2021/01/10/hellschreiber-transmit.html) my amplifier worked great. I did some testing on the air, got 8 watts of power out, etc. But one issue popped up – transmitting for a little while heated something up and produced some odd changes in power output and current consumption. With some gracious and patient help from some smart people, I’ve figured out what caused it, fixed it, and come out way ahead of where I thought I was!

### Describing the problem

When I would key up the transmitter, the power amplifier would produce 8W. But after 5 seconds it would hit 8.9W; after 10 seconds, 11.42W; and at 19.8 seconds 13.1W! Worse, though, shortly thereafter, power would drop to about 3 watts, with an increase in current consumption.

It was my understanding that it shouldn’t be thermal runaway, since I am using MOSFETs. But I couldn’t really find any articles or discussions that matched what I was seeing. So I posted on QRZ, (https://forums.qrz.com/index.php?threads/curious-thermal-behavior-in-amplifier.743786/) hoping the homebrew intelligentsia could help me out.

### Answers obtained!

Things started to make sense when I went through all the things that get hot when transmitting. The output transformer gets pretty warm; the low pass filters got similarly warm. But what got

Amplifier - solving thermal issues | about:reader?url=http%3A%2F%2Fthestone.zone%2Fr...
1 of 5 | 11/4/21, 14:08

really, really hot was the capacitors in the low pass filter…

The QRZ wizards suggested my capacitors were not spec’d for the voltage levels I was throwing at them, and probably not a type that’s ideal for RF. Since I just grabbed them out of a bulk pack I had sitting around (which doesn’t even include references or specs), that seemed like a pretty good working theory.

At the power levels I was seeing, voltage levels would be hitting 30-50v. So I needed to replace them with something better. Here is the “before” shot of the low pass filter:

And, since it will turn out to be relevant, my sweeps with the NanoVNA had shown somewhat lackluster performance (note the roughly 2.2 dB insertion loss!):

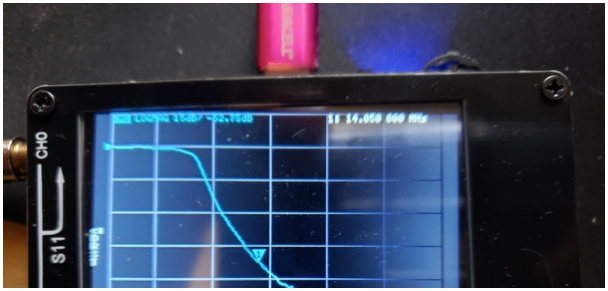
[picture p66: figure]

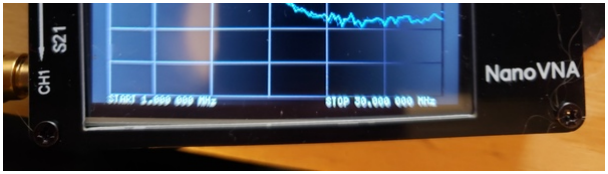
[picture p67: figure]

Apologies for the blurry image, it’s the only image I have from way back then!

### Pretty blue capacitors

I ordered some TDK caps (https://www.mouser.com/ProductDetail/810-FG24C0G2W102JNT6/) rated for 450v. They sure were expensive (as capacitors go), but the blue color looked nice. Mouser even upgraded my shipping to overnight, and they showed up the next day!

I removed the old yellow capacitors, and replaced them. Now the filter looks really snazzy:

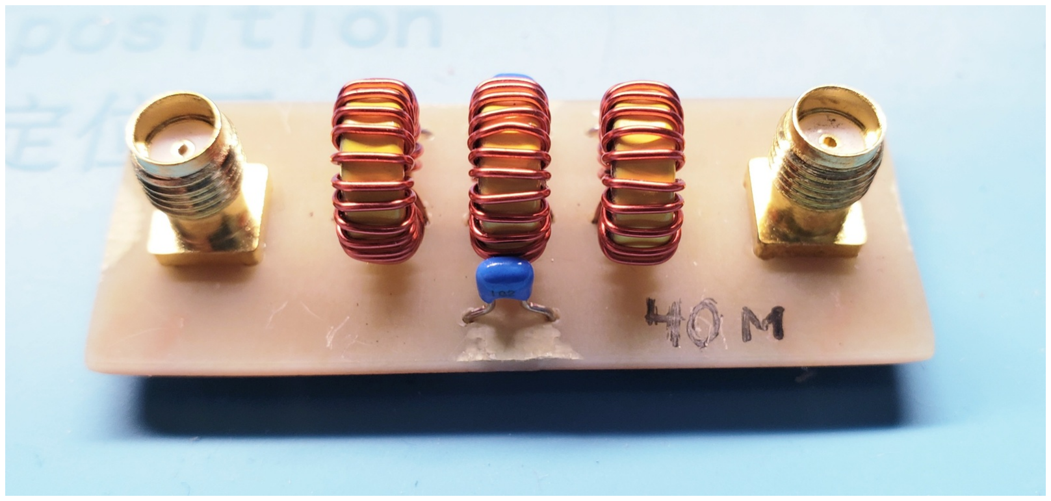
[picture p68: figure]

What was even more exciting was the VNA results. Only half a dB of loss at 7MHz, and a couple more dB down at the harmonics. The cutoff frequency moved up a bit, but not enough to be a problem. This is a useful experience for me – I’ll never use cheap capacitors in a filter again!

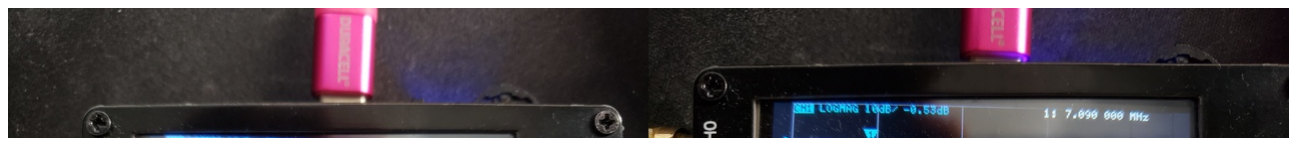
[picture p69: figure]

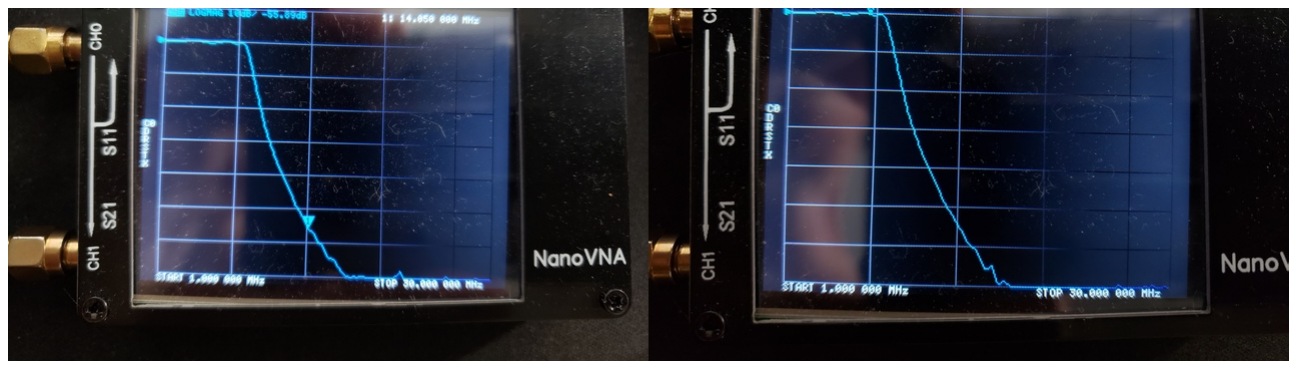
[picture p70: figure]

### Testing with the transmitter

So, with initial indications suggesting this is now a much nicer filter, I attached it inline with the transmitter, and fired it up. I was greeted with this beautiful result on the oscilloscope:

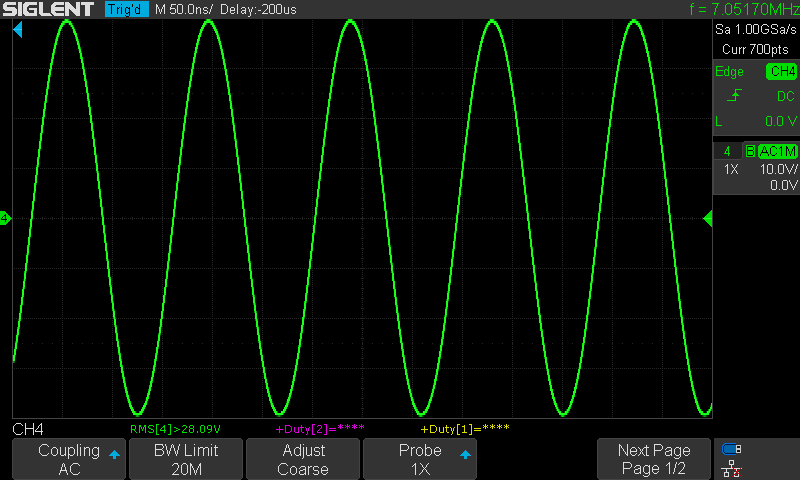
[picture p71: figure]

Just over 15 watts, and it was instant. No thermal variation – change over 30 seconds keyed up was less than 0.2 Vrms. I was so surprised initially, that I at first thought I’d left the dummy load disconnected. Nope, it was connected, and the measurement was real!

### Conclusions

I will pay much more attention to voltage ratings on capacitors. And I need to buy a stock of new ones that are more suitable for RF projects.

And my amplifier works a whole lot better than I thought it did. I just couldn’t see it because of the inadequate low pass filter.

This design is simple, hits a much higher power level than I ever really planned for in my future digital transceiver design. There are still a couple things worth playing with on this design, but it should work well for a full-suite transceiver.

Finally, the satisfaction of hunting down, learning some things, and solving an interesting problem is great. I’m especially thankful for some of the online community resources available to me. I don’t really have anyone local I can ask these kinds of questions, and the willingness of others who know so much more than me to answer my silly questions is wonderful.

Next time might be receiver stuff!

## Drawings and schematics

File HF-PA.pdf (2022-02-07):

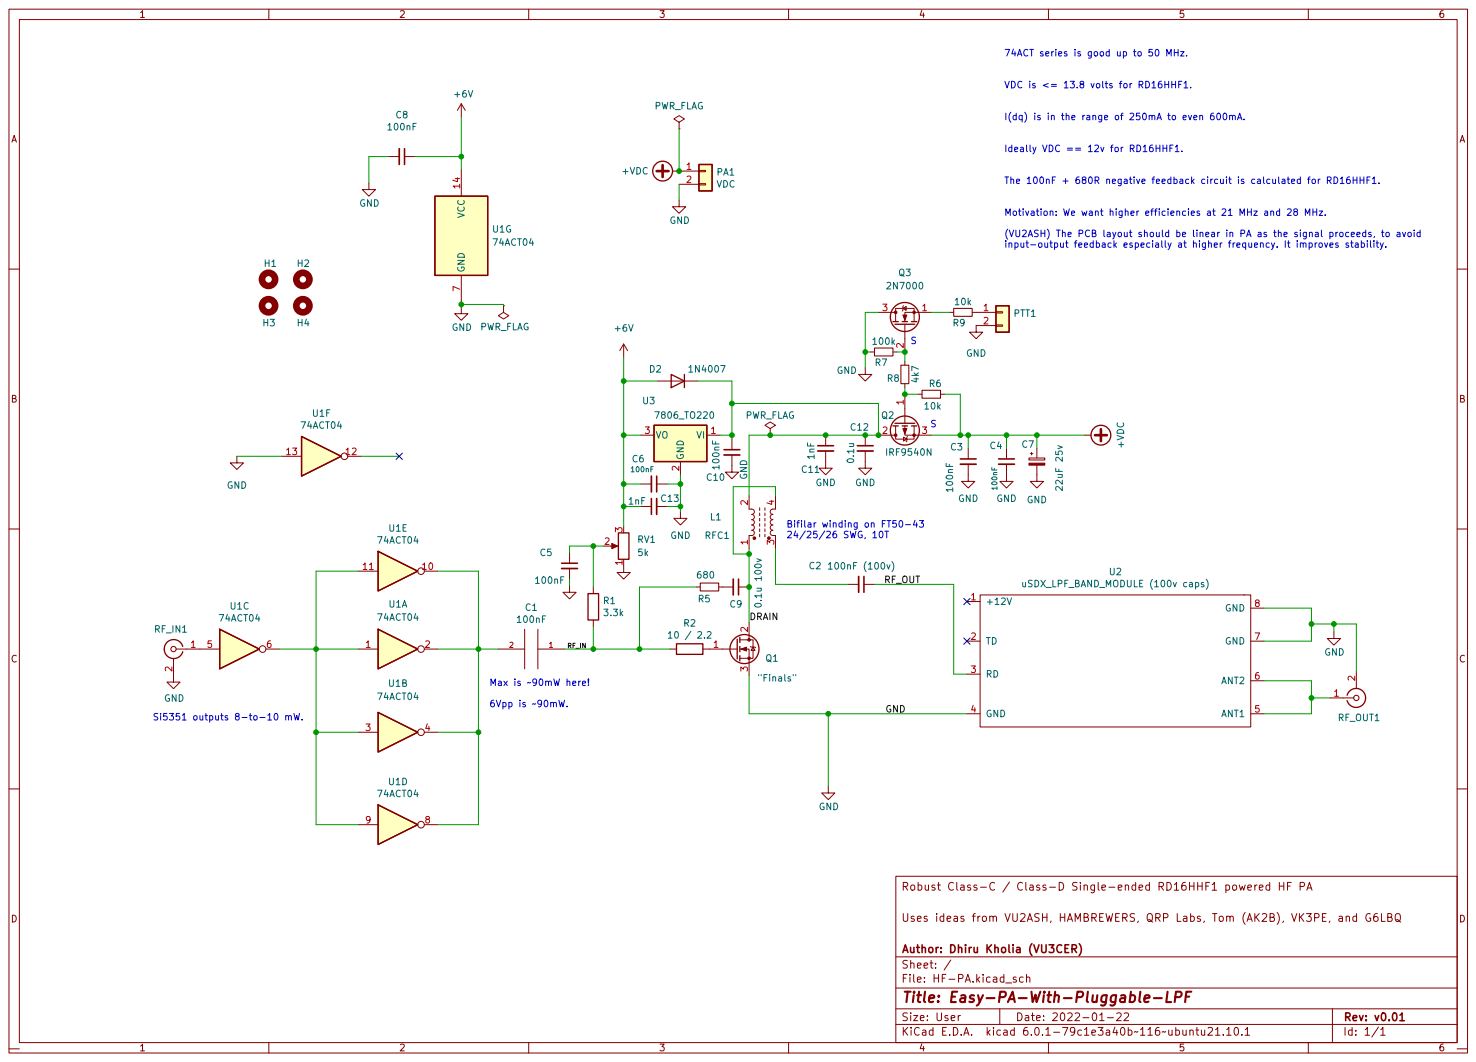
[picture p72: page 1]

74ACT series is good up to 50 MHz. VDC is <= 13.8 volts for RD16HHF1.

I(dq) is in the range of 250mA to even 600mA.

The 100nF + 680R negative feedback circuit is calculated for RD16HHF1.

Motivation: We want higher efficiencies at 21 MHz and 28 MHz.

(VU2ASH) The PCB layout should be linear in PA as the signal proceeds, to avoid

input-output feedback especially at higher frequency. It improves stability. S

Robust Class-C / Class-D Single-ended RD16HHF1 powered HF PA

Uses ideas from VU2ASH, HAMBREWERS, QRP Labs, Tom (AK2B), VK3PE, and G6LBQ

File: HF-PA.kicad_sch Sheet: / Author: Dhiru Kholia (VU3CER)

Id: 1/1 Title: Easy-PA-With-Pluggable-LPF

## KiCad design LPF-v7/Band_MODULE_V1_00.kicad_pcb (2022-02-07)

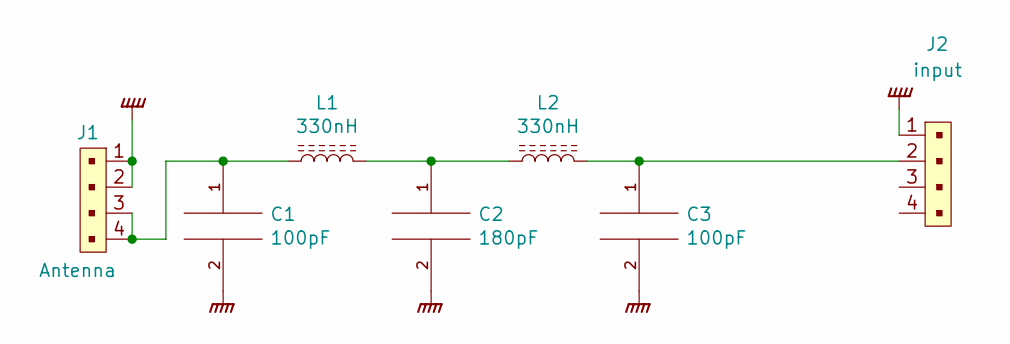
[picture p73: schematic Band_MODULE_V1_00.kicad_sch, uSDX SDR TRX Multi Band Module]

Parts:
C1, C3: 100pF; C_Disc_D5.0mm_W2.5mm_P2.50mm
C2: 180pF; C_Disc_D5.0mm_W2.5mm_P2.50mm
J1: Antenna; PinHeader_1x4_P2.54mm_Drill1.02mm; MPN 0022232041; Digi-Key_PN WM4202-ND
J2: input; PinHeader_1x4_P2.54mm_Drill1.02mm; MPN 0022232041; Digi-Key_PN WM4202-ND
L1, L2: 330nH; L_Toroid_Vertical_L10.0mm_W5.0mm_P5.08mm

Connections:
GNDPWR: C1.2, C2.2, C3.2, J1.1, J1.2, J2.1
unnamed: C1.1, J1.3, J1.4, L1.1
unnamed: C2.1, L1.2, L2.1
unnamed: C3.1, J2.2, L2.2

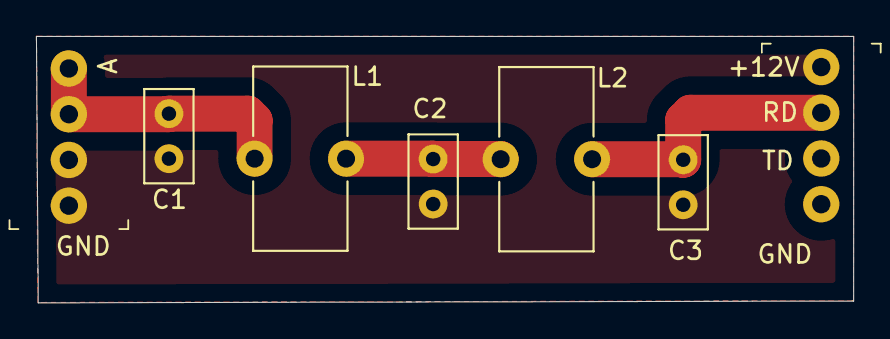
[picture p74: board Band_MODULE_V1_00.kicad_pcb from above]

Board: 2 copper layers, 45.4 x 14.8 mm, 7 parts (0 on the bottom side), 4 nets.

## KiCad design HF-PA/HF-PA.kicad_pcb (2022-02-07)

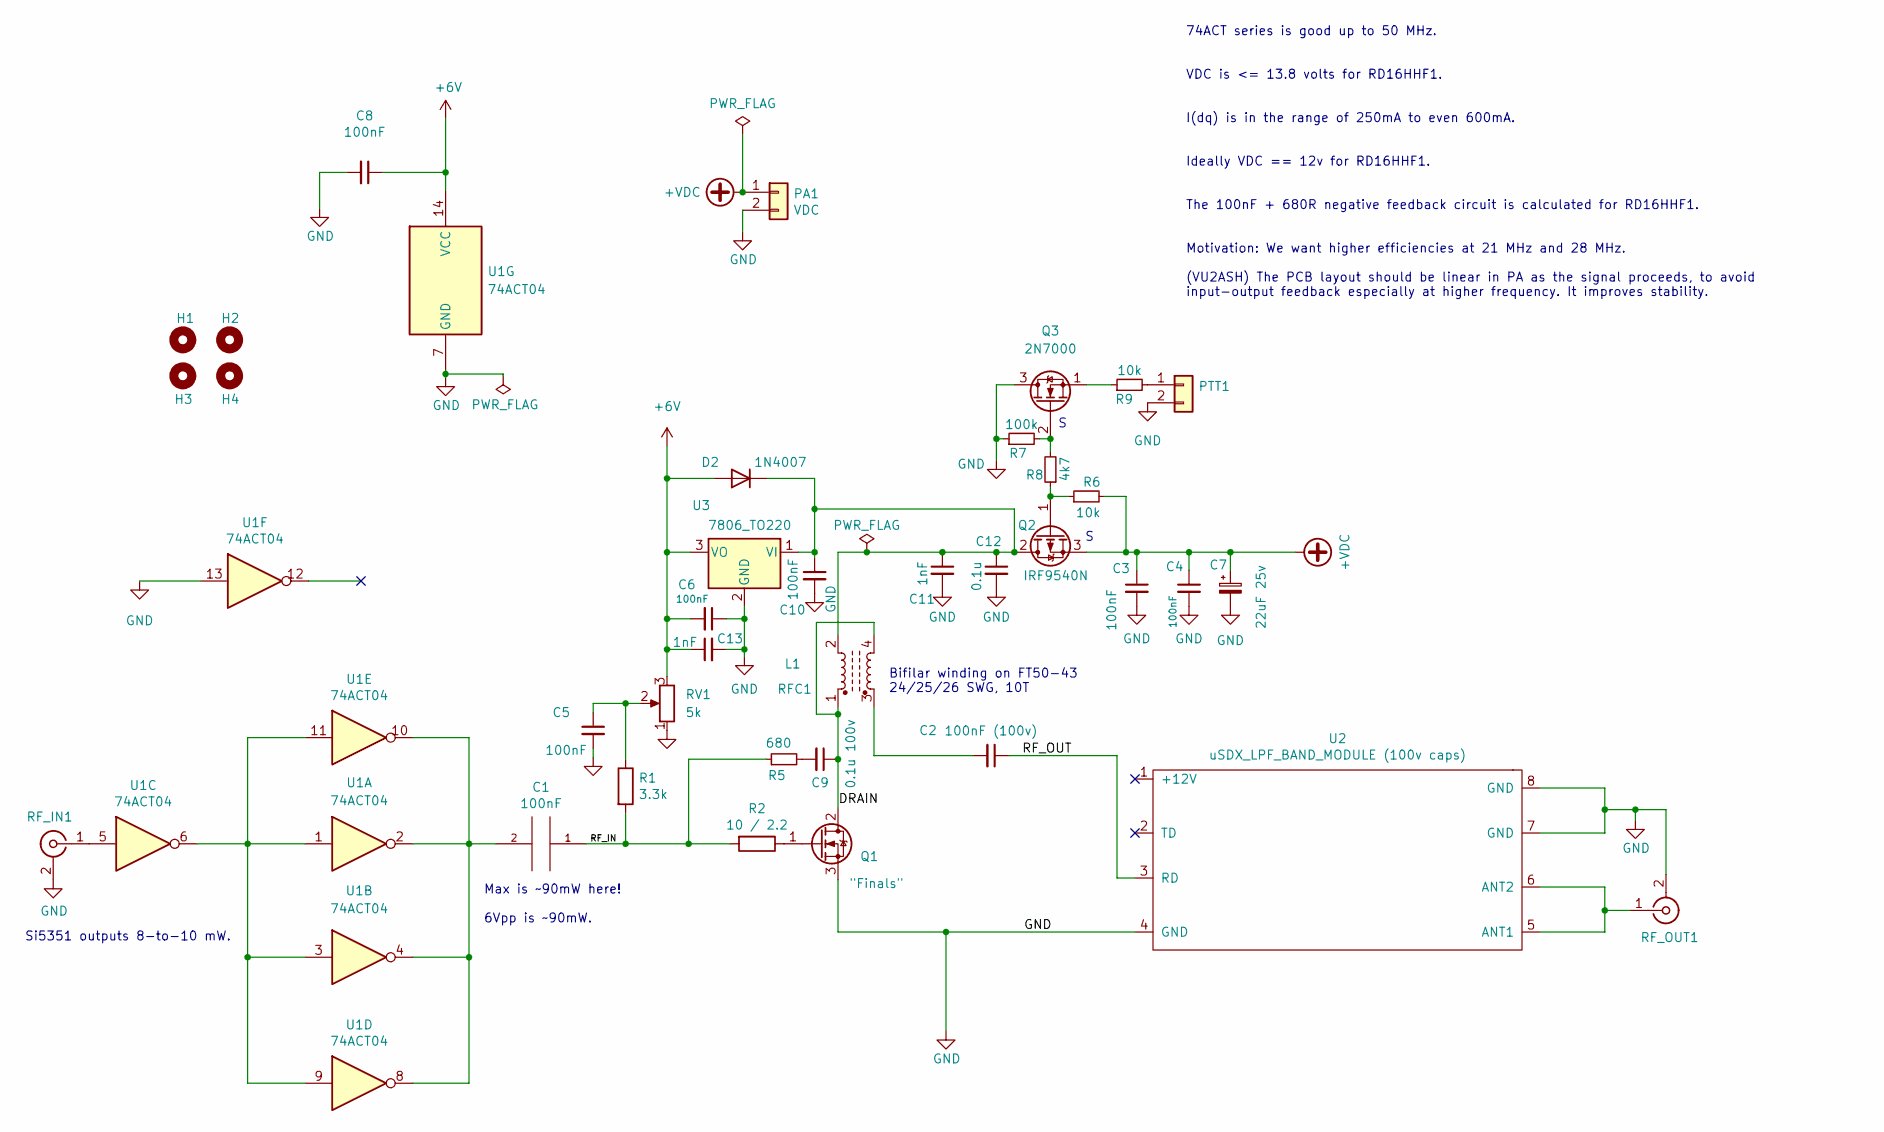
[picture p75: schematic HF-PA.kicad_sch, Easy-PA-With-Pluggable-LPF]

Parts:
C1, C3, C4, C5, C6, C8, C10: 100nF; C_Disc_D4.3mm_W1.9mm_P5.00mm
C2: 100nF (100v); C_Disc_D4.3mm_W1.9mm_P5.00mm
C7: 22uF 25v; CP_Radial_D5.0mm_P2.50mm
C9: 0.1u 100v; C_Disc_D4.3mm_W1.9mm_P5.00mm
C11, C13: 1nF; C_Disc_D4.3mm_W1.9mm_P5.00mm
C12: 0.1u; C_Disc_D4.3mm_W1.9mm_P5.00mm
D2: 1N4007; D_DO-41_SOD81_P2.54mm_Vertical_AnodeUp
H1, H2, H3, H4: MountingHole; MountingHole_2.2mm_M2
L1: RFC1; FT50-43 Transformer
PA1: VDC; PinHeader_1x02_P2.54mm_Vertical
PTT1: PTT; PinHeader_1x02_P2.54mm_Vertical
Q1: "Finals"; TO-220-3_Vertical
Q2: IRF9540N; TO-220-3_Vertical
Q3: 2N7000; PinSocket_1x03_P2.54mm_Vertical
R1: 3.3k; R_Axial_DIN0207_L6.3mm_D2.5mm_P2.54mm_Vertical
R2: 10 / 2.2; R_Axial_DIN0207_L6.3mm_D2.5mm_P2.54mm_Vertical
R5: 680; R_Axial_DIN0207_L6.3mm_D2.5mm_P2.54mm_Vertical
R6, R9: 10k; R_Axial_DIN0207_L6.3mm_D2.5mm_P2.54mm_Vertical
R7: 100k; R_Axial_DIN0207_L6.3mm_D2.5mm_P2.54mm_Vertical
R8: 4k7; R_Axial_DIN0207_L6.3mm_D2.5mm_P2.54mm_Vertical
RF_IN1: Conn_Coaxial; SMA_Amphenol_901-144_Vertical
RF_OUT1: Conn_Coaxial; SMA_Amphenol_901-144_Vertical
RV1: 5k; Potentiometer_Runtron_RM-065_Vertical_
U1: 74ACT04; DIP-14_W7.62mm_LongPads
U2: uSDX_LPF_BAND_MODULE (100v caps); uSDX_LPF_Band_Module
U3: 7806_TO220; TO-220-3_Vertical

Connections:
+6V: C6.2, C8.1, C13.1, D2.2 (A), RV1.3, U1.14 (VCC), U3.3 (VO)
+VDC: C3.1, C4.1, C7.1, PA1.1, Q2.3 (S), R6.2
/DRAIN: C9.1, L1.1, L1.4, Q1.2 (D)
/RF_IN: C1.1, R1.2, R2.2, R5.1
/RF_OUT: C2.1, U2.3 (RD)
GND: C3.2, C4.2, C5.2, C6.1, C7.2, C8.2, C10.2, C11.2, C12.2, C13.2, PA1.2, PTT1.2, Q1.3 (S), Q3.3 (D), R7.1, RF_IN1.2 (Ext), RF_OUT1.2 (Ext), RV1.1, U1.7 (GND), U1.13, U2.4 (GND), U2.7 (GND), U2.8 (GND), U3.2 (GND)
unnamed: C1.2, U1.2, U1.4, U1.8, U1.10
unnamed: C2.2, L1.3
unnamed: C5.1, R1.1, RV1.2
unnamed: C9.2, R5.2
unnamed: C10.1, C11.1, C12.1, D2.1 (K), L1.2, Q2.2 (D), U3.1 (VI)
unnamed: PTT1.1, R9.2
unnamed: Q1.1 (G), R2.1
unnamed: Q2.1 (G), R6.1, R8.1
unnamed: Q3.1 (S), R9.1
unnamed: Q3.2 (G), R7.2, R8.2
unnamed: RF_IN1.1 (In), U1.5
unnamed: RF_OUT1.1 (In), U2.5 (ANT1), U2.6 (ANT2)
unnamed: U1.1, U1.3, U1.6, U1.9, U1.11

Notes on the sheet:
74ACT series is good up to 50 MHz. VDC is <= 13.8 volts for RD16HHF1. I(dq) is in the range of 250mA to even 600mA. Ideally VDC == 12v for RD16HHF1. The 100nF + 680R negative feedback circuit is calculated for RD16HHF1. Motivation: We want higher efficiencies at 21 MHz and 28 MHz. (VU2ASH) The PCB 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
Max is ~90mW here! 6Vpp is ~90mW.
Si5351 outputs 8-to-10 mW.
Bifilar winding on FT50-43 24/25/26 SWG, 10T

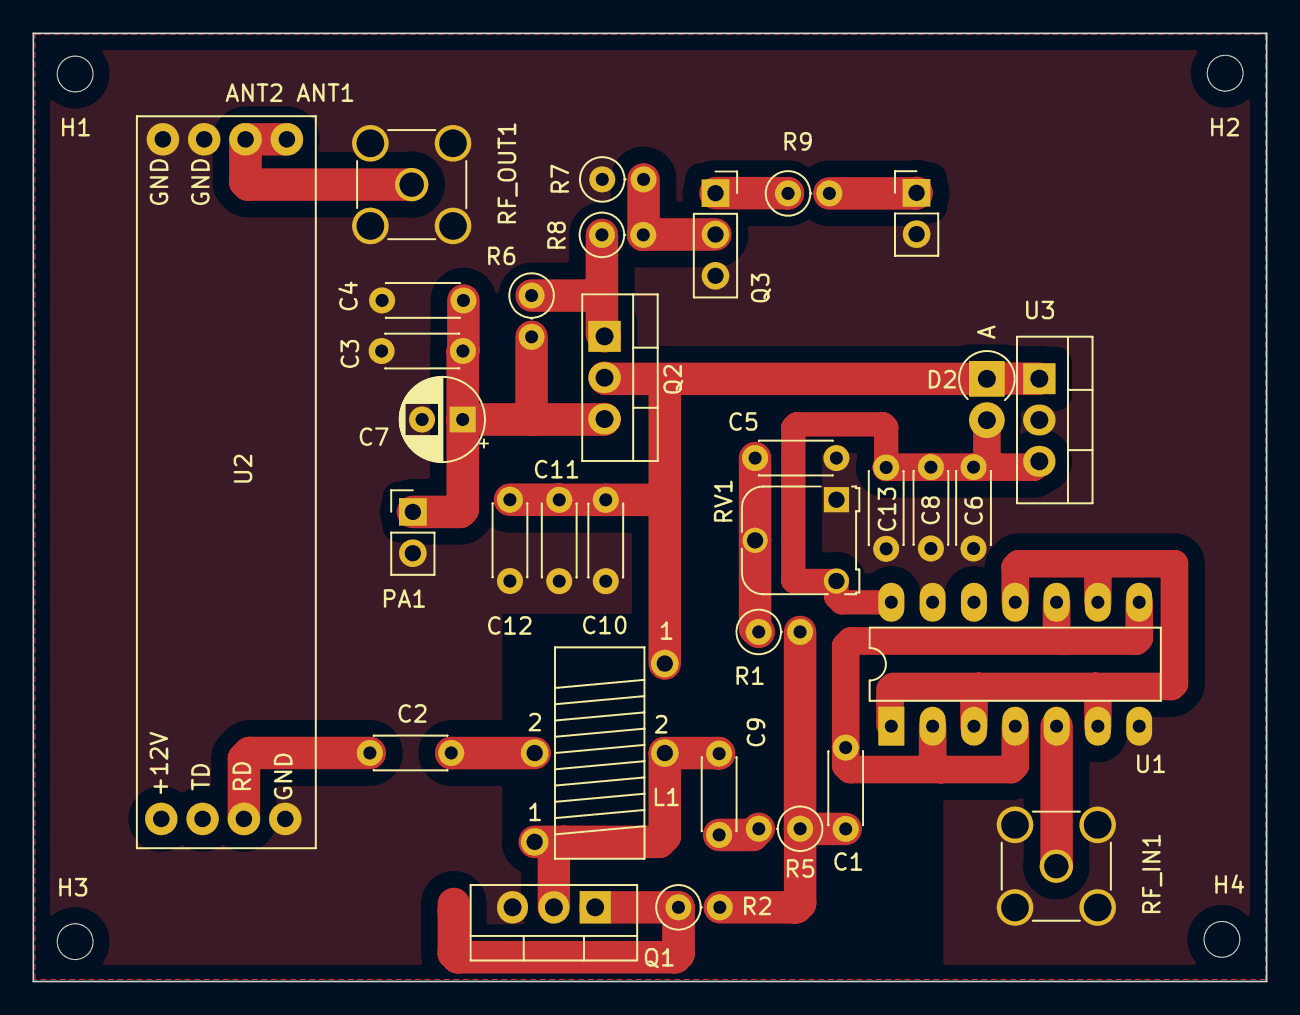
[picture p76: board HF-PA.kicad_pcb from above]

Board: 2 copper layers, 75.8 x 58.3 mm, 37 parts (0 on the bottom side), 19 nets.
